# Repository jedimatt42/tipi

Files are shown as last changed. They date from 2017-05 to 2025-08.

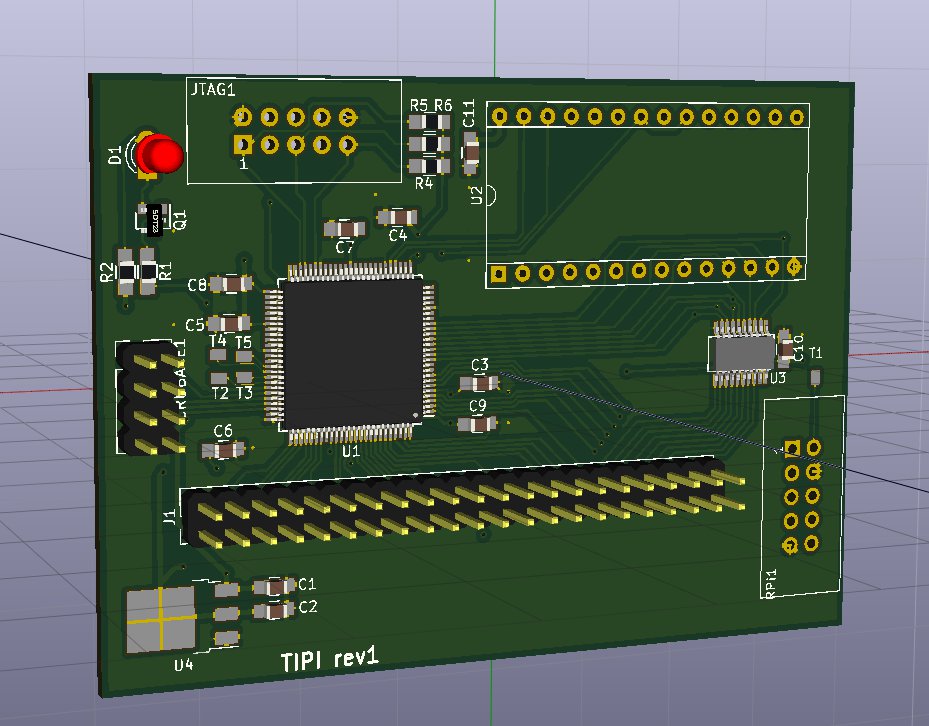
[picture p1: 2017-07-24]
hardware/tipi-sideport/kicad/pcboard.jpg

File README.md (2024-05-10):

# TIPI

(Pronounced tip-ee)

Turn a Raspberry PI and some glue hardware into a TI Disk Drive and Network interface. 

Keep it open for further device extension.

## Branching

(For end users starting from an SD card image, you are already on the correct branch)

- End users must be on one of the `_release` branches for physical TIPI
- `main` branch is full of stuff that doesn't work, won't upgrade correctly, and certainly won't downgrade
- `main` branch is expert mode only

Branches:

```
  main - current development for latest Raspberry PI OS
  bookworm_release - Current release branch based on Raspberry PI OS 12 - bookworm
  bullseye_release - (legacy) end of life, as new bookworm_release branch is available
  buster_dev - (legacy) for patching upstream of buster_release
  buster_release - (legacy) for Raspberry PI 2W - 4B+ or Qemu use.
```

## Documentation

Please refer to the [wiki](https://github.com/jedimatt42/tipi/wiki)

## License 

The hardware design files and TI-99 DSR ROM code are in the [hardware](hardware) folder and free for use under the [UNLICENSE.txt](hardware/UNLICENSE.txt) 

The remaining software contained in this repository are licensed under the terms of [GPLv3](https://www.gnu.org/licenses/quick-guide-gplv3.en.html)

These files are part of TIPI.

TIPI is free hardware design and software: you can redistribute it and/or modify it under the terms of the GNU General Public License as published by the Free Software Foundation, either version 3 of the License, or (at your option) any later version.

TIPI is distributed in the hope that it will be useful, but WITHOUT ANY WARRANTY; without even the implied warranty of MERCHANTABILITY or FITNESS FOR A PARTICULAR PURPOSE.  See the GNU General Public License for more details.

You should have received a copy of the GNU General Public License along with TIPI SD Card Image.  If not, see [GNU Licenses](http://www.gnu.org/licenses/).

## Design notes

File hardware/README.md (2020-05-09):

# Hardare design files for TIPI board and ROM driver software

This package below contains the hardware design files. These are un-encumbered open license files you can all do whatever you want with...

* tipi-peb - contains the PCB designs for the Periphal Expansion Box variant of the board. 
  * gerbers - artifacts for PCB fabrication
  * kicad - pcb schematic and layout design files for KiCad
  * ise - the verilog - Xilinx ISE 14.1 project files (use this with tipi-sideport design also)
* tipi-sideport - contains the PCB designs for the sideport board
  * gerbers - artifacts for PCB fabrication
  * kicad - pcb schematic and layout design files for KiCad
* tipi-speech - contains the PCB designs for the Speech Synthsizer Box variant of the TIPI board. 
  * gerbers - artifacts for PCB fabrication
  * kicad - pcb schematic and layout design files for KiCad
  * ise - the verilog - Xilinx ISE 14.1 project files (combined 32k and TIPI decoding)
* dsr - the ROM driver software for messaging to the PI and general DISK like behavior.

See [UNLICENSE.txt](UNLICENSE.txt)

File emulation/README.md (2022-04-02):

# TIPI support of popular emulators

TIPI is not an emulation of TI-99/4A hardware. It is a unique and independent implementation of storage, network, and other peripherals. Emulation in this context refers to TI-99/4A emulators that support TIPI features.

- js99er.net supports connecting to a running set of TIPI services either on a real Raspberry PI or through a QEMU based PI emulation running the real TIPI services.
- MAME v0.242 adds TIPI support: [Atariage MAME Release Thread](https://atariage.com/forums/topic/259551-new-mame-release/?do=findComment&comment=5032740)
- Classic99 implements some TIPI device and message level protocols directly. It is baked in. 

## Using QEMU

Run the emulation with the latest TIPI hardware sdimage.

1. Enable emulation mode, by running `/home/tipi/emulation/emu_config.sh` and responding to the prompts

2. Edit the `/etc/fstab` and delete the 3 TMPFS entries. The QEMU configuration does not have enough RAM for so much TMPFS usage.

3. Disable tipiwatchdog.service - it's not needed, and may crash since GPIO isn't actually available: `sudo systemctl disable tipiwatchdog.service`

4. exit the emulation clean: `sudo shutdown now`

### Options in the standard image that might need fixing

raspi-config should be run to change the locale, and 
keyboard defaults for the system

## Using a real PI

You can use a real PI, and the latest SD image. You will have to setup the networking following the Raspberry PI documentation: [headless network setup](https://www.raspberrypi.com/documentation/computers/configuration.html#setting-up-a-headless-raspberry-pi)

Be sure to touch the `ssh` file in the `boot` partition so sshd is enabled. Then you can get in and use raspi-config to setup locale, hostname, and other items.

Enable emulation mode, by running `/home/tipi/emulation/emu_config.sh` and responding to the prompts. On a real Raspberry PI, PDF conversion can be enabled, and you probably don't want tipi_disk mounted via NFS.

You should leave the tmpfs and other services as they are for a normal PI setup.

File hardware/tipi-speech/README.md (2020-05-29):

# Hardare design files for TIPI-32K board that fits in the Speech Synthesizer house and its unique CPLD code

This package below contains the hardware design files. These are un-encumbered open license files you can all do whatever you want with...

* kicad - contains the PCB designs for the sideport board
* gerbers - contains the PCB manufacturing files for this variant of the board. 
* ise - contains the Xilinx ISE 14.1 project CPLD design files and jedec output file this variant of the TIPI board. 

See [UNLICENSE.txt](UNLICENSE.txt)

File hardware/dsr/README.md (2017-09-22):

# DSR for TIPI

Right, now we have a very simple xdt99 based build system for creating a rom targetting >4000 that is comprised
of one or more .a99 source files. It produces tipi.bin, and the script bin2hex.py converts that to tipi.hex which
is a format that can be embedded/included in a verilog FPGA source file.

## Architecture

The code for the DSR is in two halves. TMS9900 assembly code (.a99 files) support the TI operating system by responding to
device PAB (Peripheral Access Block) requests. These are copied to the Raspberry PI through the hardware interface, and interpretted/handled by the python code. 

The Raspberry PI runs the 'TipiService.py' script as a systemd service. This script looks at the devicename, translates 
file names to matching local filesystem files, and supports OPEN, READ, CLOSE, and LOAD operations. SAVE, and WRITE are not implemented yet, as we work on stabilizing the hardware.

TipiPorts.py - low level interface to Raspberry PI GPIO pins.
TipiMessages.py - next level up, send or receive a bytearray
ti_files.py - utilities for validating the format of the hosted files, decoding the file meta-data, and extracting records
ti_names.py - translates TI names to host filesystem names. We ignore names in the TIFILES meta-data.
SpecialFiles.py - handles generation of psuedo files for read access like TIPI.CLOCK and TIPI.STATUS.
TipiService.py - the primary service script, that loops waiting for DSR requests. Opcode handling and Catalog handling is in here too.

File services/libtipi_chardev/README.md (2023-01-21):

# Native C to python interface for tipi via kernel module gpiod driver

Use /dev/tipi_control and /dev/tipi_data kernel module character devices to 
interact with TIPI adapter board for messaging.

Kernel module for your single board computer must already be installed.

# Building

```
virtualenv env
. env/bin/activate
pip install -r requirements.txt
python setup.py install
```

# Usage

TODO: Update with good info

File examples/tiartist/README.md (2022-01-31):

# TIPI TI Artist Plus Mouse Driver

This is a mouse driver to enable TIPI mouse with TI Artist Plus.

I don't know or expect it to be compatible with older versions of TI Artist.

## Finding TI Artist Plus

The version of TI Artist Plus I tested this with can be found here:

[whtech](http://ftp.whtech.com/graphics/Inscebot/)  in the disk image.

Extract as TIFILES into a folder on your TIPI named INSCEBOT.

Place the TIPIM file in the folder you extract the disk image into.
Copy aside EXTDSR to JOYST2 (it is different than existing JOYST)

Copy TIPIM to EXTDSR

Now Map DSK1 to the INSCEBOT folder. Plug a USB mouse into your
TIPI, and launch XB. 

## Usage

Left mouse button is fire-button. Rubber-banding is supported so for
tools except D-Draw, click and release, move to preview with rubber band, then click. For most cools, TI Artist warps you back to the
starting point on second click. 

Middle mouse button is space-menu. It activates on release of the button.

Right mouse button restricts movement to a single pixel, so in draw mode you'll never get gaps. But this is more of a throw-back UX compromise. You have to adjust how you move to get sweeping motions.

The speed will never be perfect, but it reminds me of back in the day. For best results use a low DPI mouse as you can find.

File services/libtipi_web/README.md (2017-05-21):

# Native C to python interface for tipi gpio

This library should encapsulate the GPIO routines required for interacting with the 
shift registers and data latches that are in the TIPI hardware, from the Raspberry PI
side of the interface. 

Using C instead of RPi.GPIO should be able to outpace the TI-99/4A, where the python
library is relatively slow. Benchmarks from 2015 showed RPi.GPIO operating at 70 Khz, 
where Native C operated at 22 Mhz. 

With the use of shift registers, we go from 8 IOs per byte to 28 IOs per byte. 
Consequently, the need for performance is real.

# Building

```
virtualenv env
. env/bin/activate
pip install -r requirements.txt
python setup.py install
```

# Usage

Example python usage of the library.

```
import tipiports

# initialize GPIO pins for TIPI
tipiports.initGpio()

# read control byte from TI
print tipiports.getTC()

# read data byte from TI
print tipiports.getTD()

# set data byte from RPi
tipiports.setRD()

# set control byte from RPi
tipiports.setRC()
```

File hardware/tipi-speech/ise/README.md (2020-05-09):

CPLD design files for VS-TIPI board 

This package below contains the CPLD design files. These are un-encumbered open license files you can all do whatever you want with...

           ise - the verilog - Xilinx ISE 14.1 project files (use this with VS-tipi design only)

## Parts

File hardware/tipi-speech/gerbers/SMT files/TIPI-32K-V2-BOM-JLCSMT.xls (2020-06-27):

Comment | Designator | Footprint | LCSC
10uf | C1 | 0805_C | C15850
22uf | C2 | 0805_C | C45783
0.1uf | C6,C10,C7,C8,C9,C5,C4,C3,C11,C12 | 0805_C | C49678
USB_B_Micro | J2 | AMPHENOL_10118194-0001LF | C132563
NPN_BCE | Q1 | SOT-23 | C31776
330R | R2 | 0805_R | C17630
1k | R3,R1 | 0805_R | C17513
10k | R5,R6,R4 | 0805_R | C17414
0R | R7 | 0805_R | C17477
XC95144XL-TQ100 | U1 | TQFP-100_14x14mm_Pitch0.5mm | C45126
74HCT245 | U3 | SSOP-20 | C5980
LM1117-3.3 | U4 | SOT-223 | C23984

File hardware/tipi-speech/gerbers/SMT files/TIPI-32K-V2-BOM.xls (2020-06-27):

TIPI-32K Rev 2 Bom | 2020-06-15
Comment | Designator | Footprint | LCSC | Qty | Cost | Ext. | Package | Description | Vendor | Primary Source | Alternate | LCSC
10uf | C1 | 0805_C | C15850 | 1 | $0.044 | $0.044 | SMT 0805_C | 10uf capacitor | JLCPCB or DigiKey | https://jlcpcb.com/parts/componentSearch?searchTxt=C15850 | https://www.digikey.com/product-detail/en/kemet/C0805C106K8PACTU/399-4925-1-ND/1090920 | C15850
22uf | C2 | 0805_C | C45783 | 1 | $0.158 | $0.158 | SMT 0805_C | 22uf capacitor | JLCPCB or DigiKey | https://jlcpcb.com/parts/componentSearch?searchTxt=C45783 | https://www.digikey.com/product-detail/en/samsung-electro-mechanics/CL21A226MOCLRNC/1276-6780-1-ND/5961639 | C45783
0.1uf | C5,C6,C8,C3,C4,C7,C9,C10,C11,C12 | 0805_C | C49678 | 10 | $0.012 | $0.123 | SMT 0805_C | 0.1uf capacitor | JLCPCB or DigiKey | https://jlcpcb.com/parts/componentSearch?searchTxt=C49678 | https://www.digikey.com/product-detail/en/avx-corporation/08055C104MAT2A/478-3351-1-ND/930143 | C49678
MMBT4401 | Q1 | SOT-23 | C31776 | 1 | $0.021 | $0.021 | SMT SOT-23 | MMBT4401LT1GOSCT-ND | JLCPCB or DigiKey | https://jlcpcb.com/parts/componentSearch?searchTxt=C31776 | https://www.digikey.com/product-detail/en/on-semiconductor/MMBT4401LT1G/MMBT4401LT1GOSCT-ND/1139819 | C31776
1k | R1,R3 | 0805_R | C17513 | 2 | $0.002 | $0.004 | SMT 0805_R | 1K resistor | JLCPCB or DigiKey | https://jlcpcb.com/parts/componentSearch?searchTxt=C17513 | https://www.digikey.com/product-detail/en/yageo/RC0805JR-071KL/311-1.0KARCT-ND/731165 | C17513
330 ohm | R2 | 0805_R | C17630 | 1 | $0.003 | $0.003 | SMT 0805_R | 330 Ohm resistor | JLCPCB or DigiKey | https://jlcpcb.com/parts/componentSearch?searchTxt=C17630 | https://www.digikey.com/product-detail/en/stackpole-electronics-inc/RMCF0805JT330R/RMCF0805JT330RCT-ND/1942547 | C17630
10k | R4,R5,R6 | 0805_R | C17414 | 3 | $0.009 | $0.027 | SMT 0805_R | 10K resistor | JLCPCB or DigiKey | https://jlcpcb.com/parts/componentSearch?searchTxt=C17414 | https://www.digikey.com/product-detail/en/yageo/RC0805JR-0710KL/311-10KARCT-ND/731188 | C17414
0 Ohm | R7 | 0805_R | C17477 | 1 | $0.009 | $0.009 | SMT 0805_R | 0 Ohm resistor | JLCPCB or DigiKey | https://jlcpcb.com/parts/componentSearch?searchTxt=C17477 | https://www.digikey.com/product-detail/en/yageo/RC0805JR-070RL/311-0-0ARCT-ND/731163 | C17477
XC95144XL | U1 | TQFP-100 | C45126 | 1 | $5.587 | $5.587 | SMT TQFP-100 14x14mm | XC95144XL-10TQG100C | JLCPCB or DigiKey | https://jlcpcb.com/parts/componentSearch?searchTxt=C45126 | https://www.digikey.com/product-detail/en/xilinx-inc/XC95144XL-10TQG100C/122-1372-ND/826975 | C45126
74HCT245 | U3 | TSSOP-20 | C5980 | 1 | $0.16 | $0.158 | SMT TSSOP-20 | 74HCT245PW | JLCPCB or DigiKey | https://jlcpcb.com/parts/componentSearch?searchTxt=C5980 | https://www.digikey.com/product-detail/en/nexperia-usa-inc/74HCT245PW,118/1727-6353-1-ND/2762864 | C5980
LM1117-3.3 | U4 | SOT-223 | C23984 | 1 | $0.480 | $0.480 | SMT SOT-223 | LM1117MPX-3.3/NOPB | JLCPCB or DigiKey | https://jlcpcb.com/parts/componentSearch?searchTxt=C23984 | https://www.digikey.com/product-detail/en/texas-instruments/LM1117MPX-3.3-NOPB/LM1117MPX-3.3-NOPBCT-ND/1010516 | C23984
 |  |  |  |  |  | $6.614 | SMT Parts Total (JLCPCB)
VS-Tipi.kicad_pcb | x-PCB |  |  | 1 | $0.830 | $0.830 | PCB 55 x 115 mm 2 layer | TIPI-32K-SS Raw PCB | JPLPCB or OshPark | https://jlcpcb.com//quote/gerberview/8dda1561-b2e0-43b6-8637-cdb665102ca1_1_0_1_0_0.html (https://jlcpcb.com/quote/gerberview/8dda1561-b2e0-43b6-8637-cdb665102ca1_1_0_1_0_0.html) |  | ;
 |  |  |  |  |  | $9.473 | SMT Populated CCA PCB Total |  | (Quoted at Qty 10 ~$10)
USB Micro socket | J2 | SMT USB Micro | C132563 | 1 | $0.290 | $0.290 | SMT USB Micro | Amphenol_10118194-0001LF‎ | DigiKey (jlcpcb won't smt) | https://www.digikey.com/product-detail/en/amphenol-icc-fci/10118194-0001LF/609-4618-1-ND/2785382 | https://lcsc.com/product-detail/USB-Connectors_Amphenol_10118194-0001LF_10118194-0001LF_C132563.html
LED_D3.0mm | D1 | Through Hole Hand Solder |  | 1 | $0.250 | $0.250 | LED 3.0mm | LED_ALT | DigiKey | https://www.digikey.com/product-detail/en/lite-on-inc/LTL-4221/160-1877-ND/3198524 | https://www.jameco.com/z/LHR2041-LED-Uni-Color-Red-660nm-2-Pin-T-1_206498.html
RPI_CONN_02X05 | RPi1 | Through Hole Hand Solder |  | 1 | $0.580 | $0.580 | Shrouded Headers 2x05 | CONN R/A 10POS | DigiKey | https://www.digikey.com/product-detail/en/cnc-tech/3020-10-0100-00/1175-1609-ND/3441723
CONN_02X04 | CRUBASE1 | Through Hole Hand Solder |  | 1 | $0.350 | $0.350 | Headers 2x04 | 02X04 header | DigiKey | https://www.digikey.com/product-detail/en/amphenol-fci/67996-408HLF/609-3391-ND/1487877
CONN_02X05 | JTAG1 | Through Hole Hand Solder |  | 1 | $0.280 | $0.280 | Headers 2x05 | 02X05 header | DigiKey | https://www.digikey.com/product-detail/en/amphenol-fci/67997-410HLF/609-3243-ND/1878475
CONN_01X02 | J3 | Through Hole Hand Solder |  | 1 | $0.280 | $0.280 | Headers 2x01 | 01X02 header | DigiKey | https://www.digikey.com/product-detail/en/amphenol-icc-fci/68000-102HLF/609-3500-ND/1493545
01x14 SIPsocket | U2a,U2b,U5a,U5b | Through Hole Hand Solder |  | 4 | $0.696 | $2.784 | Inline 14 pin sockets | 14 pin single row socket | DigiKey | https://www.digikey.com/product-detail/en/preci-dip/310-87-114-41-001101/1212-1101-ND/3757351 | https://www.jameco.com/webapp/wcs/stores/servlet/ProductDisplay?productId=175920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
AS6C62256-55PCN | U5 | Socketed Hand Inserted |  | 1 | $2.540 | $2.540 | DIP-28W | AS6C62256-55PCN | DigiKey | https://www.digikey.com/product-detail/en/alliance-memory-inc/AS6C62256-55PCN/1450-1033-ND/4234592 | https://www.jameco.com/z/CY62256L-70PC-Cypress-Semiconductor-SRAM-Chip-Asynchronous-Single-5-Volt-256k-Bit-32k-X-8-70ns-28-Pin-MDIP_391793.html
27C256 | U2 | Socketed Hand Inserted |  | 1 | $2.590 | $2.590 | DIP-28W | AM27C256 | eBay – hodge16 | https://www.ebay.com/itm/320526640071 | https://www.jameco.com/z/M27C256B-15F1-STMicroelectronics-IC-27C256B-15-EPROM-256K-Bit-150ns-UV-EPROM-and-OTP-EPROM_698111.html
TI-99_Sideport | J1 | Card Edge Hand Solder |  | 1 | $0.520 | $0.520 | 44 pin card edge connector | Card Edge Connector 44-pin | eBay – wonderco_buy | http://www.ebay.com/itm/5pc-Industrial-Card-Edge-Slot-Socket-Connector-22x2P-44P-2-54mm-0-1-3A-RoHS-/140888520037
 |  |  |  |  |  | $8.714 | DigiKey Parts Total
 |  |  |  |  |  | $9.894 | Hand-Placed Parts Total
 |  |  |  |  |  | $19.367 | Populated CCA Assembly BOM Cost
Pi Connector | Tall Board Connector for Pi ZeroW | Through Hole Hand Solder |  | 1 | $1.36 | $1.360 |  | ESW-105-23-T-D | DigiKey | https://www.digikey.com/product-detail/en/samtec-inc/ESW-105-23-T-D/SAM12534-ND/6692195 | https://www.digikey.com/product-detail/en/samtec-inc/ESW-105-12-G-D/SAM10467-ND/2651067
Raspberry Pi | Raspberry Pi ZeroW |  |  | 1 | $10.00 | $10.000 |  | DEV-14277 | Sparkfun/Adafruit/Canakit | https://www.sparkfun.com/products/14277 | https://www.canakit.com/raspberry-pi-zero-wireless.html
uSD card | 32GB micro SD card for Raspberry Pi |  |  | 1 | $5.64 | $5.640 |  | SDSDUNB-032G | Amazon | https://www.amazon.com/SanDisk-Ultra-UHS-I-Class-SDSDUNB-032G/dp/B07N16CDX3?rnid=2528832011
Housing | Speech Synthesizer Housing |  |  | 1 | $15.00 | $15.000 | (what I paid) | PHP1500 (used) | eBay | https://www.ebay.com/sch/i.html?_nkw=Ti%2099%204a%20Speech%20Synthesizer
 |  |  |  |  |  | $51.367 | Grand Total Bom Cost
 |  |  |  |  |  |  | * Does not include shipping

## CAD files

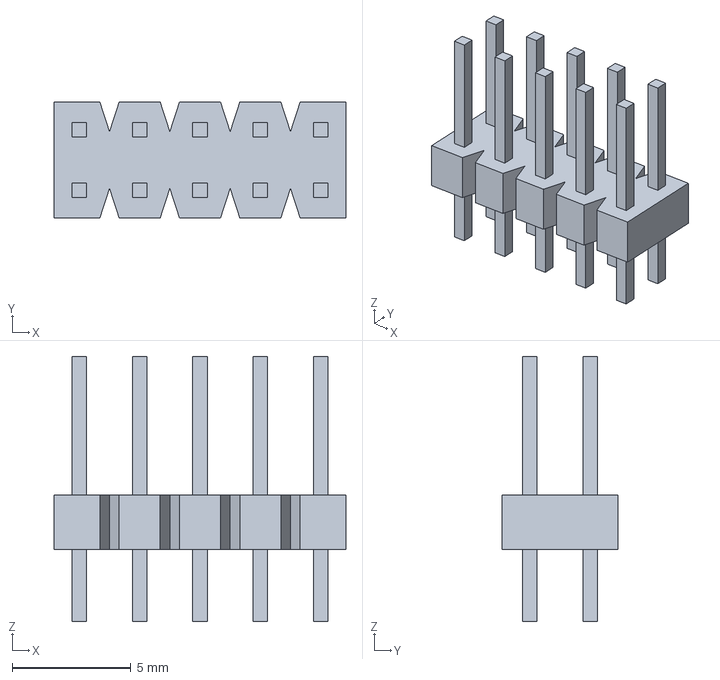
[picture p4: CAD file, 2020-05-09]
hardware/tipi-speech/kicad/3D/c-103186-5-g-3d.stp
12.3 x 4.88 x 11.2 mm

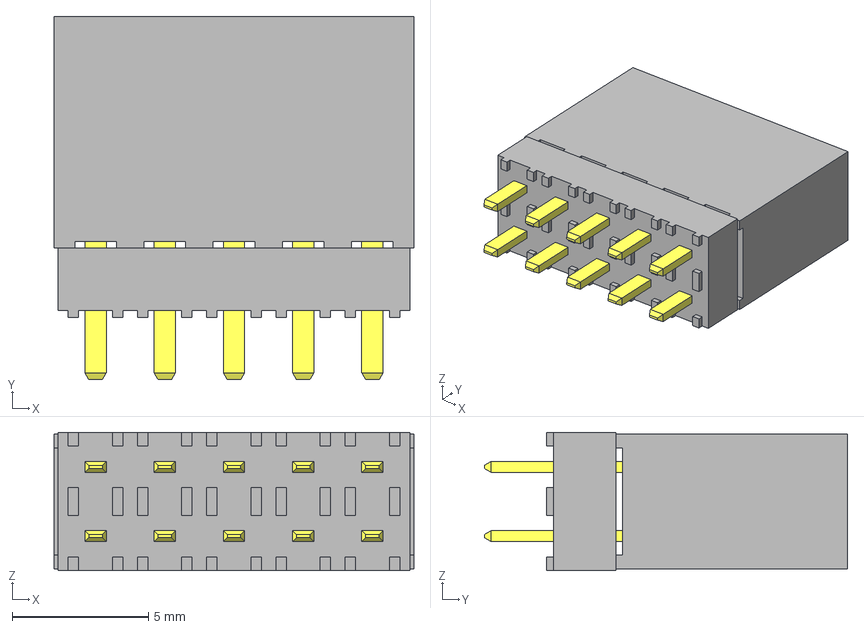
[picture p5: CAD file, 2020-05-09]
hardware/tipi-speech/kicad/3D/ESW-105-12-G-D.stp
13.2 x 13.3 x 5.08 mm
_ESW-105-12-G-D_socket
_ESW-105-12-G-D_pins
_ESW-105-12-G-D_bsocket

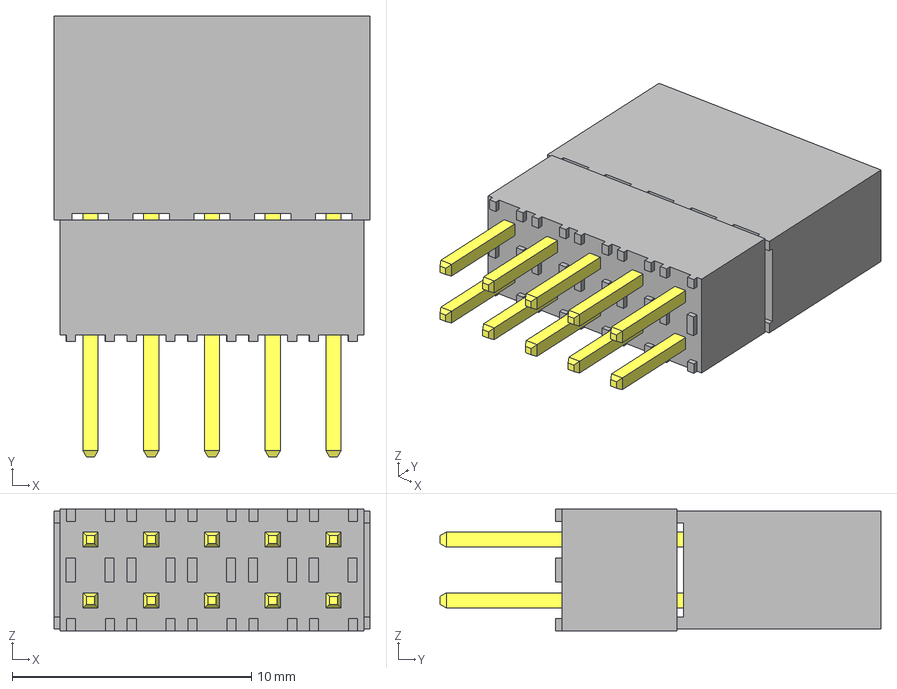
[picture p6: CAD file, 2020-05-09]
hardware/tipi-speech/kicad/3D/ESQ-105-23-G-D.stp
13.2 x 18.4 x 5.08 mm
_ESQ-105-23-G-D_socket
_ESQ-105-23-G-D_pins
_ESQ-105-23-G-D-LL_bpins

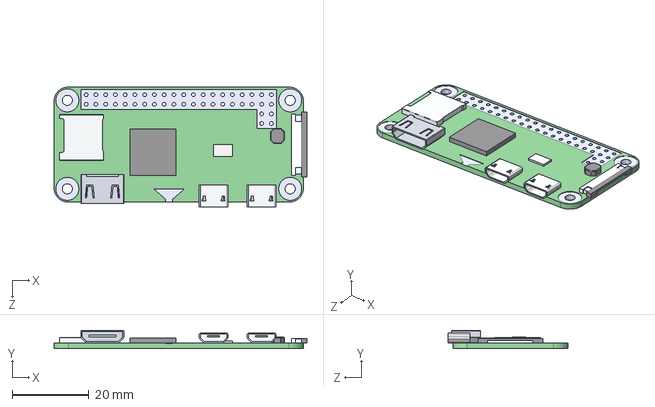
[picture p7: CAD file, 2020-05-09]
hardware/tipi-speech/kicad/3D/RaspberryPiZeroW.IGS
65.9 x 4.80 x 31.3 mm

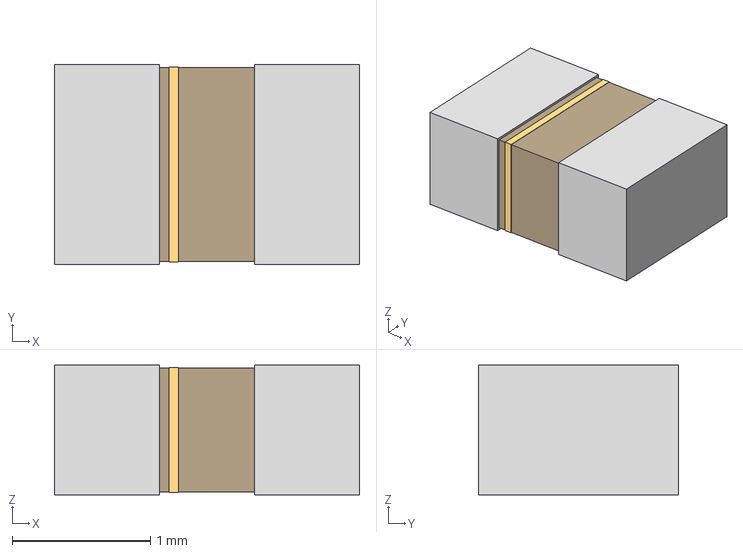
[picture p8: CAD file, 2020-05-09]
hardware/tipi-speech/kicad/3D/CAP_0805J_AVX.step
2.21 x 1.45 x 0.94 mm

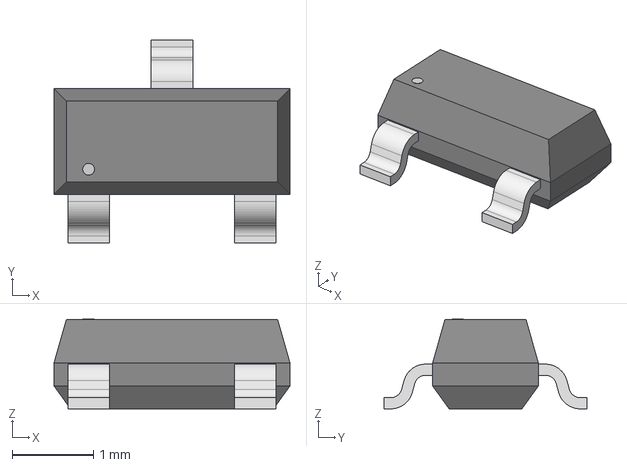
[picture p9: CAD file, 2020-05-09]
hardware/tipi-speech/kicad/3D/SOT-23_DIO-L.step
2.90 x 2.50 x 1.10 mm

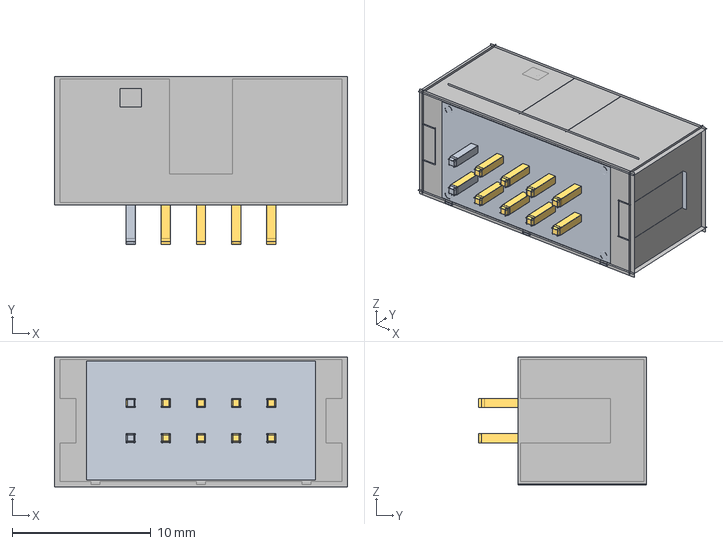
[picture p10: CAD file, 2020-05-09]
hardware/tipi-speech/kicad/3D/3020-10-0100-xx.igs
21.1 x 12.1 x 9.36 mm

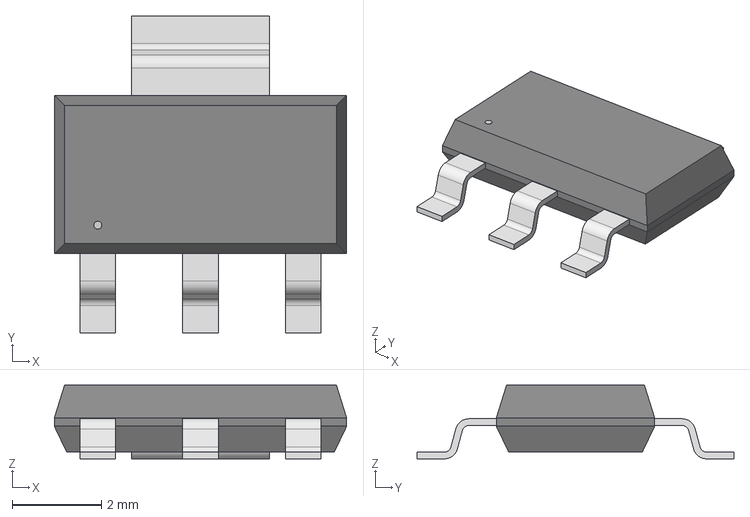
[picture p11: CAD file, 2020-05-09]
hardware/tipi-speech/kicad/3D/SOT-223_DIO.step
6.55 x 7.10 x 1.65 mm

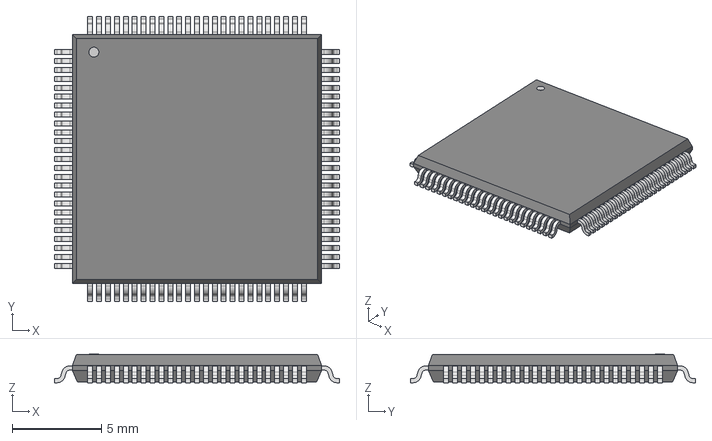
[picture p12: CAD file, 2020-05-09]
hardware/tipi-speech/kicad/3D/100-TQFP.step
16.0 x 16.0 x 1.60 mm

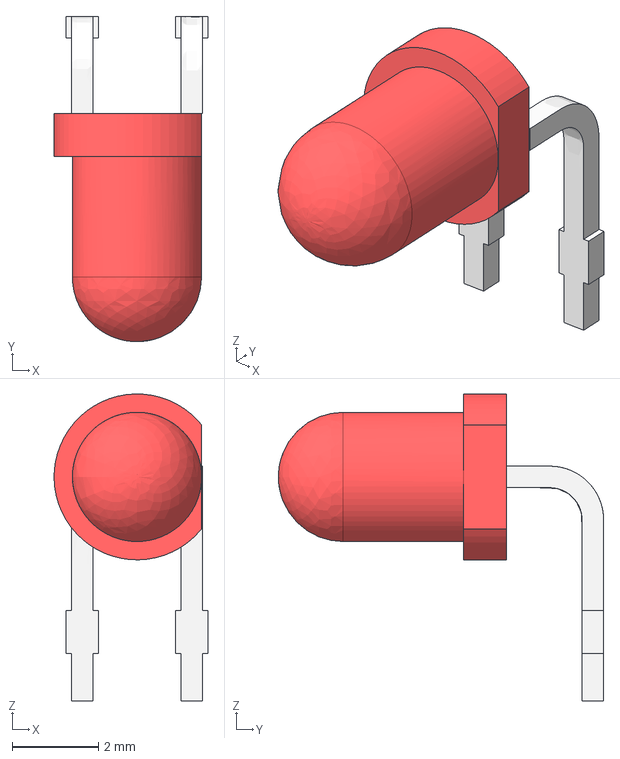
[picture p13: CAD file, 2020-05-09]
hardware/tipi-speech/kicad/3D/LED 3mm, Red, Thru-hole, Right Angle PCB 2.stp
3.57 x 7.55 x 7.12 mm

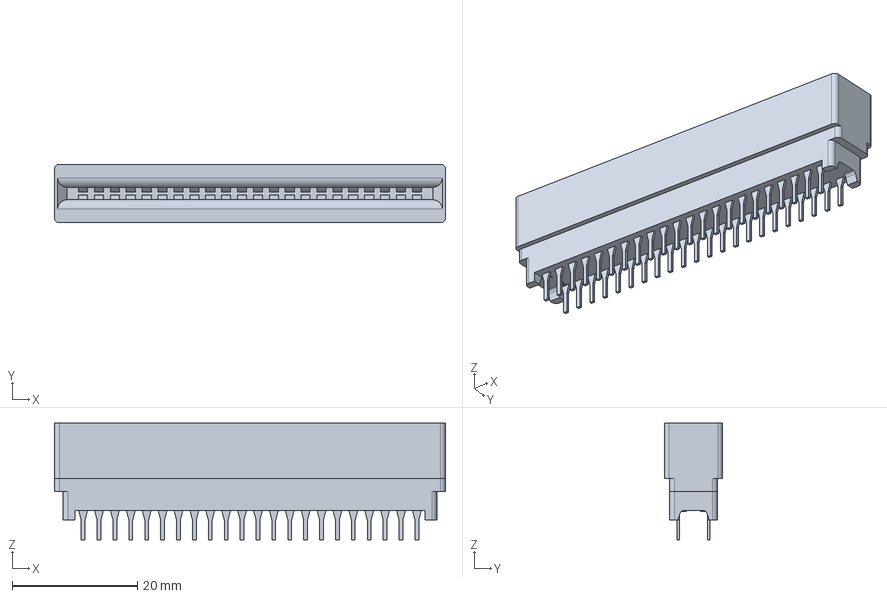
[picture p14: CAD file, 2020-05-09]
hardware/tipi-speech/kicad/3D/c-5530843-4-f-3d.stp
62.5 x 9.35 x 18.7 mm

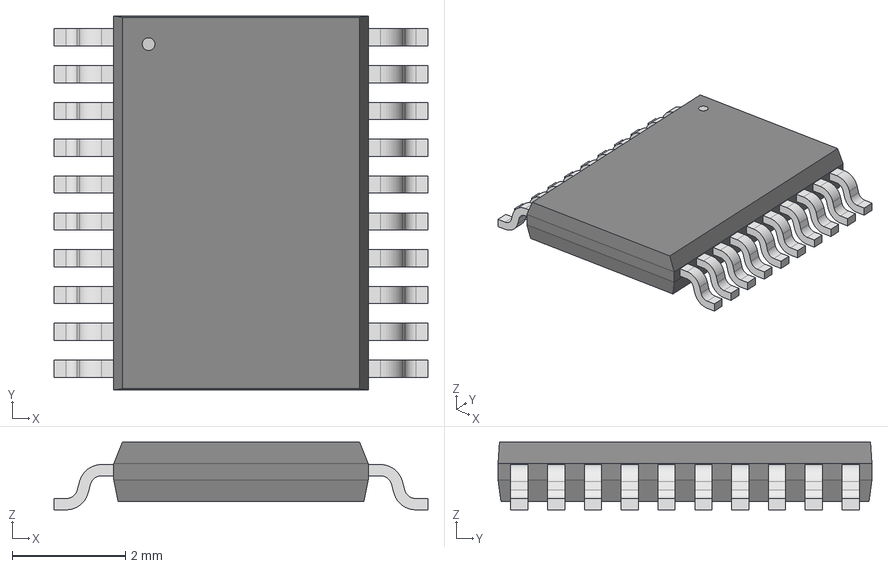
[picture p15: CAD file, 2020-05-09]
hardware/tipi-speech/kicad/3D/PW20.step
6.60 x 6.60 x 1.20 mm

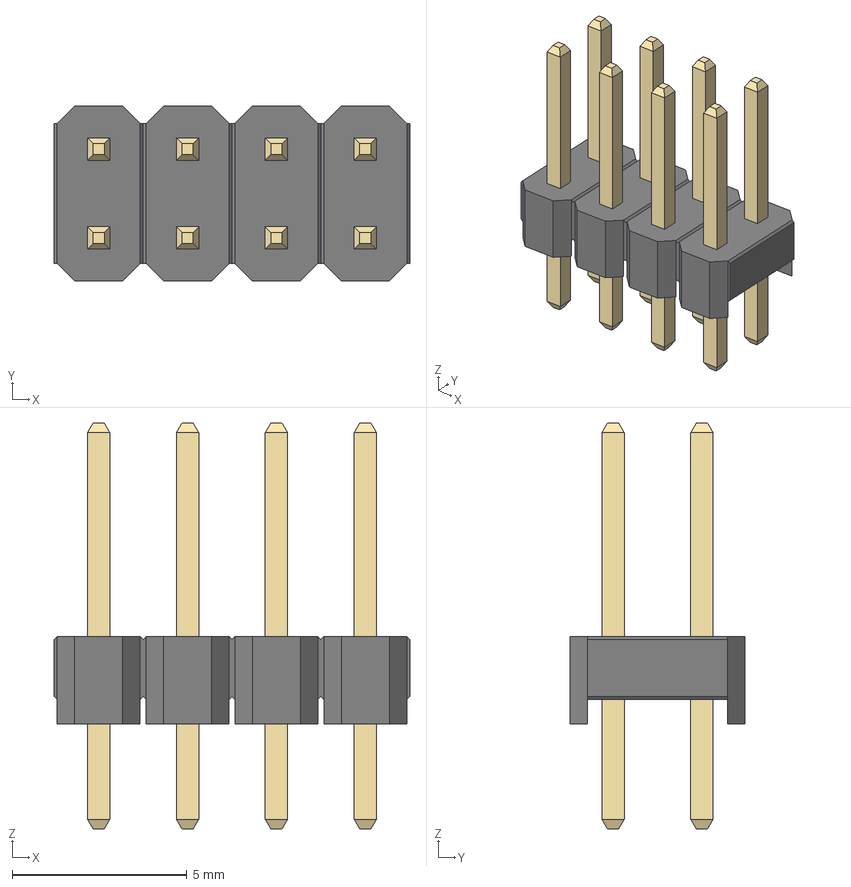
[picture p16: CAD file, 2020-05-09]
hardware/tipi-speech/kicad/3D/DS1021-2x4SF11.stp
10.2 x 5.00 x 11.6 mm

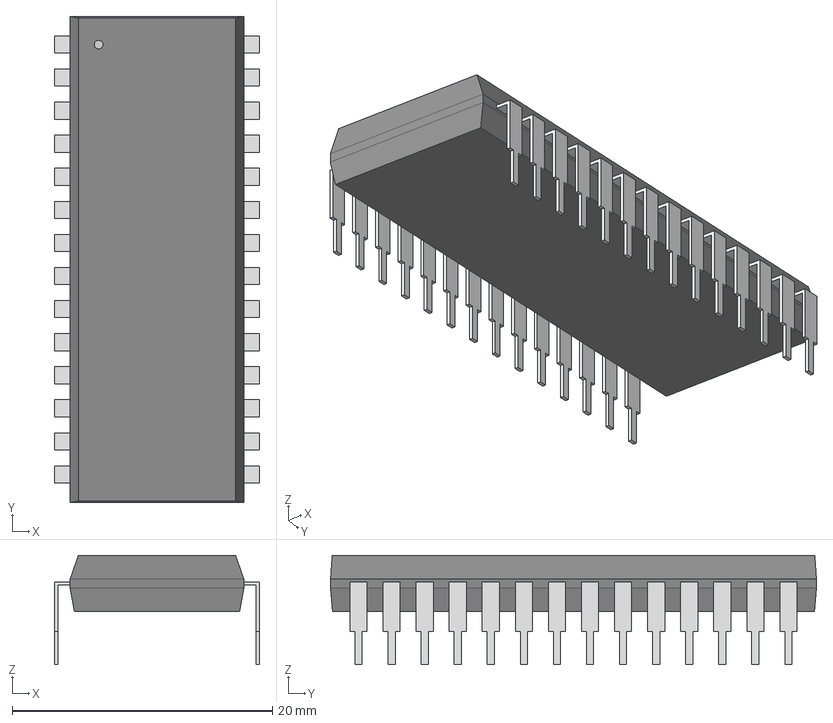
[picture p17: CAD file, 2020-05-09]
hardware/tipi-speech/kicad/3D/FDIP28WB.step
15.7 x 37.3 x 8.38 mm

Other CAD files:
hardware/tipi-speech/kicad/3D/10-Pin Shrouded Header (IDC) Straight.stp
hardware/tipi-speech/kicad/3D/DS1021-2x5SF11.stp
hardware/tipi-speech/kicad/3D/RC0805N.step
hardware/tipi-speech/kicad/3D/67996-408HLF_AMP.step
hardware/tipi-speech/kicad/3D/10118194c.stp
hardware/tipi-speech/kicad/3D/87215-5.step

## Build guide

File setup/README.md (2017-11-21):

# Services and setup

This folder contains the systemd service definitions and scripts around service
setup, and upgrade.

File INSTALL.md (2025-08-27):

# Setting up...

## If using the SD-Card image the steps in this document have already been performed.

SD Card image is available for download: 

[www.jedimatt42.com](https://www.jedimatt42.com/downloads.html)

Go to the [Wiki](https://github.com/jedimatt42/tipi/wiki) for end user installation.

# Only follow these instructions if you are setting up an SD Card from scratch.

Assumes base image is Raspbian Lite (bookworm)

## Pre-boot setup

Before booting the Raspbian SD image, create a createuser.txt, enable ssh, enable wifi by
following the instructions from [raspberrypi.com](https://raspberrypi.com/documentation/computers/configuration.html#setting-up-a-headless-raspberry-pi)
The user you create should be named: tipi
The tipi user password should be: tipi

Use raspi-config to install locales and set default, en_US_utf8.
Note: installing all locales takes forever, and slows future updates.
install en-US-UTF8, en-GB-UTF8, de-DE-UTF8, and en-CA-UTF8

Use raspi-config to disable i2c so that gpio-shutdown can be enabled.

Use raspi-config to enable ssh, and grow the root filesystem.
reboot.

## Replace log and tmp folders with tmpfs to prolong SD card life

Add the following to /etc/fstab:

```
tmpfs    /tmp    tmpfs    defaults,noatime,nosuid,size=100m    0 0
tmpfs    /var/log    tmpfs    defaults,noatime,nosuid,mode=0755,size=100m    0 0
```

Cleanup files under those subdirectories, and mount the tmpfs filesystems.

```
sudo rm -r /tmp/*
sudo rm -r /var/log/*
```

Reboot

```
sudo reboot now
```

## Install Software

Make sure git is installed (after setting up tmpfs folders, update will be required)

```
sudo apt update
sudo apt upgrade
sudo apt install git
```

## Install services

Setup the services, by becoming the 'tipi' user, cloning the git repository 
within the 'tipi' user home directory, and running the setup.sh script.

While executing the following, when prompted for a 'sudo' password, it 
is for the 'tipi' user.

Install the tipi kernel module

```
cd /home/tipi
git clone https://github.com/jedimatt42/tipi_kernel_module.git
cd tipi_kernel_module
sudo apt install raspberrypi-kernel-headers
./build.sh
sudo ./install.sh
sudo reboot now
```

NOTE: The ./install.sh step will fail to copy the overlay on a Le Potato
      Check the Le Potato section of the tipi_kernel_module/README.md 

Install the tipi services

```
cd /home/tipi
git clone https://github.com/jedimatt42/tipi.git tipi
cd /home/tipi/tipi
git checkout bookworm_release
git submodule update --init
./setup.sh
```

And run the post-upgrade to finish all the incremental configuration

```
cd setup
sudo ./post-upgrade.sh
```

NOTE: On Le Potato some parts of post-upgrade do not work. Completely...

## Other items to setup

* add tipi account to samba, and set password to 'tipi'

```
sudo smbpasswd -a tipi
```

* change the hostname (raspi-config)

Use raspi-config to set hostname to: `tipi`

## Test WIFI Connectivity

Make sure wifi was working before archiving the image. 

## Disable apache2.service

I don't know why this keeps coming back... but disable it as it fails to start and is 
not used.

```
sudo systemctl disable apache2.service
```

### Set the system to grow on boot

-- To be nice, set the image to resize on next boot 

edit the cmdline.txt in boot. Place the following at the end:
```
init=/usr/lib/raspi-config/init_resize.sh
```

Don't reboot, just shutdown.

### Capture SD Card Image

On a linux system dump the sdcard to an image. Then mount the image and clear unused blocks before zipping.

run dmesg to see what device sd card mounted as... presuming it was /dev/sdb:

```
sudo dd status=progress if=/dev/sdb of=sdimage.img bs=4M
sudo kpartx -a sdimage.img
```

You should be able to now mount the rootfs, or /dev/mapper/loop??p2.  On ubuntu like desktops the volume names will show up in the UI for removable media... 

Edit and Remove personal settings found in
- /home/tipi/tipi.config
- /etc/wpa_supplicant/wpa_supplicant.conf
- /home/tipi/.ssh/*

Then clear the space:

```
cd /media/`whoami`/rootfs
sudo dd status=progress if=/dev/zero of=zeroes bs=4M
sudo sync
sudo rm zeroes
cd
umount /media/`whoami`/rootfs
sudo kpartx -d sdimage.img
```

Now zip it up!

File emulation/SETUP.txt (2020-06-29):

== TIPI For Emulation

This bundle allows using js99er.net TI-99/4A emulation
with an emulated Raspberry PI running the TIPI 
peripheral services.

=== Setup

Download and install QEMU:

* https://www.qemu.org/download/#windows

1: Run nfs_tipi_disk.bat to start NFS server
2: Run tipi-qemu.bat to start TIPI emulation

=== NFS is optional

If you want your TIFILES to live in the tipi_disk folder on your
host operating system, run the nfs_tipi_disk.bat. This will start
WinNfsd.exe and export the .\tipi_disk folder as the nfs mount
localhost:/tipi_disk

When the emulation starts up, the default TIPI support programs
TELNET and TIPICFG will be installed into that folder.

If wish to leave the tipi_disk inside the sd_image, do nothing.
That is the default.. you can still use the web ui at localhost:9900 
to manage your TIFILES.

=== SSH

If you don't like the QEMU terminal, you can SSH in via localhost:9922
as the user 'tipi' password 'tipi'

That means you can also use scp and sftp clients to manage files.

=== Shutdown

use good linux shutdown practices:

command line: sudo shutdown now
TIPI web-ui: there is a shutdown item in the left most menu
4A/emulation: CALL TIPI from basic, 'h' to halt the PI

wait a bit... on the QEMU console you'll see an indication that
halt failed. ( that means it is done, but the hardware can't power off )
you can then just close the window.

=== The Bad News

PI.PIO has been reduced so it doesn't fail. It will produce .prn files in 
the PI emulations /tmp directory. However, the PDF conversion just crashes
out.. so this has been disabled. 

== Recognition

Big thanks to PeteE of Atariage for reducing the TIPI hardware to a
web-socket. 

Equally large thanks to Asmusr of Atariage for js99er and the integration work.

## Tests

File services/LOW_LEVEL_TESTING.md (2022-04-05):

# Low Level Testing

on the raspberry pi stop the tipi and tipiwatchdog services:

```
sudo systemctl stop tipi.service
sudo systemctl stop tipiwatchdog.service
```

go to the tipi services folder and enter into the virtual env:

```
cd ~/tipi/services
. ENV/bin/activate
```

Boot your 4A/Geneve and go to MiniMem and enter Easy Bug

Then on the PI start the diagnostic tool:

```
export TIPI_SIG_DELAY=100
python TipiDebug.py
```

It will print out that it is setting some addresses on the TI
to specific values.

It then loops every 5 seconds and prints the values of memory
addresses it can read from the TI.

Check those addresses in EasyBug. If your crubase is >1000:

At the '?' prompt enter the cru command: 'C1000' and press enter.
then enter '1', and '.', the transcript will look like:
(you might want C1100 or whatever crubase your TIPI is set to)

```
?C1000
 C1000  =00  -> 1
 C1001  =01  -> .
```

Now, investigate the values set by the PI test tool:
Enter "M5FF9" and press enter 4 times. Transcript:

```
?M5FF9
 M5FF9  = 5A  ->
 M5FFA  = 00  ->
 M5FFB  = A5  ->
 M5FFC  = 00  ->
```

The tool should be printing on the PI the output of the 
addresses 5FFD and 5FFF, so go down to 5FFD by pressing
enter again, and then set the value to '81', enter again
to skip to 5FFF, and set the value to 'FF'

Transcript in Easy bug will look like:

```
 M5FFD  =00  -> 81
 M5FFE  =00  ->
 M5FFF  =00  -> FF
 M6000  =AA  ->
```

On the PI you should see your 81 and FF values show up.

Likely output on the PI will look like (if it's working)

```
wrote M5FF9: 0x5A, M5FFB: 0xA5
read M5FFD: 0x00, M5FFF: 0x0
...
read M5FFD: 0x81, M5FFF: 0xff
...
```

This is as low as we can go without a signal analyzer.

If you get some muddled values back, you can try 
increasing the value of TIPI_SIG_DELAY and rerun
the script.

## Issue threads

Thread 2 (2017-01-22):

Revision 4 schematic A3 should always be 1.

jedimatt42, 2017-01-22:
The comparator is wired to A3-A6, but it should be A4-A7. And in cru selection, A3 must be HIGH.

jedimatt42, 2017-01-22:
fixed in master - #3

Closed 2017-01-22.

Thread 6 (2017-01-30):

Xc9500 schematic DSR rom addressing is backwards

jedimatt42, 2017-01-30:
The address line hook up to the rom is not right.

A0 on rom is LSb, should be ti A15. Banking lines should be rom A13 and A14

-M@

jedimatt42, 2017-02-05:
Fixed in master.

Closed 2017-02-05.

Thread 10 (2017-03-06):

Reset switch

jedimatt42, 2017-03-06:
There should be a soft reset for the TI related services on the RPi, controlled by one of the GPIO pins.

The 4A could also trigger this with a powerup routine so things are in known state with every reboot.

jedimatt42, 2017-04-22:
For development, I had the reset triggered on the TI RESET* signal, but it wasn't stable on my breadboard.

So I disconnected that, and used a physical button instead.
In the final design, a crubit should also drive this RPi signal so we can trigger the reset in the TI power up routine.

jedimatt42, 2017-05-16:
Done

Closed 2017-05-16.

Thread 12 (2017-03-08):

We can reduce the output pins to the RPI as by using a register select.

jedimatt42, 2017-03-08:
The RPi side doesn't need 16 GPIO pins dedicated to reading 2 8-bit registers. We can reduce the number of pins on the target CPLD and leave pins open on the RPi.

Use 1 register select pin, if HIGH, the TI Data register is selected, if LOW the TI Control register is selected. then 8 pins for the parallel output of the register.

That's a 7 pin reduction.

jedimatt42, 2017-04-22:
This worked like a champ!

Closed 2017-04-22.

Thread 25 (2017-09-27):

EMPTY DV80 file is not cataloged.

jedimatt42, 2017-09-27:
[EMPTY.zip](https://github.com/jedimatt42/tipi/files/1335814/EMPTY.zip)

The attached file contains a DV80 file with zero records... created by:
$ touch empty.txt
$ xdm99.py -T empty.txt -f "DIS/VAR80" -n EMPTY -o EMPTY

I can successfully load it into editor/assembler (Fred Kaal's EA5) but the CatalogFile is omitting it... I must have broken something.

jedimatt42, 2017-09-30:
Fixed... > 128 should have been >= 128... a header with no data is a valid TIFILES file

Closed 2017-09-30.

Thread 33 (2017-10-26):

tipi.service can't access some resources

ElectricLab, 2017-10-26:
The latest version of tipi.service has tipi.sh running as user: tipi. Is this correct? If so, did you chmod the following devices to be readable/writeable by the tipi user:
/dev/mem
/dev/gpiomem
Or maybe you addded 'tipi' to kmem and gpio groups?
The service won't start otherwise.

jedimatt42, 2017-10-26:
I added the tipi user to the gpio group as noted in https://github.com/jedimatt42/tipi/blob/master/dsr/python/README.md

the tipi user is only in the groups:
  tipi
  i2c
  input
  gpio

ElectricLab, 2017-10-26:
Ok - I guess I didn't read that README.md.
When I ran tipi.sh as the tipi user, I got:
/home/tipi/tipi/dsr/python/tipi.sh
wiringPiSetup: Unable to open /dev/mem or /dev/gpiomem: Permission denied.

The permissions on those devices are:
crw-r----- 1 root kmem 1, 1 Oct 25 22:09 /dev/mem
crw-rw---- 1 root gpio 243, 0 Oct 25 22:09 /dev/gpiomem

So it makes sense that adding tipi to gpio works, but not sure about /dev/mem.

jedimatt42, 2017-10-29:
you shouldn't need access to /dev/mem   because we are using /dev/gpiomem.  The error message is offering alternatives.

jedimatt42, 2017-11-18:
I take Pete's testing to show that this is all cleared up.

Closed 2017-11-18.

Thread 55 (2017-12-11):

WEB UI About box needs details

jedimatt42, 2017-12-11:
Should show Current and Latest version information from output of  /home/tipi/tipi/services/setup/upgrade.sh

Should show attribution:

Includes Ralph Benzinger's xdt99 suite  - https://github.com/endlos99/xdt99/blob/master/COPYING
Based on the Raspberry PI Raspbian Lite image - https://www.raspberrypi.org/downloads/raspbian/

jedimatt42, 2018-02-11:
fixed... shows current info and links to license on github which contains attribution details

Closed 2018-02-11.

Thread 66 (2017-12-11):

DSK?_DIR should represent the volume name somehow

jedimatt42, 2017-12-11:
DEADLINE loader expects and validates the volume name of the disk...

Suggestion is that the last part of the path name should be reported as the volume name when directories are mapped to DSK?_DIR entries.

arcadeshopper, 2017-12-11:
either that or set it in a file in the directory if that's easier.. like .VOLNAME or something

jedimatt42, 2017-12-25:
TIPI.anthing.more.whatever  volume name will be TIPI
DSK0.anything.more.whatever volume name will be TIPI
DSK1.anything... volume name will be basename of directory DSK1_DIR is mapped to:
So, if DSK1_DIR=GAMES.DEADLINE, then DSK1 volume name will be DEADLINE
In this case, DSK1.SAVES. volume name would still be DEADLINE. Meaning volume name will be tied to the drive mapping, not the directory you currently listing.

Closed 2017-12-25.

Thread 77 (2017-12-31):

Loading TIPI.TIPICFG hangs the TI for a few folks.

jedimatt42, 2017-12-31:
Greg said he wasn't patient enough...
Leonard said it hung, and then after a reboot of the 4a it was fine.

jedimatt42, 2018-04-01:
We have seen a hang as recent as Mar 29th 2018.

Hangs today seem to be due to noise on the lines connecting the PI to the TIPI board.  I don't have a good solution for this.

We have added a parity bit to the communication protocol that should retry if a single bit ( or odd number of bits ) error occurs.  This fixed all errors for me in my 'clean' environment.

Next, Greg still had lots of errors.. But eliminating / trading speech synthesizers, removed most.

Third, we lowered the transfer rate from 8k/sec to 6k/sec.  48000bps equivalent.  This has solved the issue in Greg's 'noisy' environment.

How 'clean' and how 'noisy' are not really known... It was not measured.   PI-Zero-W with a more direct link to the back of the TIPI board show results consistent with this theory, having a much shorter signal line, and being slower, we don't see noise related errors.

jedimatt42, 2018-05-29:
field testing hasn't shown any concern over this. And now we have a couple technical tuning options.

Closed 2018-05-29.

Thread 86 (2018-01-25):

when editing a text file on the ti, changes aren't written to the file completely

arcadeshopper, 2018-01-25:
using ea editor and preditor both i removed 50 lines from a text file and saved it only to find the lines still there on the file.. my specific line changes seemed to save at the top, but the erased lines did not

jedimatt42, 2018-01-26:
That's a cool bug! We could have gone years without noticing that.

arcadeshopper, 2018-01-26:
additional info, when editing a file with ea editor it seems to add a bunch of garbage to the eof as well I just "saved as" auto-bat2 with my shortened file, that worked fine.. then i edited it to switch the order of events and got this after saving:
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

jedimatt42, 2018-02-11:
fixed

arcadeshopper, 2018-02-12:
still getting the same garbage in the file as above

Closed 2018-02-11.

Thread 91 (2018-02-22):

in xb call load("DSK.THE_VALLEY.FILENAME") gives an error 00

arcadeshopper, 2018-02-22:
program is here: http://www.stuartconner.me.uk/ti/ti.htm#the_valley

works fine for old and run commands but not call load
¯\_(ツ)_/¯

jedimatt42, 2018-02-23:
call load works fine... but in this game, the file is a v9t9 file, and when extracted from disk image to host filesystem it is being named VALLEY(UPPERBAR)O. The software is trying to load VALLEY/O

Now, the host filesystem is where the name is... TIPI does not look in headers for names, so you don't have that confusion... once forget what you know about PC99 or V9T9.  If you rename a file that is the name it has.

The only exception to that is / and \  characters are allowed in TI names, but not allowed on the host filesystem... so to create a file on the host file system that can be found by TI looking for a /, use a '.'  (period)   so in this case, name the file VALLEY.O

I'll keep this open though, because... my goal is that when you upload a V9T9 file through the webui, it fixes this for you automatically.

---

I experience another problem running this game after it loads the assembly object file.  "STRING TRUNCATED IN 16030"  which is I think assembly code also embedded in the XB "RUN" program file.

jedimatt42, 2020-07-23:
When the disk extracts, it names the files correctly now.

jedimatt42, 2020-07-23:
The game actually works from TIPI, if the TIPI crubase is >1100 ( emulating floppy ) --- so the call files routine must be required.

Closed 2020-07-23.

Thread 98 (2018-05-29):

TELNET cursor in 64 column mode is broken.

jedimatt42, 2018-05-29:
Reading the character from the VDP isn't going to work in bitmap mode.

docbain, 2021-07-07:
I installed Raspberry Pi 4 to my TI using the PEB card set at CRU >1000. It connects to my network with IP address, however, when I attempt to CALL TIPI("TIPI.NET.TELNET"), my TI returns to the logo screen. What am I doing wrong. Also, there is a 10 pin connector on the card identical to the connector on the rear of the TIPI PEB card. Can this connector be used to connect the Raspberry PI, or just the rear connector? Thank you.

jedimatt42, 2021-07-07:
> I installed Raspberry Pi 4 to my TI using the PEB card set at CRU >1000. It connects to my network with IP address, however, when I attempt to CALL TIPI("TIPI.NET.TELNET"), my TI returns to the logo screen. What am I doing wrong. Also, there is a 10 pin connector on the card identical to the connector on the rear of the TIPI PEB card. Can this connector be used to connect the Raspberry PI, or just the rear connector? Thank you.

1st: this has nothing to do with the issue of the telnet cursor...
2nd: this isn't a support channel... you go over here: https://atariage.com/forums/topic/277635-tipi-usage-and-support/  I receive 0% from sales of TIPI -
3rd: The 2 ports you speak of are far from identical. one is labelled RPI1 and the other is labelled JTAG1   -- this question was recently answered over here: https://atariage.com/forums/topic/277635-tipi-usage-and-support/

Your initial question of what's wrong will take some back and forth. So you can read some troubleshooting tips on the TIPI wiki

https://github.com/jedimatt42/tipi/wiki

and if that doesn't give you the answers you need, go to https://atariage.com/forums/topic/277635-tipi-usage-and-support/ and your vendor or the community may help you diagnose the problem.

possible causes of that crash back to title screen could be:

* faulty memory expansion.
* missing TIPI.NET.TELNEU, as an EA5 program, it is split into 8k chunks, failure to find the second chunk in CALL TIPI, crashes to title screen.
* possibly bad cabling between TIPI and PI. Although this usually causes a hang or wild crash/lockup.

jedimatt42, 2021-07-07:
I have no intention of fixing the 64 column text mode cursor... so I'm closing this issue.

Closed 2021-07-07.

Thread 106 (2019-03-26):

TIPI doesn't work on Geneve 9640

jedimatt42, 2019-03-26:
It works on my own GENMOD Geneve, but doesn't work on stock Geneve.

- [x] Diagnose how broken with Greg
- [x] Get test Geneve setup
- [x] Build a test cartridge image
- [x] Try CPLD changes:
  - [x] WE* enables LED (passes if tested correctly)
  - [x] ~~No WE* signal on TIPI board? How does ANYTHING else work?~~
  - [x] MEMEN* enables LED
  - [x] WE* AND MEMEN* enabled LED
  - [x] ... AND LATCH_ADDR enables LED
  - [x] Try 0x5FFE instead of 0x5FFF for latch data
- [ ] ~~learn how to use a logic analyzer~~
- [x] take a lucky guess
- [ ] ~~map out the timing diagrams for read and write in DSR space~~
- [x] did I learn anything?
- [x] fix and publish, or give up, announce that I will not continue to pursue compatibility.

Closed 2019-03-30.

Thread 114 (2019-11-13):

error 07 when requesting https: site in xb

arcadeshopper, 2019-11-13:
2019-11-12 16:24:35,420 Pab         : INFO     opcode: Open, fileType: Sequential, mode: Input, dataType: Display, recordType: Variable, recordLength: 128, recordNumber: 0
2019-11-12 16:24:35,421 CurlFile    : INFO     open devname - PI.https://tgftp.nws.noaa.gov/data/observations/metar/decoded/KPDX.TXT
2019-11-12 16:24:35,422 CurlFile    : INFO     url: https://tgftp.nws.noaa.gov/data/observations/metar/decoded/KPDX.TXT
2019-11-12 16:24:35,423 CurlFile    : INFO     cmd: wget -O /tmp/CF https://tgftp.nws.noaa.gov/data/observations/metar/decoded/KPDX.TXT
2019-11-12 16:24:35,946 ti_files.NativeFile: ERROR    not a valid NativeFile /tmp/CF
Traceback (most recent call last):
  File "/home/tipi/tipi/services/ti_files/NativeFile.py", line 32, in load
    raise Exception("Incompatible recordlength")
Exception: Incompatible recordlength
2019-11-12 16:24:35,947 CurlFile    : ERROR    failed
Traceback (most recent call last):
  File "/home/tipi/tipi/services/CurlFile.py", line 60, in open
    file = self.fetch(url, pab)
  File "/home/tipi/tipi/services/CurlFile.py", line 174, in fetch
    return NativeFile.load(tmpname, pab, url)
  File "/home/tipi/tipi/services/ti_files/NativeFile.py", line 32, in load
    raise Exception("Incompatible recordlength")
Exception: Incompatible recordlength

xbcode opens file as input, variable 254 also tried 128

jedimatt42, 2020-07-23:
10 OPEN #1:"PI.HTTPS://tgftp.nws.noaa.gov/data/observations/metar/decoded/KPDX.TXT",INPUT, VARIABLE 254
20 INPUT #1:A$
30 PRINT A$
40 GOTO 20

The above works...

also no record length works, giving 80... and tested 10, which just cuts lines short per a separate issue that is filed...

Closed 2020-07-23.

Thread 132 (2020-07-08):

PI Zero W seems to be incompatible intermittently

jedimatt42, 2020-07-08:
Lots of people reporting a CRUBASE 2000 error.. which just means the PI.STATUS didn't load...

Seems to be - unknown
(best guess right now is load or power on the PI)

jedimatt42, 2020-07-14:
Fixed by Peter timing change in resetprotocol

Closed 2020-07-14.

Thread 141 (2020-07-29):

TIPICFG long URI1 values cause lockup

jedimatt42, 2020-07-29:
If the URI1 entry has a certain size, it seems the display string routine in the TIPI configuration program locks the system.

In my case following was set:

URI1=https://github.com/kl9900/TMS9900Family/blob/master/Consoles/TI-99/99-8/Rom/TXT

Doing a CALL TIPI from basic does show the config program for about 2 seconds and then the screen goes blank and no response, so I presume the display string routine is having an issue. To resolve the issue I ssh'ed into the tipi and just edited tipi.config there, removing the long URI1 and then it worked again.

jedimatt42, 2021-01-01:
Reported again.

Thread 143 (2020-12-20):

status on PI.STATUS file

jedimatt42, 2020-12-20:
status opcode support is spotty on PI. device pseudo files.

2020-12-19 13:37:13,546 TipiService : ERROR    Unhandled exception in main
Traceback (most recent call last):
  File "./TipiService.py", line 79, in <module>
    if specialFiles.handle(pab, filename):
  File "/home/tipi/tipi/services/SpecialFiles.py", line 50, in handle
    handler.handle(pab, devname)
  File "/home/tipi/tipi/services/StatusFile.py", line 34, in handle
    self.status(pab, devname)
  File "/home/tipi/tipi/services/StatusFile.py", line 79, in status
    if readRec >= self.tipiStatus.len():
AttributeError: 'list' object has no attribute 'len'

jedimatt42, 2020-12-27:
this turned out to be a bug caused by my python2 code getting missed in python3 conversion.

Closed 2020-12-27.

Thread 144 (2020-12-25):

Weird safepoint BackoffException appears to not be handled correctly...

jedimatt42, 2020-12-25:
https://atariage.com/forums/topic/265136-tipi-ti-994a-to-raspberry-pi-interface-development/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

It seems like this happened in the middle of a request, which shouldn't be possible. But there is still some weirdness around this. See the Atariage post for stack trace and scenario. (Except after TIPI reset the service it stopped happening)

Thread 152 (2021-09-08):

socket error

arcadeshopper, 2021-09-08:
while on my afterhours bbs i got disconnected and this is in the log

2021-09-07 21:50:31,216 TipiService : ERROR    Unhandled exception in main
Traceback (most recent call last):
  File "./TipiService.py", line 65, in <module>
    if levelTwo.handle(msg):
  File "/home/tipi/tipi/services/LevelTwo.py", line 37, in handle
    handler = self.handlers.get(msg[0], self.defaultHandler)
IndexError: bytearray index out of range
2021-09-07 21:50:31,653 TipiService : INFO     physical mode enabled
2021-09-07 21:50:31,654 TipiService : INFO     TIPI Ready

jedimatt42, 2021-09-09:
That looks like a random transmission error or programmer error on the client side.  The client is requesting a LVL2 disk io routine that is unsupported by the TIPI.

This could only happen if a client is bi-passing the DSR and messaging to the TIPI LVL2 disk directly. Since no one but myself is knowledgeable enough to do that, it is most likely that the cable between the TIPI board and the Raspberry PI caused a glitch.

Closed 2021-09-09.

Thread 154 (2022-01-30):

lvl2 direct input access on open file that hasn't been closed yet..

jedimatt42, 2022-01-30:
MDOS diskAssembler has order of operations issues.

jedimatt42, 2022-01-30:
It is possible that this just needs eager writing for the use case... create the file on open, and update it on any write.

Closed 2022-07-24.

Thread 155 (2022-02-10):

problems with communication to js99er when using physical PI

jedimatt42, 2022-02-10:
the websock code seems to get a failure, and then bail out mid message... arcadeshopper and I have seen this on a PI Zero 2W.

jedimatt42, 2022-03-19:
currently reporting that this is reliable for ethernet connection after some improvement from PeteE.

Closed 2022-03-19.

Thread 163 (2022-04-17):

emu_config.sh - Missing.

reed-rosa, 2022-04-17:
On:
https://github.com/jedimatt42/tipi/wiki/emulation-installation

It mentions if running with a real PI and and emulator you should:
"Enable emulation mode, by running /home/tipi/tipi/emulation/emu_config.sh and responding to the prompts. On a real Raspberry PI, PDF conversion can be enabled, and you probably don't want tipi_disk mounted via NFS. "

I don't have an emu_config.sh.
I have:
root@tipi:/home/tipi/tipi/emulation# ls -al
total 4044
drwxr-xr-x  2 tipi tipi    4096 Dec 27  2020 .
drwxr-xr-x 11 tipi tipi    4096 Nov 21 14:21 ..
-rw-r--r--  1 tipi tipi     144 Dec 27  2020 .gitattributes
-rwxr-xr-x  1 tipi tipi     783 Dec 27  2020 LICENSE.txt
-rw-r--r--  1 tipi tipi     533 Dec 27  2020 README.md
-rwxr-xr-x  1 tipi tipi    1832 Dec 27  2020 SETUP.txt
-rwxr-xr-x  1 tipi tipi  274944 Dec 27  2020 WinNFSd.exe
-rwxr-xr-x  1 tipi tipi 3814920 Dec 27  2020 kernel-qemu-4.19.50-buster
-rwxr-xr-x  1 tipi tipi      56 Dec 27  2020 nfs_tipi_disk.bat
-rwxr-xr-x  1 tipi tipi     352 Dec 27  2020 tipi-qemu.bat
-rwxr-xr-x  1 tipi tipi    8573 Dec 27  2020 versatile-pb-buster.dtb
root@tipi:/home/tipi/tipi/emulation#

jedimatt42, 2022-04-17:
This is my mistake, the docs are ahead of the download-able image.

They line up if you are on a real raspberry PI that is up to date via TIPICFG, but not from a starting with emulation / QEMU approach. I am working on revamping all that.

I need to produce a new SD card image for you all to start from.

jedimatt42, 2022-04-17:
the image included with the latest tipi-emulation___.zip has the file in question, and is pre-configured with emulation mode, no nfs, no pdf.

Closed 2022-04-17.

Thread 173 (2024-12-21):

opening a non-existent file for reading doesn't return an open failure

mcvde, 2024-12-21:
C libti99 dsrlink returns 0 (success) when opening a non-existent file for reading  files.

This has occurred with
DSR_READ, DSR_TYPE_DISPLAY | DSR_TYPE_VARIABLE | DSR_TYPE_SEQUENTIAL | DSR_TYPE_INPUT,
DSR_WRITE, DSR_TYPE_INTERNAL | DSR_TYPE_FIXED | DSR_TYPE_RELATIVE | DSR_TYPE_UPDATE, and
DSR_READ, DSR_TYPE_INTERNAL | DSR_TYPE_FIXED | DSR_TYPE_RELATIVE | DSR_TYPE_INPUT.

looking at BasicFile.py, I don't see any test for file open failure.

The failure occurs on a side car mounted tipi on a real console. The same code works correctly in a non-tipi configured name instance.

mcvde, 2024-12-21:
Sorry the file I was reviewing is NativeFile.py rather than BasicFile.py.

jedimatt42, 2024-12-22:
This is tricky. DSRLNK can accept a return of 0 from the DSR to mean not handled, and most DSRLNKs will move on and try the next card that can handle the device name, or then fail if no card chooses to handle the request. I'll have to peek at the current libti99 DSRLNK. It may be time to rewrite the 'not handled' code to depend solely on drive mapping state instead file found state.

mcvde, 2024-12-22:
I’d forgotten about the unhandled DSR also returning zero. I currently have code in my fopen that confirms the DSR exists, having cached the list as part of the runtime init, before calling the dsrlink() method with DSR_OPEN.

i recall borrowing your code from force command to read the DSRs.

The current dsrlink() will return non-zero for a missing file if the DSR is handled.

jedimatt42, 2024-12-29:
Reviewing the code, I have a couple loopholes where if the file isn't there and it is a read-only operation, it'll pass back to the DSRLNK... I'm working on tightening that up, so it'll return an error to DSRLNK if the drive was mapped ( should have been handled ) It looks like this impacts OPEN and LOAD.

And I'm adding an option for re-enabling my old behavior. The use case for the old behavior is to allow someone to have DSK1. mapped to a directory that contains the CHARA1 file ( for instance ) and then on their real floppy have the TI-Writer disk or EA disk in, and consequently the CHARA1 from the mapped TIPI drive will load instead of the one in the floppy drive. This allows overriding the file ( in this case the 40 column font ) - I only know of one person who liked that feature, and they don't do anything productive with their 4a anyway - I believe this was behavior borrowed from the Myarc HFDC harddrive controller.

mcvde, 2024-12-30:
That sounds like a great solution. I look forward to it.

jedimatt42, 2025-01-05:
This update released as v4.4 is the fix: https://github.com/jedimatt42/tipi/commit/6723cc4ad690ab07a1ca8dbdb4490df8a3dcf45a

mcvde, 2025-04-05:
It's taken me three months to get to checking out the fix, between side projects and getting DSR ROM updates. The SW load I started with was 4.4 but it didn't seem to fix this, odd. But the TIPI configuration screen popped up with an available update to 4.6 and I let it load it. After that non-existent files reported appropriately.

The reason this was a big deal to me was that many commands in my OS are typed at the command line. Any misspellings of either the command or file arguments meant a system crash. Very happy to have this fix. Thank you!

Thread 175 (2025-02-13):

cant upload backup

arcadeshopper, 2025-02-13:
OSError
OSError: [Errno 28] No space left on device

Traceback (most recent call last)
File "/home/tipi/tipi/htdocs/ENV/lib/python3.11/site-packages/flask/app.py", line 1498, in __call__
return self.wsgi_app(environ, start_response)
       ^^^^^^^^^^^^^^^^^^^^^^^^^^^^^^^^^^^^^^
File "/home/tipi/tipi/htdocs/ENV/lib/python3.11/site-packages/flask_socketio/__init__.py", line 43, in __call__
return super(_SocketIOMiddleware, self).__call__(environ,
       ^^^^^^^^^^^^^^^^^^^^^^^^^^^^^^^^^^^^^^^^^^^^^^^^^^^^^^^^^
File "/home/tipi/tipi/htdocs/ENV/lib/python3.11/site-packages/engineio/middleware.py", line 74, in __call__
return self.wsgi_app(environ, start_response)
       ^^^^^^^^^^^^^^^^^^^^^^^^^^^^^^^^^^^^^^
File "/home/tipi/tipi/htdocs/ENV/lib/python3.11/site-packages/flask/app.py", line 1476, in wsgi_app
response = self.handle_exception(e)
           ^^^^^^^^^^^^^^^^^^^^^^^^
File "/home/tipi/tipi/htdocs/ENV/lib/python3.11/site-packages/flask/app.py", line 1473, in wsgi_app
response = self.full_dispatch_request()
           ^^^^^^^^^^^^^^^^^^^^^^^^^^^^
File "/home/tipi/tipi/htdocs/ENV/lib/python3.11/site-packages/flask/app.py", line 882, in full_dispatch_request
rv = self.handle_user_exception(e)
     ^^^^^^^^^^^^^^^^^^^^^^^^^^^^^
File "/home/tipi/tipi/htdocs/ENV/lib/python3.11/site-packages/flask/app.py", line 880, in full_dispatch_request
rv = self.dispatch_request()
     ^^^^^^^^^^^^^^^^^^^^^^^
File "/home/tipi/tipi/htdocs/ENV/lib/python3.11/site-packages/flask/app.py", line 865, in dispatch_request
return self.ensure_sync(self.view_functions[rule.endpoint])(**view_args)  # type: ignore[no-any-return]
       ^^^^^^^^^^^^^^^^^^^^^^^^^^^^^^^^^^^^^^^^^^^^^^^^^^^^^^^^^^^^^^^^^
File "/home/tipi/tipi/htdocs/./route.py", line 447, in backupul
tipi_backup.upload(request.files.getlist("upload_file"))
                   ^^^^^^^^^^^^^
File "/home/tipi/tipi/htdocs/ENV/lib/python3.11/site-packages/werkzeug/utils.py", line 107, in __get__
value = self.fget(obj)  # type: ignore
        ^^^^^^^^^^^^^^
File "/home/tipi/tipi/htdocs/ENV/lib/python3.11/site-packages/werkzeug/wrappers/request.py", line 494, in files
self._load_form_data()
^^^^^^^^^^^^^^^^^^^^^^
File "/home/tipi/tipi/htdocs/ENV/lib/python3.11/site-packages/flask/wrappers.py", line 115, in _load_form_data
super()._load_form_data()
^^^^^^^^^^^^^^^^^^^^^^^^^
File "/home/tipi/tipi/htdocs/ENV/lib/python3.11/site-packages/werkzeug/wrappers/request.py", line 268, in _load_form_data
data = parser.parse(

File "/home/tipi/tipi/htdocs/ENV/lib/python3.11/site-packages/werkzeug/formparser.py", line 242, in parse
return parse_func(stream, mimetype, content_length, options)
       ^^^^^^^^^^^^^^^^^^^^^^^^^^^^^^^^^^^^^^^^^^^^^^^^^^^^^
File "/home/tipi/tipi/htdocs/ENV/lib/python3.11/site-packages/werkzeug/formparser.py", line 267, in _parse_multipart
form, files = parser.parse(stream, boundary, content_length)
              ^^^^^^^^^^^^^^^^^^^^^^^^^^^^^^^^^^^^^^^^^^^^^^
File "/home/tipi/tipi/htdocs/ENV/lib/python3.11/site-packages/werkzeug/formparser.py", line 384, in parse
_write(event.data)
^^^^^^^^^^^^^^^^^^
File "/usr/lib/python3.11/tempfile.py", line 966, in write
self._check(file)
^^^^^^^^^^^^^^^^^
File "/usr/lib/python3.11/tempfile.py", line 834, in _check
self.rollover()
^^^^^^^^^^^^^^^
File "/usr/lib/python3.11/tempfile.py", line 846, in rollover
newfile.write(file.getvalue())
^^^^^^^^^^^^^^^^^^^^^^^^^^^^^^
OSError: [Errno 28] No space left on device
The debugger caught an exception in your WSGI application. You can now look at the traceback which led to the error.
To switch between the interactive traceback and the plaintext one, you can click on the "Traceback" headline. From the text traceback you can also create a paste of it.

tipi@tipipeb:~ $ df -h
Filesystem      Size  Used Avail Use% Mounted on
udev            318M     0  318M   0% /dev
tmpfs            91M  4.4M   87M   5% /run
/dev/mmcblk0p2   29G  2.9G   25G  11% /
tmpfs           454M     0  454M   0% /dev/shm
tmpfs           5.0M   12K  5.0M   1% /run/lock
tmpfs           100M  100M     0 100% /tmp
tmpfs           100M  160K  100M   1% /var/log
/dev/mmcblk0p1  510M   64M  447M  13% /boot/firmware
tmpfs            91M     0   91M   0% /run/user/1000

arcadeshopper, 2025-02-13:
i am able to restore files via samba..but ..

jedimatt42, 2025-02-15:
the backup archive needs to end up in the /home/tipi folder on the PI, and then it should be selectable for restore. SFTP or SCP it there.

Looks like the web framework is uploading to the /tmp folder on it's way to the real location, which is out of space.

jedimatt42, 2025-02-15:
fixed by https://github.com/jedimatt42/tipi/commit/f47f9e00da1110ed34ebf7a71a62c06ac7eda038

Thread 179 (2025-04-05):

Print emulation doesn't close the print session if computer is reset before a proper file close

arcadeshopper, 2025-04-05:

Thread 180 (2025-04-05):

printer emulation crashes if more than 32 pages of printout

arcadeshopper, 2025-04-05:

arcadeshopper, 2025-04-05:
TIPIPEB
PI3B+
TIPI sw ver 4.6

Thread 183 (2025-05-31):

Opening an existing INT/FIX file with specified record length different from the file succeeds

mcvde, 2025-05-31:
TIPI is returning an open success when the open specifies one record length (non-zero) and the file has a different record length.

The case that occurred was trying to list directory contents (rec Len 146) on a file that was INT/FIX 255.

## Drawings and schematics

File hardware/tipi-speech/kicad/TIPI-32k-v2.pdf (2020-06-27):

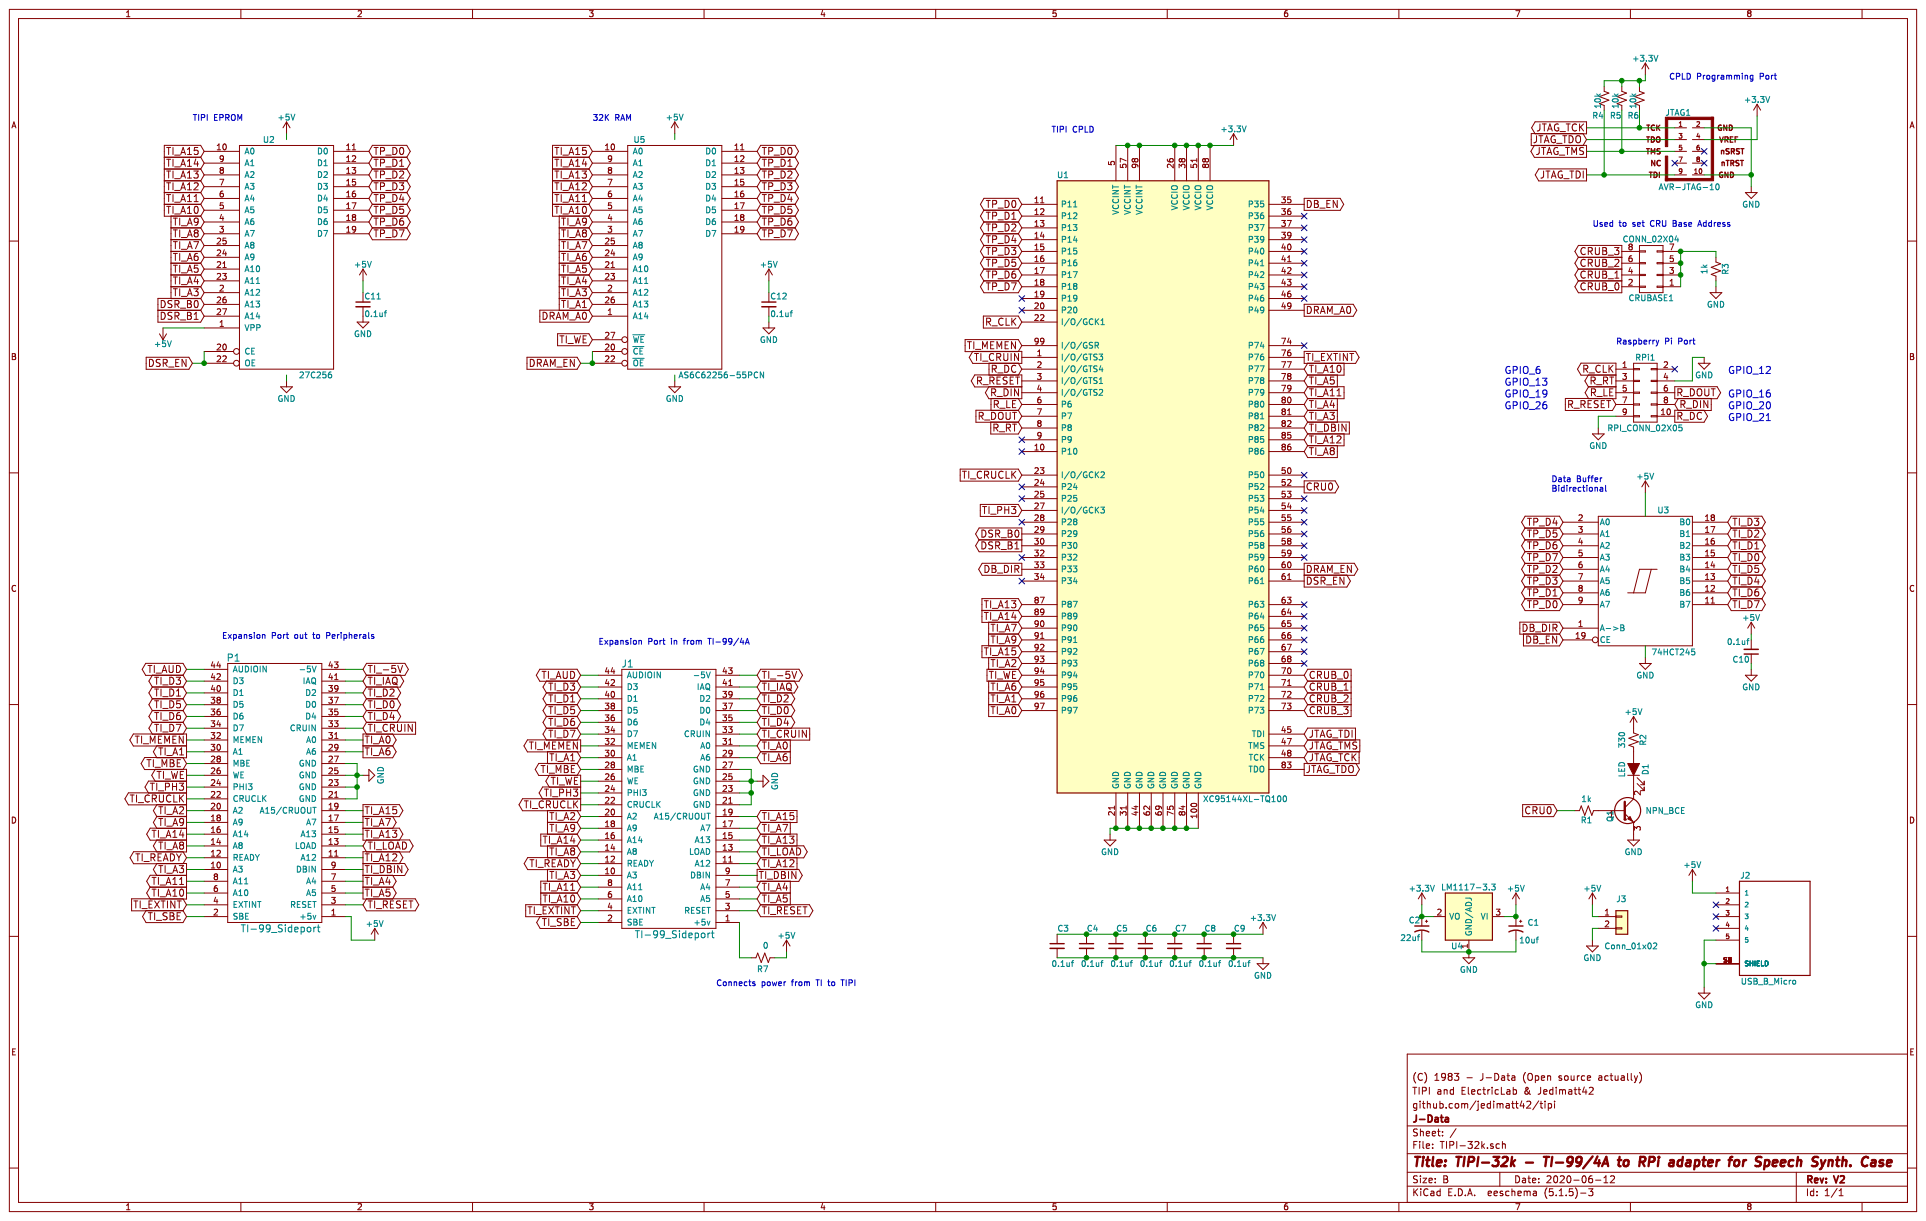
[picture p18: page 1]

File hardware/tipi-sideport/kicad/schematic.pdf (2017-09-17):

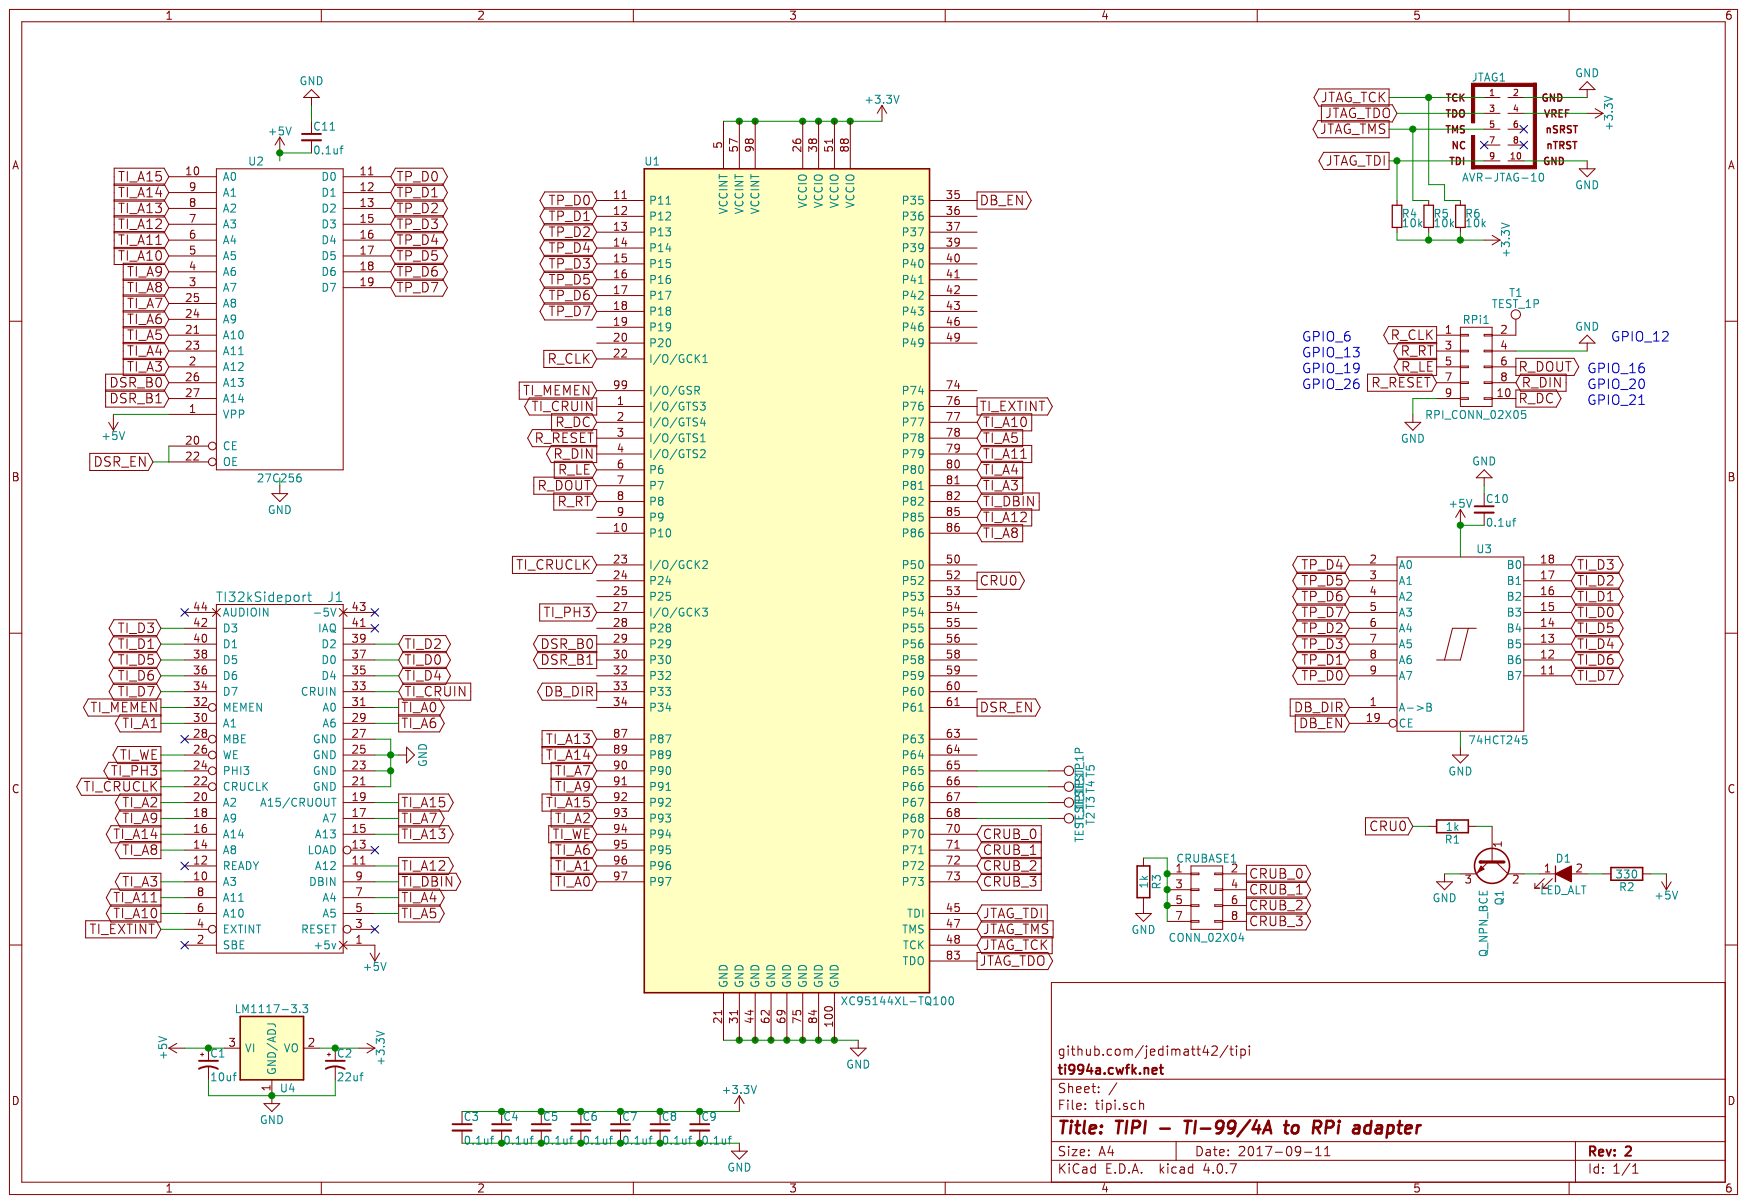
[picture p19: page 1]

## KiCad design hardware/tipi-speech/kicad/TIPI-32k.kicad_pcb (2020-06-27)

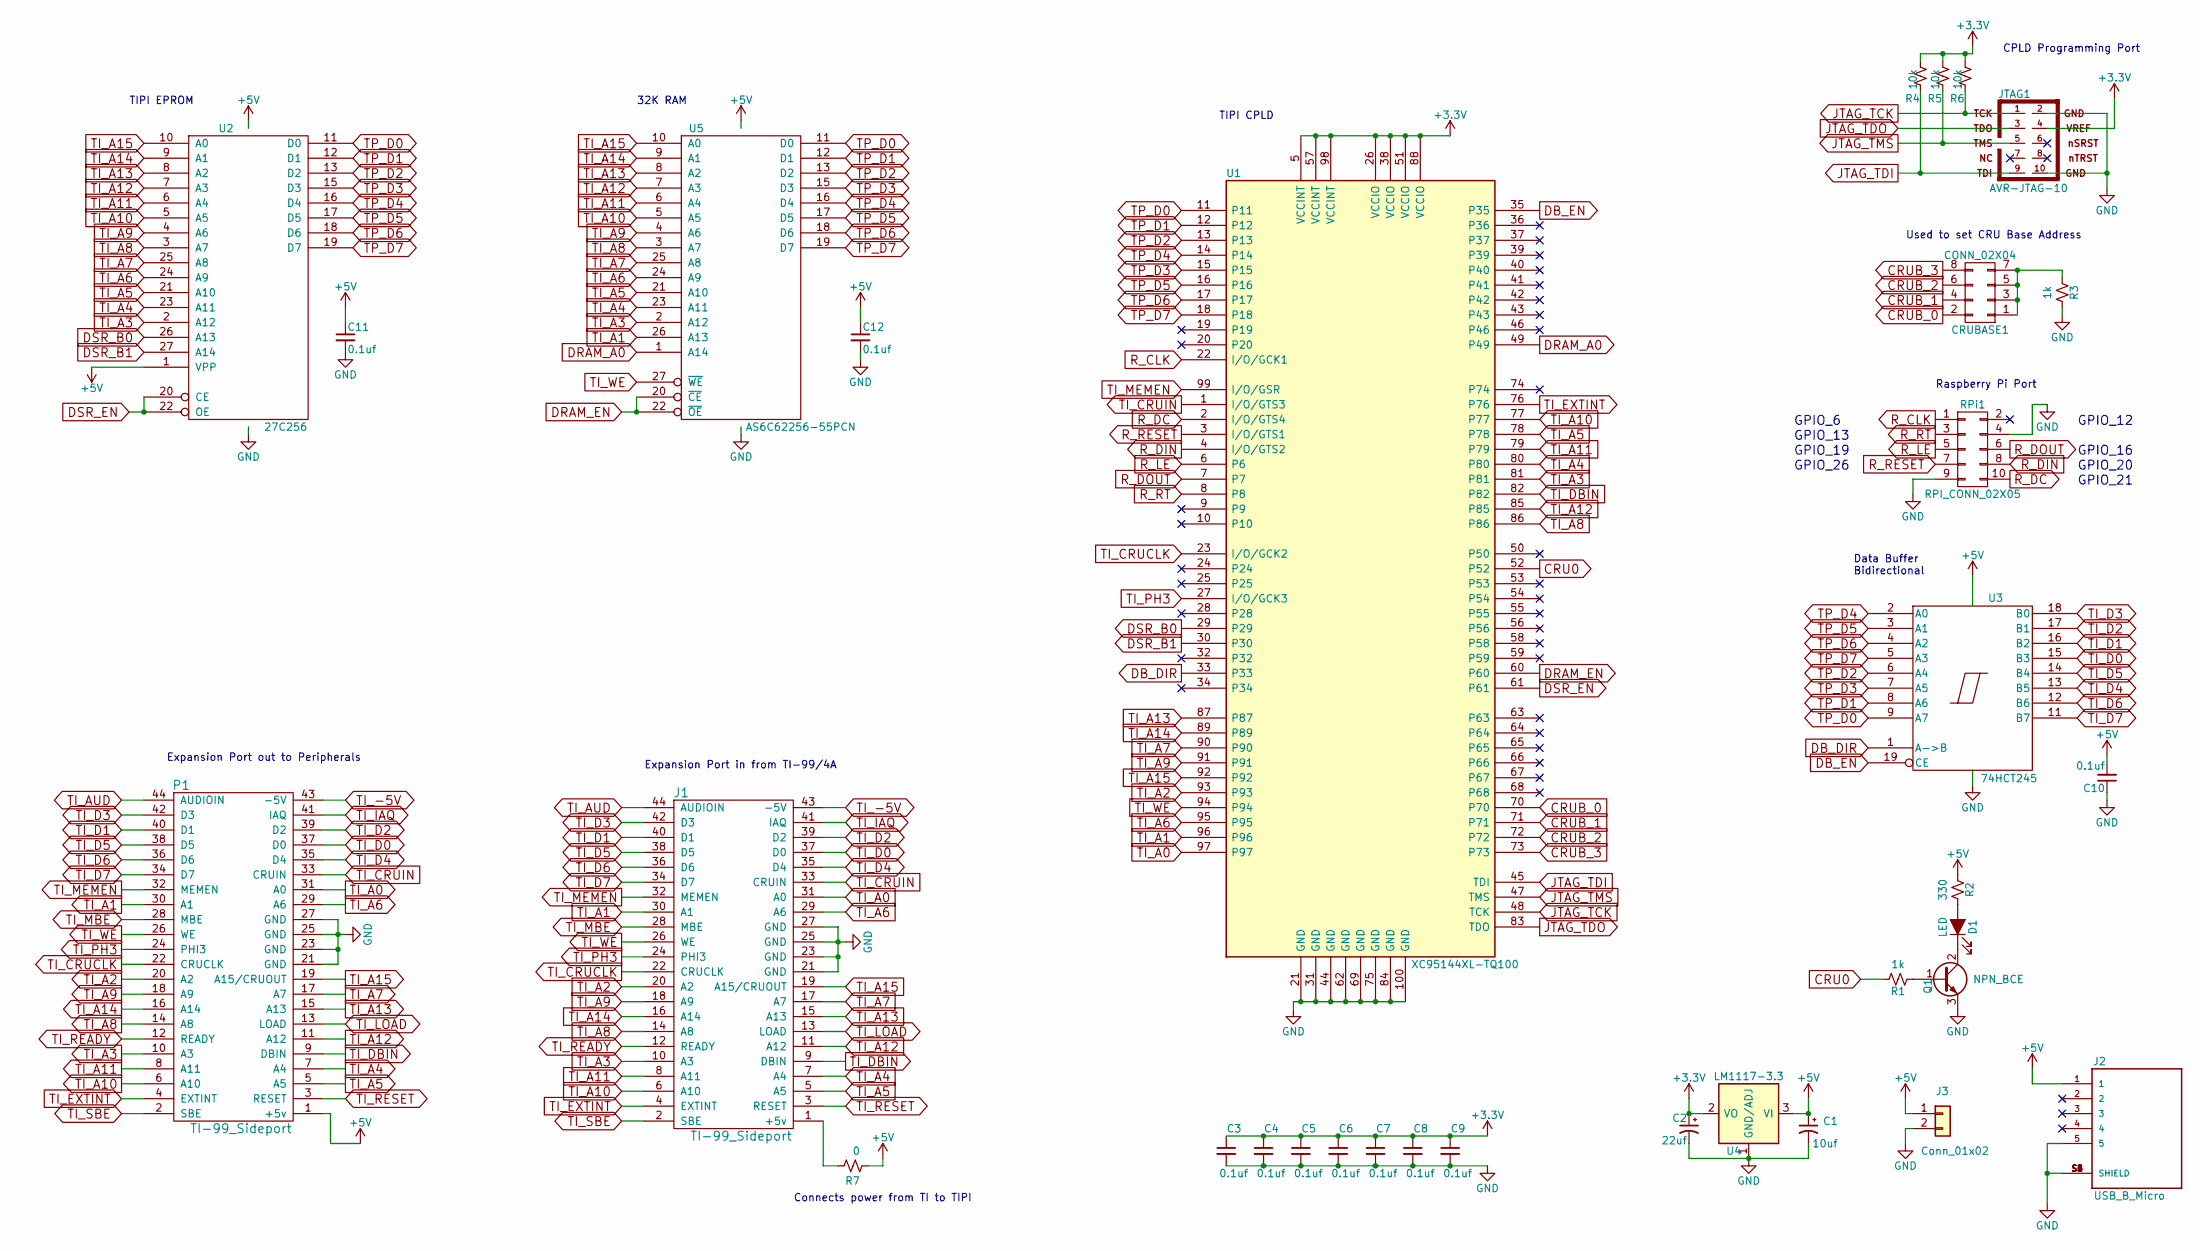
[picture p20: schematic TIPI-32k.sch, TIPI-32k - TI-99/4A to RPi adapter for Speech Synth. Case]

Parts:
C1: 10uf; C_0805_HandSoldering; LCSC C15850
C2: 22uf; C_0805_HandSoldering; LCSC C45783
C3, C6, C12: 0.1uf; C_0805_HandSoldering; LCSC C49678
C4, C5, C7, C8, C9, C10, C11: 0.1uf; C_0805_HandSoldering
CRUBASE1: CONN_02X04; Pin_Header_Straight_2x04_Pitch2.54mm
D1: LED; LED_D3.0mm
J1: TI-99_Sideport; ti99-exp-edge
J2: USB_B_Micro; AMPHENOL_10118194-0001LF; LCSC C132563
J3: Conn_01x02; PinHeader_1x02_P2.54mm_Horizontal
JTAG1: AVR-JTAG-10; IDC_Header_Straight_10pins
P1: TI-99_Sideport; ti99-exp-edge
Q1: NPN_BCE; SOT-23; LCSC C31776
R1, R3: 1k; R_0805_HandSoldering; LCSC C17513
R2: 330; R_0805_HandSoldering; LCSC C17630
R4, R5: 10k; R_0805_HandSoldering; LCSC C17414
R6: 10k; R_0805_HandSoldering
R7: 0; C_0805_HandSoldering
RPi1: RPI_CONN_02X05; IDC_Header_Straight_10pins
U1: XC95144XL-TQ100; TQFP-100_14x14mm_Pitch0.5mm; LCSC C45126
U2: 27C256; DIP-28_W15.24mm_Socket
U3: 74HCT245; SSOP-20; LCSC C5980
U4: LM1117-3.3; SOT-223; LCSC C23984
U5: AS6C62256-55PCN; DIP-28_W15.24mm_Socket

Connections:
+3V3: C2.1, C3.1, C4.1, C5.1, C6.1, C7.1, C8.1, C9.1, JTAG1.4, R4.2, R5.2, R6.2, U1.5 (VCCINT), U1.26 (VCCIO), U1.38 (VCCIO), U1.51 (VCCIO), U1.57 (VCCINT), U1.88 (VCCIO), U1.98 (VCCINT), U4.2 (VO), U4.4 (VO)
+5V: C1.1, C10.2, C11.1, C12.1, J2.1, J3.1, P1.1 (+5v), R2.1, R7.2, U2.1 (VPP), U2.28 (VCC), U3.20 (VCC), U4.3 (VI), U5.28 (VCC)
CRU0: R1.2, U1.52
CRUB_0: CRUBASE1.2, U1.70
CRUB_1: CRUBASE1.4, U1.71
CRUB_2: CRUBASE1.6, U1.72
CRUB_3: CRUBASE1.8, U1.73
DB_DIR: U1.33, U3.1 (A->B)
DB_EN: U1.35, U3.19 (CE)
DRAM_A0: U1.49, U5.1 (A14)
DRAM_EN: U1.60, U5.20 (~CE), U5.22 (~OE)
DSR_B0: U1.29, U2.26 (A13)
DSR_B1: U1.30, U2.27 (A14)
DSR_EN: U1.61, U2.20 (CE), U2.22 (OE)
GND: C1.2, C2.2, C3.2, C4.2, C5.2, C6.2, C7.2, C8.2, C9.2, C10.1, C11.2, C12.2, J1.21 (GND), J1.23 (GND), J1.25 (GND), J1.27 (GND), J2.5, J2.S1 (SHIELD), J2.S2 (SHIELD), J2.S3 (SHIELD), J2.S4 (SHIELD), J2.S5 (SHIELD), J2.S6 (SHIELD), J3.2, JTAG1.2, JTAG1.10, P1.21 (GND), P1.23 (GND), P1.25 (GND), P1.27 (GND), Q1.3 (E), R3.2, RPi1.4, RPi1.9, U1.21 (GND), U1.31 (GND), U1.44 (GND), U1.62 (GND), U1.69 (GND), U1.75 (GND), U1.84 (GND), U1.100 (GND), U2.14 (GND), U3.10 (GND), U4.1 (GND/ADJ), U5.14 (GND)
JTAG_TCK: JTAG1.1, R6.1, U1.48 (TCK)
JTAG_TDI: JTAG1.9, R4.1, U1.45 (TDI)
JTAG_TDO: JTAG1.3, U1.83 (TDO)
JTAG_TMS: JTAG1.5, R5.1, U1.47 (TMS)
unnamed: CRUBASE1.1, CRUBASE1.3, CRUBASE1.5, CRUBASE1.7, R3.1
unnamed: D1.1 (K), Q1.2 (C)
unnamed: D1.2 (A), R2.2
unnamed: J1.1 (+5v), R7.1
unnamed: Q1.1 (B), R1.1
R_CLK: RPi1.1, U1.22 (I/O/GCK1)
R_DC: RPi1.10, U1.2 (I/O/GTS4)
R_DIN: RPi1.8, U1.4 (I/O/GTS2)
R_DOUT: RPi1.6, U1.7
R_LE: RPi1.5, U1.6
R_RESET: RPi1.7, U1.3 (I/O/GTS1)
R_RT: RPi1.3, U1.8
TI_-5V: J1.43 (-5V), P1.43 (-5V)
TI_A0: J1.31 (A0), P1.31 (A0), U1.97
TI_A1: J1.30 (A1), P1.30 (A1), U1.96, U5.26 (A13)
TI_A2: J1.20 (A2), P1.20 (A2), U1.93
TI_A3: J1.10 (A3), P1.10 (A3), U1.81, U2.2 (A12), U5.2 (A12)
TI_A4: J1.7 (A4), P1.7 (A4), U1.80, U2.23 (A11), U5.23 (A11)
TI_A5: J1.5 (A5), P1.5 (A5), U1.78, U2.21 (A10), U5.21 (A10)
TI_A6: J1.29 (A6), P1.29 (A6), U1.95, U2.24 (A9), U5.24 (A9)
TI_A7: J1.17 (A7), P1.17 (A7), U1.90, U2.25 (A8), U5.25 (A8)
TI_A8: J1.14 (A8), P1.14 (A8), U1.86, U2.3 (A7), U5.3 (A7)
TI_A9: J1.18 (A9), P1.18 (A9), U1.91, U2.4 (A6), U5.4 (A6)
TI_A10: J1.6 (A10), P1.6 (A10), U1.77, U2.5 (A5), U5.5 (A5)
TI_A11: J1.8 (A11), P1.8 (A11), U1.79, U2.6 (A4), U5.6 (A4)
TI_A12: J1.11 (A12), P1.11 (A12), U1.85, U2.7 (A3), U5.7 (A3)
TI_A13: J1.15 (A13), P1.15 (A13), U1.87, U2.8 (A2), U5.8 (A2)
TI_A14: J1.16 (A14), P1.16 (A14), U1.89, U2.9 (A1), U5.9 (A1)
TI_A15: J1.19 (A15/CRUOUT), P1.19 (A15/CRUOUT), U1.92, U2.10 (A0), U5.10 (A0)
TI_AUD: J1.44 (AUDIOIN), P1.44 (AUDIOIN)
TI_CRUCLK: J1.22 (CRUCLK), P1.22 (CRUCLK), U1.23 (I/O/GCK2)
TI_CRUIN: J1.33 (CRUIN), P1.33 (CRUIN), U1.1 (I/O/GTS3)
TI_D0: J1.37 (D0), P1.37 (D0), U3.15 (B3)
TI_D1: J1.40 (D1), P1.40 (D1), U3.16 (B2)
TI_D2: J1.39 (D2), P1.39 (D2), U3.17 (B1)
TI_D3: J1.42 (D3), P1.42 (D3), U3.18 (B0)
TI_D4: J1.35 (D4), P1.35 (D4), U3.13 (B5)
TI_D5: J1.38 (D5), P1.38 (D5), U3.14 (B4)
TI_D6: J1.36 (D6), P1.36 (D6), U3.12 (B6)
TI_D7: J1.34 (D7), P1.34 (D7), U3.11 (B7)
TI_DBIN: J1.9 (DBIN), P1.9 (DBIN), U1.82
TI_EXTINT: J1.4 (EXTINT), P1.4 (EXTINT), U1.76
TI_IAQ: J1.41 (IAQ), P1.41 (IAQ)
TI_LOAD: J1.13 (LOAD), P1.13 (LOAD)
TI_MBE: J1.28 (MBE), P1.28 (MBE)
TI_MEMEN: J1.32 (MEMEN), P1.32 (MEMEN), U1.99 (I/O/GSR)
TI_PH3: J1.24 (PHI3), P1.24 (PHI3), U1.27 (I/O/GCK3)
TI_READY: J1.12 (READY), P1.12 (READY)
TI_RESET: J1.3 (RESET), P1.3 (RESET)
TI_SBE: J1.2 (SBE), P1.2 (SBE)
TI_WE: J1.26 (WE), P1.26 (WE), U1.94, U5.27 (~WE)
TP_D0: U1.11, U2.11 (D0), U3.9 (A7), U5.11 (D0)
TP_D1: U1.12, U2.12 (D1), U3.8 (A6), U5.12 (D1)
TP_D2: U1.13, U2.13 (D2), U3.6 (A4), U5.13 (D2)
TP_D3: U1.15, U2.15 (D3), U3.7 (A5), U5.15 (D3)
TP_D4: U1.14, U2.16 (D4), U3.2 (A0), U5.16 (D4)
TP_D5: U1.16, U2.17 (D5), U3.3 (A1), U5.17 (D5)
TP_D6: U1.17, U2.18 (D6), U3.4 (A2), U5.18 (D6)
TP_D7: U1.18, U2.19 (D7), U3.5 (A3), U5.19 (D7)

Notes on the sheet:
GPIO_21
GPIO_20
GPIO_16
GPIO_12
GPIO_6
GPIO_13
GPIO_19
GPIO_26
Expansion Port in from TI-99/4A
Expansion Port out to Peripherals
Connects power from TI to TIPI
TIPI EPROM
32K RAM
TIPI CPLD
CPLD Programming Port
Used to set CRU Base Address
Raspberry Pi Port
Data Buffer Bidirectional

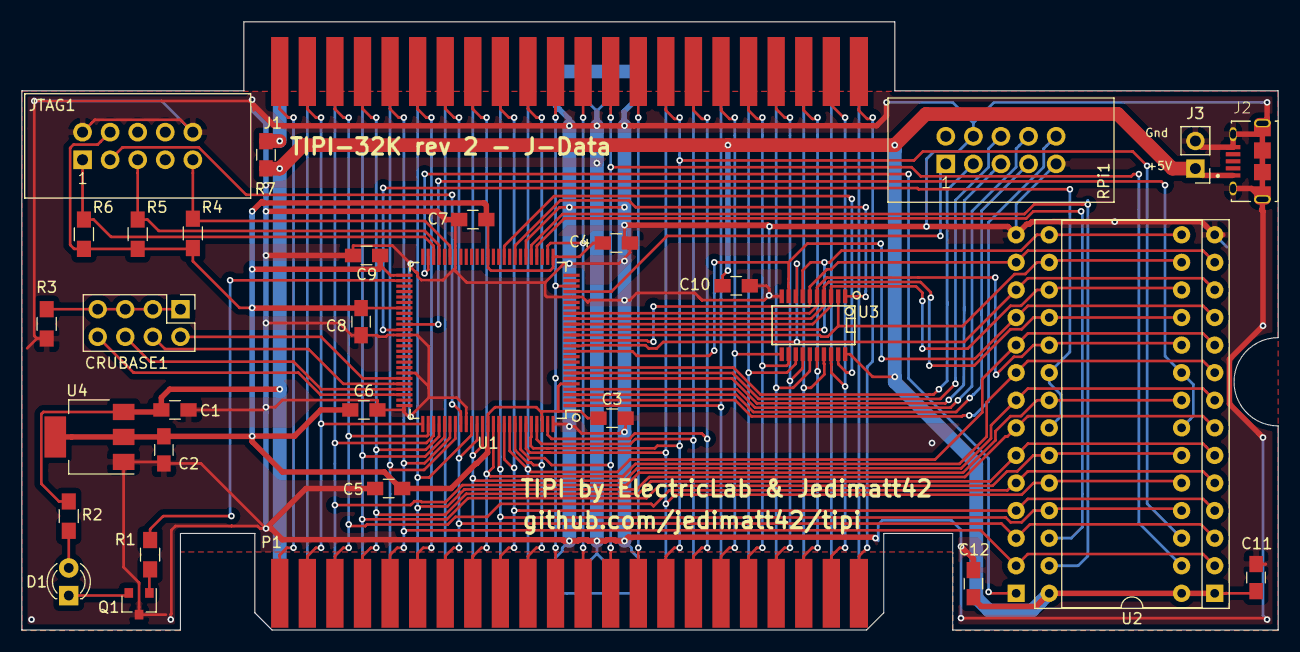
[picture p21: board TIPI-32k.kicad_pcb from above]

Board: 2 copper layers, 115.7 x 56.0 mm, 33 parts (1 on the bottom side), 78 nets.

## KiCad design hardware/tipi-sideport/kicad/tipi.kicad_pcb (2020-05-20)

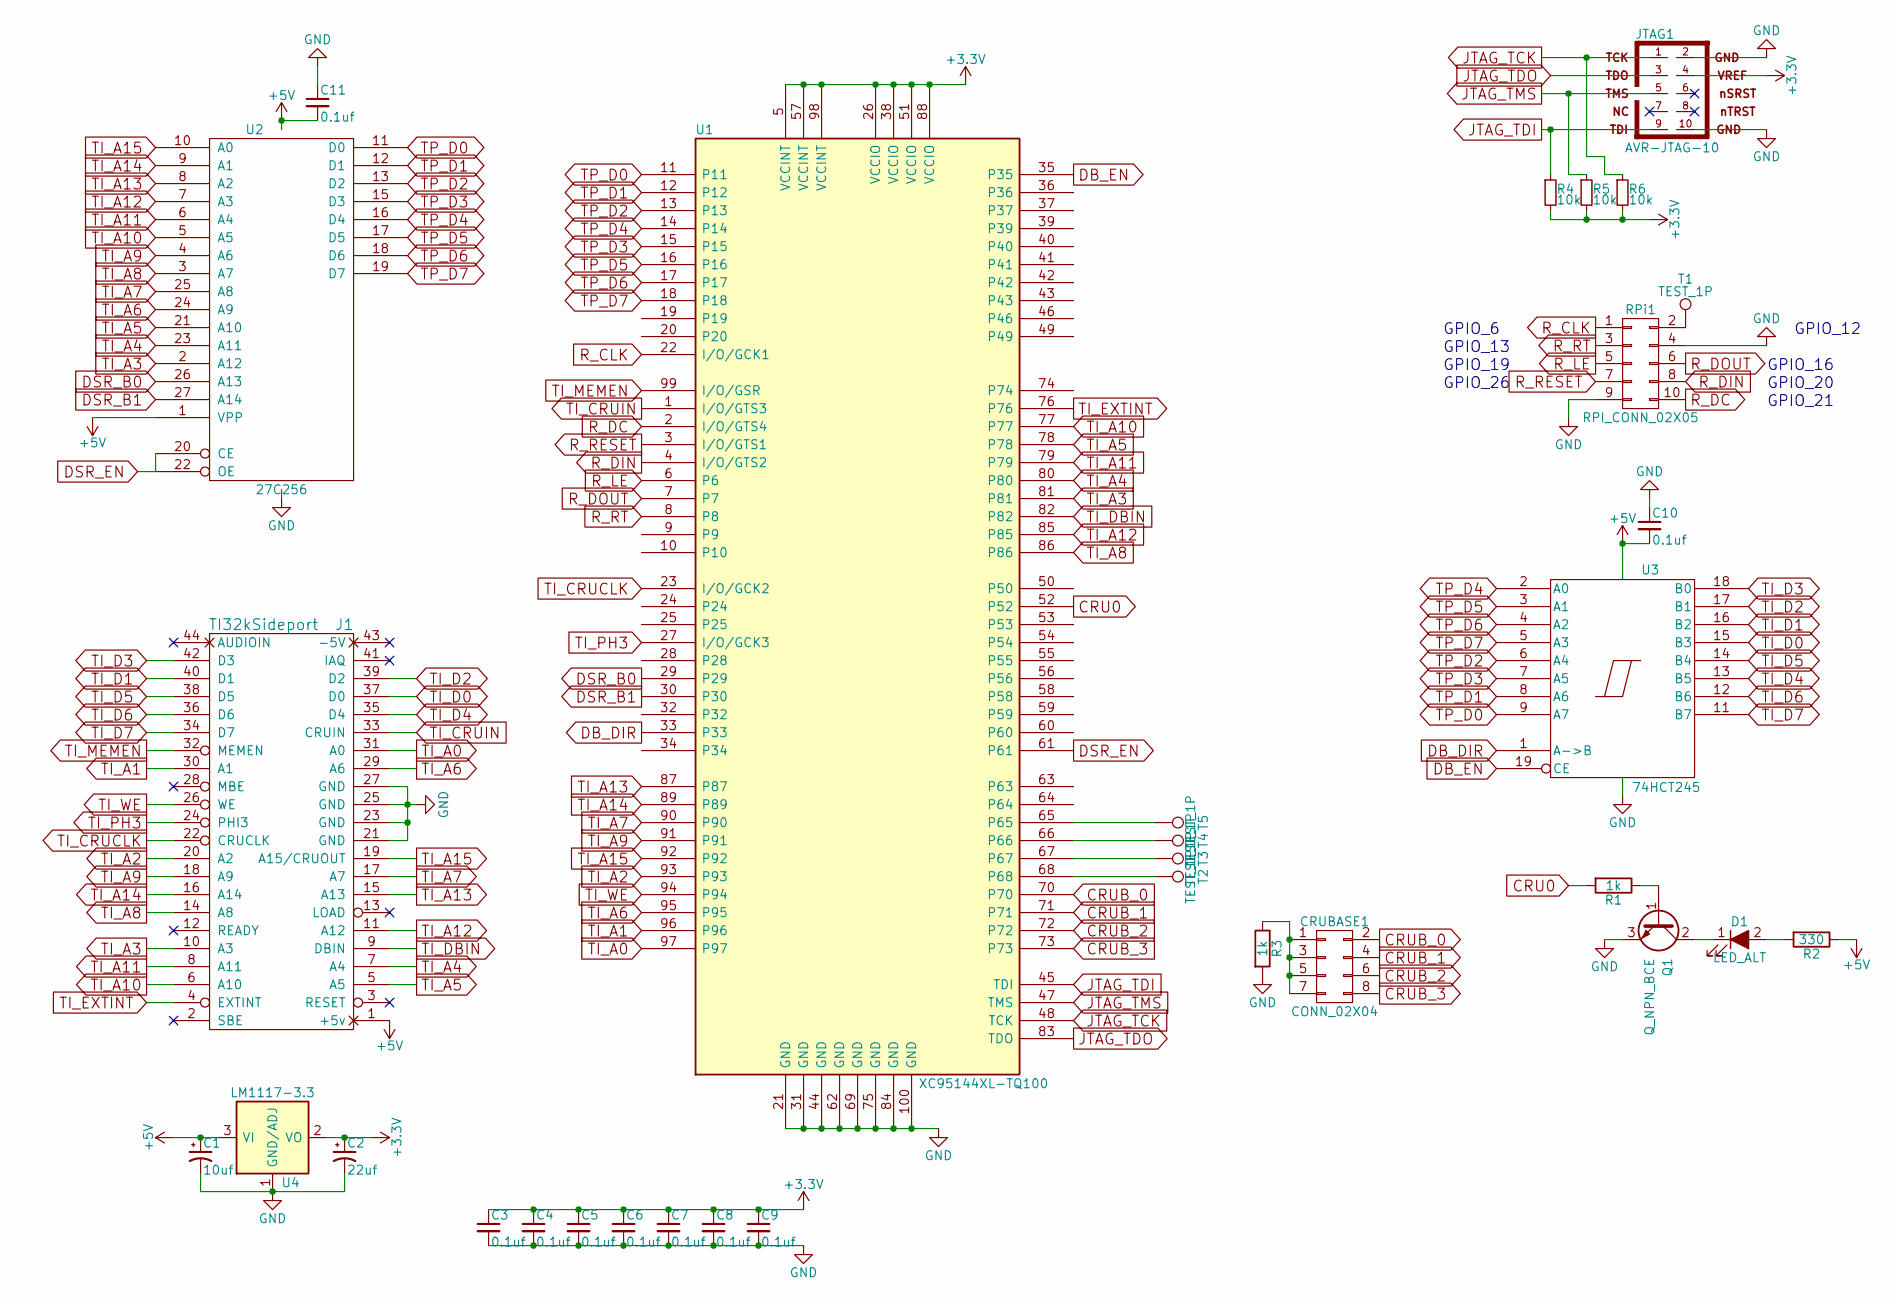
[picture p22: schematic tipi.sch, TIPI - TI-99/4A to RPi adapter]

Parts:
C1: 10uf; C_0805_HandSoldering
C2: 22uf; C_0805_HandSoldering
C3, C4, C5, C6, C7, C8, C9, C10, C11: 0.1uf; C_0805_HandSoldering
CRUBASE1: CONN_02X04; Pin_Header_Straight_2x04_Pitch2.54mm
D1: LED_ALT; LED_D3.0mm
J1: TI32kSideport; Pin_Header_Straight_2x22_Pitch2.54mm
JTAG1: AVR-JTAG-10; IDC_Header_Straight_10pins
Q1: Q_NPN_BCE; SOT-23
R1, R3: 1k; R_0805_HandSoldering
R2: 330; R_0805_HandSoldering
R4, R5, R6: 10k; R_0805_HandSoldering
RPi1: RPI_CONN_02X05; IDC_Header_Straight_10pins
T1, T2, T3, T4, T5: TEST_1P; SolderWirePad_single_0-8mmDrill
U1: XC95144XL-TQ100; TQFP-100_14x14mm_Pitch0.5mm
U2: 27C256; DIP-28_W15.24mm_Socket
U3: 74HCT245; SSOP-20
U4: LM1117-3.3; SOT-223

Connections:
+3V3: C2.1, C3.1, C4.1, C5.1, C6.1, C7.1, C8.1, C9.1, JTAG1.4, R4.2, R5.2, R6.2, U1.5 (VCCINT), U1.26 (VCCIO), U1.38 (VCCIO), U1.51 (VCCIO), U1.57 (VCCINT), U1.88 (VCCIO), U1.98 (VCCINT), U4.2 (VO), U4.4 (VO)
+5V: C1.1, C10.2, C11.2, J1.1 (+5v), R2.1, U2.1 (VPP), U2.28 (VCC), U3.20 (VCC), U4.3 (VI)
CRU0: R1.2, U1.52
CRUB_0: CRUBASE1.2, U1.70
CRUB_1: CRUBASE1.4, U1.71
CRUB_2: CRUBASE1.6, U1.72
CRUB_3: CRUBASE1.8, U1.73
DB_DIR: U1.33, U3.1 (A->B)
DB_EN: U1.35, U3.19 (CE)
DSR_B0: U1.29, U2.26 (A13)
DSR_B1: U1.30, U2.27 (A14)
DSR_EN: U1.61, U2.20 (CE), U2.22 (OE)
GND: C1.2, C2.2, C3.2, C4.2, C5.2, C6.2, C7.2, C8.2, C9.2, C10.1, C11.1, J1.21 (GND), J1.23 (GND), J1.25 (GND), J1.27 (GND), JTAG1.2, JTAG1.10, Q1.3 (E), R3.2, RPi1.4, RPi1.9, U1.21 (GND), U1.31 (GND), U1.44 (GND), U1.62 (GND), U1.69 (GND), U1.75 (GND), U1.84 (GND), U1.100 (GND), U2.14 (GND), U3.10 (GND), U4.1 (GND/ADJ)
JTAG_TCK: JTAG1.1, R6.1, U1.48 (TCK)
JTAG_TDI: JTAG1.9, R4.1, U1.45 (TDI)
JTAG_TDO: JTAG1.3, U1.83 (TDO)
JTAG_TMS: JTAG1.5, R5.1, U1.47 (TMS)
unnamed: CRUBASE1.1, CRUBASE1.3, CRUBASE1.5, CRUBASE1.7, R3.1
unnamed: D1.1 (K), Q1.2 (C)
unnamed: D1.2 (A), R2.2
unnamed: Q1.1 (B), R1.1
unnamed: RPi1.2, T1.1
unnamed: T2.1, U1.68
unnamed: T3.1, U1.67
unnamed: T4.1, U1.66
unnamed: T5.1, U1.65
R_CLK: RPi1.1, U1.22 (I/O/GCK1)
R_DC: RPi1.10, U1.2 (I/O/GTS4)
R_DIN: RPi1.8, U1.4 (I/O/GTS2)
R_DOUT: RPi1.6, U1.7
R_LE: RPi1.5, U1.6
R_RESET: RPi1.7, U1.3 (I/O/GTS1)
R_RT: RPi1.3, U1.8
TI_A0: J1.31 (A0), U1.97
TI_A1: J1.30 (A1), U1.96
TI_A2: J1.20 (A2), U1.93
TI_A3: J1.10 (A3), U1.81, U2.2 (A12)
TI_A4: J1.7 (A4), U1.80, U2.23 (A11)
TI_A5: J1.5 (A5), U1.78, U2.21 (A10)
TI_A6: J1.29 (A6), U1.95, U2.24 (A9)
TI_A7: J1.17 (A7), U1.90, U2.25 (A8)
TI_A8: J1.14 (A8), U1.86, U2.3 (A7)
TI_A9: J1.18 (A9), U1.91, U2.4 (A6)
TI_A10: J1.6 (A10), U1.77, U2.5 (A5)
TI_A11: J1.8 (A11), U1.79, U2.6 (A4)
TI_A12: J1.11 (A12), U1.85, U2.7 (A3)
TI_A13: J1.15 (A13), U1.87, U2.8 (A2)
TI_A14: J1.16 (A14), U1.89, U2.9 (A1)
TI_A15: J1.19 (A15/CRUOUT), U1.92, U2.10 (A0)
TI_CRUCLK: J1.22 (CRUCLK), U1.23 (I/O/GCK2)
TI_CRUIN: J1.33 (CRUIN), U1.1 (I/O/GTS3)
TI_D0: J1.37 (D0), U3.15 (B3)
TI_D1: J1.40 (D1), U3.16 (B2)
TI_D2: J1.39 (D2), U3.17 (B1)
TI_D3: J1.42 (D3), U3.18 (B0)
TI_D4: J1.35 (D4), U3.13 (B5)
TI_D5: J1.38 (D5), U3.14 (B4)
TI_D6: J1.36 (D6), U3.12 (B6)
TI_D7: J1.34 (D7), U3.11 (B7)
TI_DBIN: J1.9 (DBIN), U1.82
TI_EXTINT: J1.4 (EXTINT), U1.76
TI_MEMEN: J1.32 (MEMEN), U1.99 (I/O/GSR)
TI_PH3: J1.24 (PHI3), U1.27 (I/O/GCK3)
TI_WE: J1.26 (WE), U1.94
TP_D0: U1.11, U2.11 (D0), U3.9 (A7)
TP_D1: U1.12, U2.12 (D1), U3.8 (A6)
TP_D2: U1.13, U2.13 (D2), U3.6 (A4)
TP_D3: U1.15, U2.15 (D3), U3.7 (A5)
TP_D4: U1.14, U2.16 (D4), U3.2 (A0)
TP_D5: U1.16, U2.17 (D5), U3.3 (A1)
TP_D6: U1.17, U2.18 (D6), U3.4 (A2)
TP_D7: U1.18, U2.19 (D7), U3.5 (A3)

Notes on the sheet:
GPIO_26
GPIO_19
GPIO_13
GPIO_6
GPIO_12
GPIO_16
GPIO_20
GPIO_21

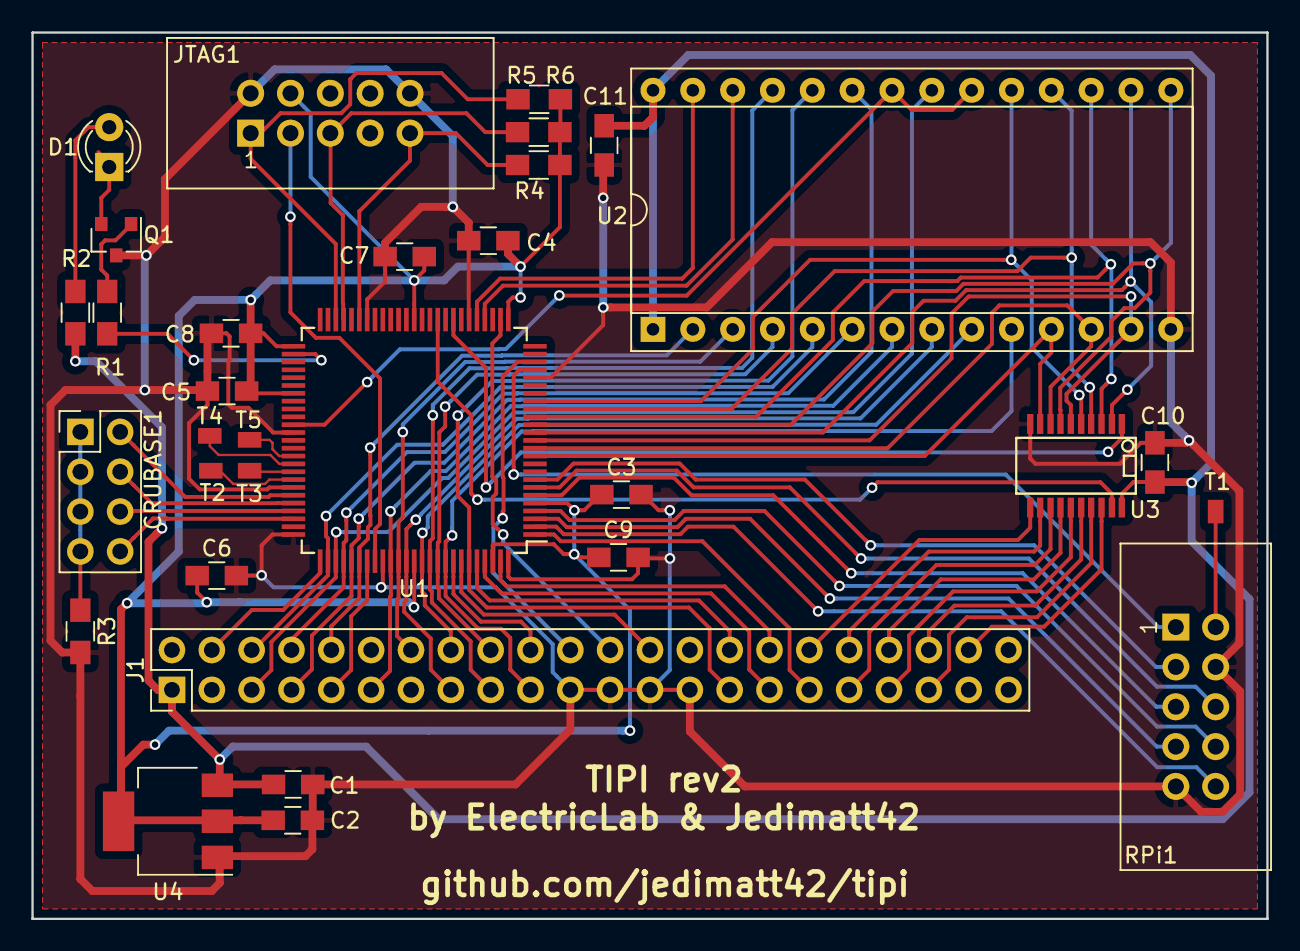
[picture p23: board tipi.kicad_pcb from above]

Board: 2 copper layers, 78.7 x 56.5 mm, 32 parts (0 on the bottom side), 72 nets.

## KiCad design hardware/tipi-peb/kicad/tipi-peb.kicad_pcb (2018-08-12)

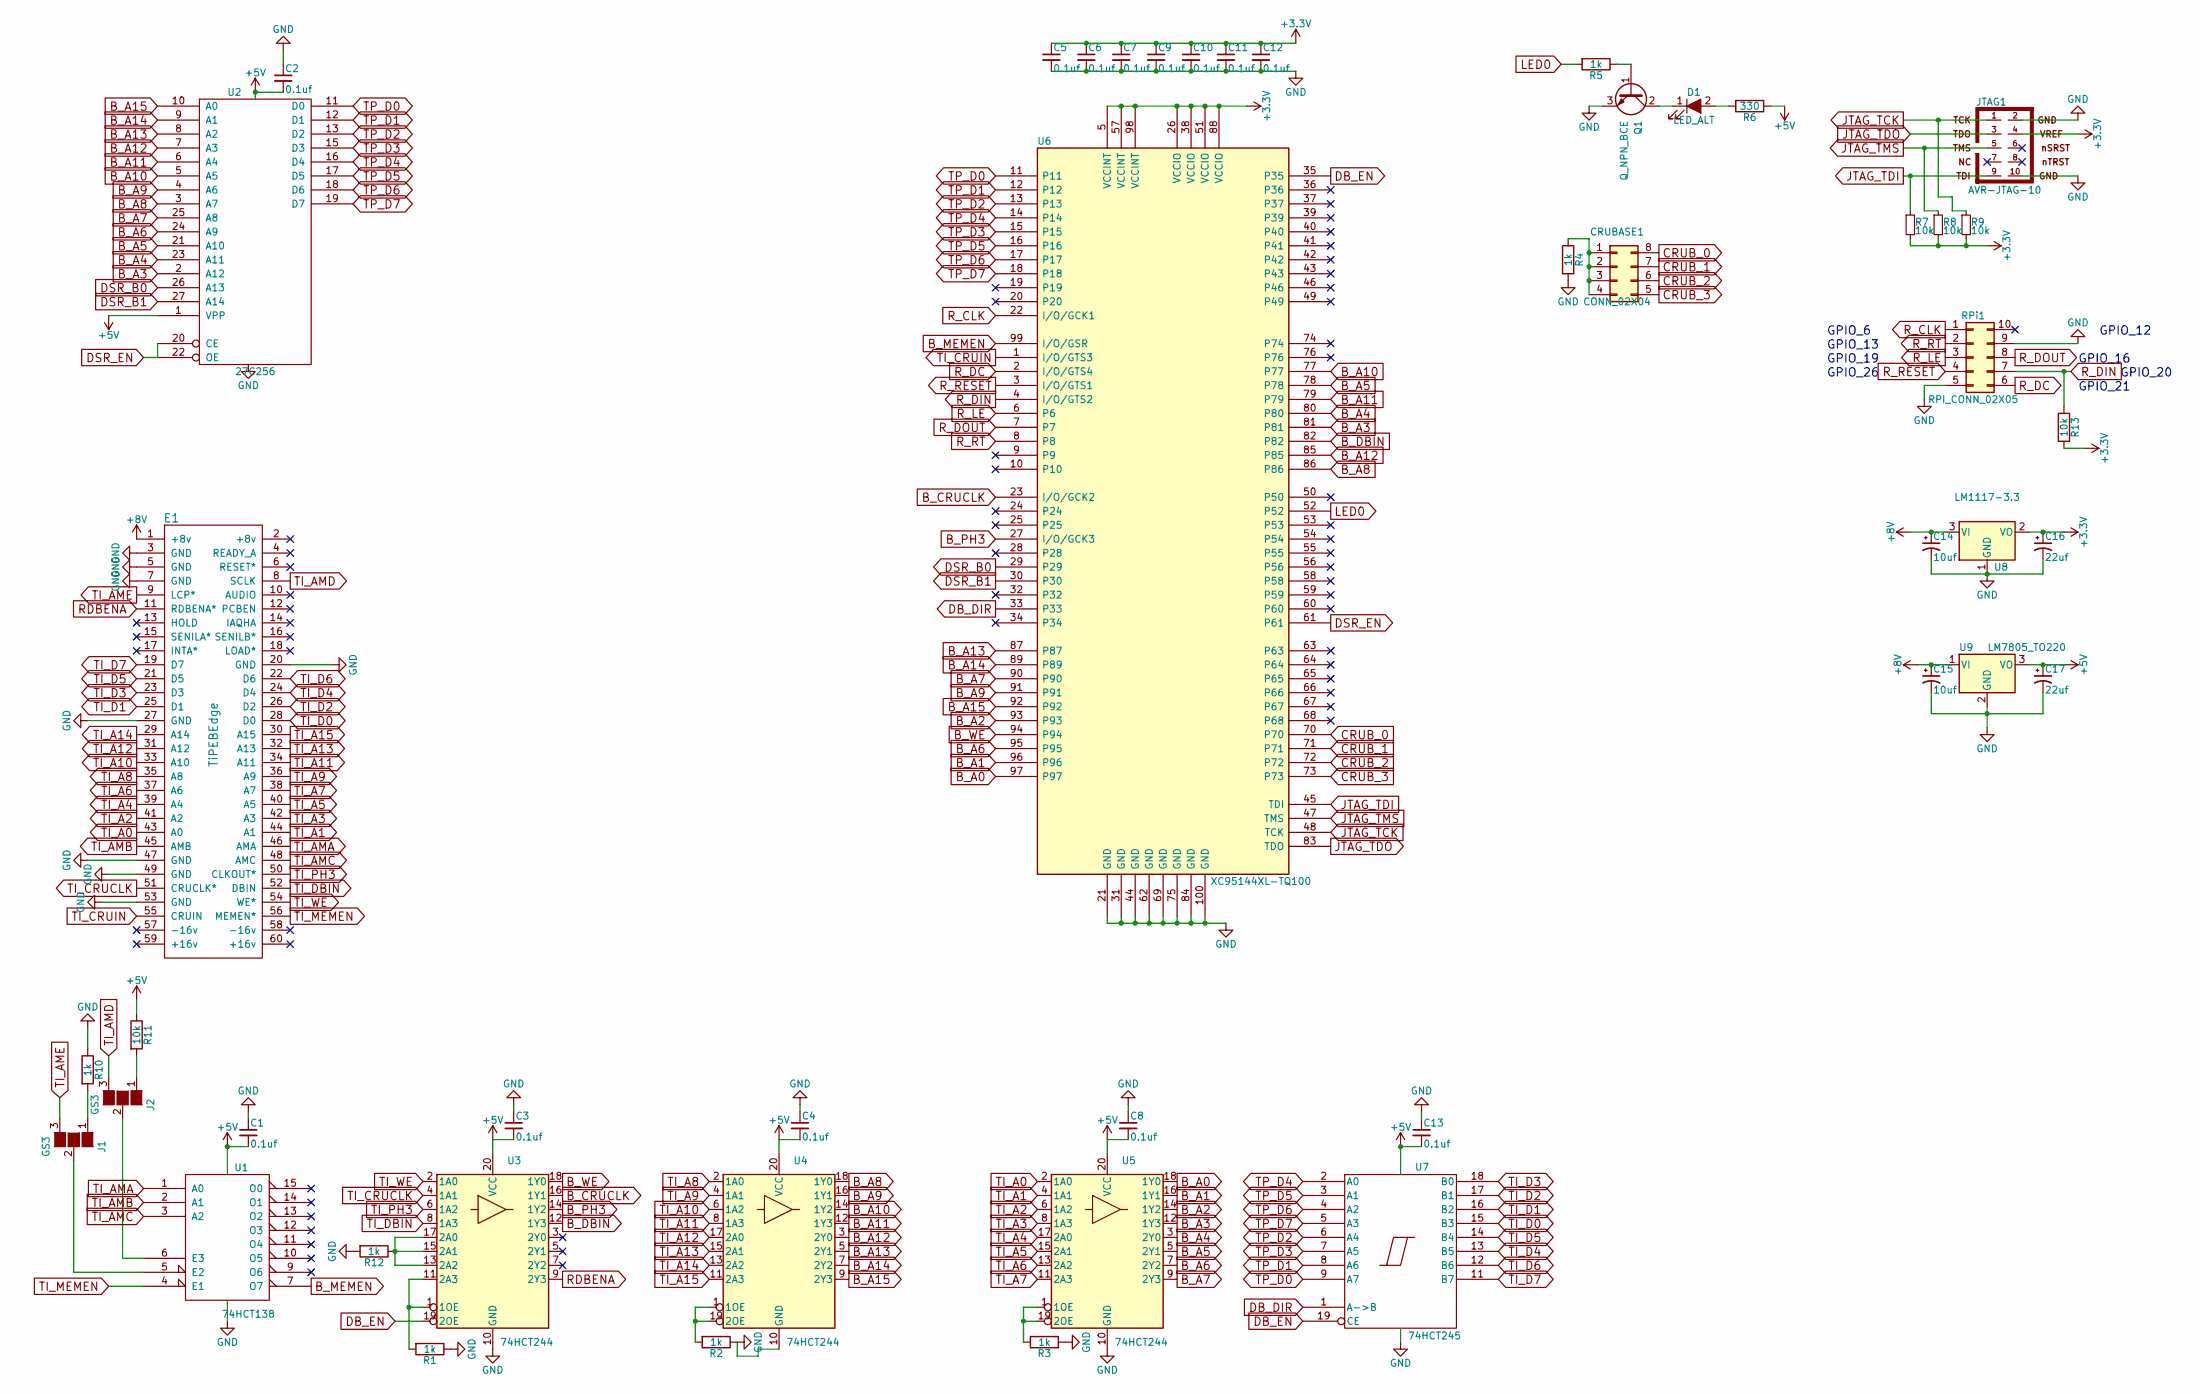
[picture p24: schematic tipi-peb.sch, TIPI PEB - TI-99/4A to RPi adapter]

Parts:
C1, C2, C3, C4, C5, C6, C7, C8, C9, C10, C11, C12, C13: 0.1uf; C_0805_HandSoldering
C14, C15: 10uf; C_0805_HandSoldering
C16, C17: 22uf; C_0805_HandSoldering
CRUBASE1: CONN_02X04; Pin_Header_Straight_2x04_Pitch2.54mm
D1: LED_ALT; LED_D3.0mm
E1: TiPEBEdge; ti99-peb-edge
J1, J2: GS3
JTAG1: AVR-JTAG-10; Pin_Header_Straight_2x05_Pitch2.54mm
Q1: Q_NPN_BCE; SOT-23
R1, R2, R3, R4, R5, R10, R12: 1k; R_0805_HandSoldering
R6: 330; R_0805_HandSoldering
R7, R8, R9, R11, R13: 10k; R_0805_HandSoldering
RPi1: RPI_CONN_02X05; Pin_Header_Straight_2x05_Pitch2.54mm
U1: 74HCT138; TSSOP-16_4.4x5mm_Pitch0.65mm
U2: 27C256; DIP-28_W15.24mm_Socket
U3, U4, U5: 74HCT244; TSSOP-20_4.4x6.5mm_Pitch0.65mm
U6: XC95144XL-TQ100; TQFP-100_14x14mm_Pitch0.5mm
U7: 74HCT245; TSSOP-20_4.4x6.5mm_Pitch0.65mm
U8: LM1117-3.3; SOT-223-3_TabPin2
U9: LM7805_TO220; SOT-223-3_TabPin2

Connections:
+3V3: C5.1, C6.1, C7.1, C9.1, C10.1, C11.1, C12.1, C16.1, JTAG1.4, R7.2, R8.2, R9.2, R13.2, U6.5 (VCCINT), U6.26 (VCCIO), U6.38 (VCCIO), U6.51 (VCCIO), U6.57 (VCCINT), U6.88 (VCCIO), U6.98 (VCCINT), U8.2 (VO)
+5V: C1.2, C2.2, C3.2, C4.2, C8.2, C13.2, C17.1, R6.1, R11.1, U1.16 (VCC), U2.1 (VPP), U2.28 (VCC), U3.20 (VCC), U4.20 (VCC), U5.20 (VCC), U7.20 (VCC), U9.3 (VO)
+8V: C14.1, C15.1, E1.1 (+8v), U8.3 (VI), U9.1 (VI)
B_A0: U5.18 (1Y0), U6.97
B_A1: U5.16 (1Y1), U6.96
B_A2: U5.14 (1Y2), U6.93
B_A3: U2.2 (A12), U5.12 (1Y3), U6.81
B_A4: U2.23 (A11), U5.3 (2Y0), U6.80
B_A5: U2.21 (A10), U5.5 (2Y1), U6.78
B_A6: U2.24 (A9), U5.7 (2Y2), U6.95
B_A7: U2.25 (A8), U5.9 (2Y3), U6.90
B_A8: U2.3 (A7), U4.18 (1Y0), U6.86
B_A9: U2.4 (A6), U4.16 (1Y1), U6.91
B_A10: U2.5 (A5), U4.14 (1Y2), U6.77
B_A11: U2.6 (A4), U4.12 (1Y3), U6.79
B_A12: U2.7 (A3), U4.3 (2Y0), U6.85
B_A13: U2.8 (A2), U4.5 (2Y1), U6.87
B_A14: U2.9 (A1), U4.7 (2Y2), U6.89
B_A15: U2.10 (A0), U4.9 (2Y3), U6.92
B_CRUCLK: U3.16 (1Y1), U6.23 (I/O/GCK2)
B_DBIN: U3.12 (1Y3), U6.82
B_MEMEN: U1.7 (O7), U6.99 (I/O/GSR)
B_PH3: U3.14 (1Y2), U6.27 (I/O/GCK3)
B_WE: U3.18 (1Y0), U6.94
CRUB_0: CRUBASE1.8, U6.70
CRUB_1: CRUBASE1.7, U6.71
CRUB_2: CRUBASE1.6, U6.72
CRUB_3: CRUBASE1.5, U6.73
DB_DIR: U6.33, U7.1 (A->B)
DB_EN: U3.19 (2OE), U6.35, U7.19 (CE)
DSR_B0: U2.26 (A13), U6.29
DSR_B1: U2.27 (A14), U6.30
DSR_EN: U2.20 (CE), U2.22 (OE), U6.61
GND: C1.1, C2.1, C3.1, C4.1, C5.2, C6.2, C7.2, C8.1, C9.2, C10.2, C11.2, C12.2, C13.1, C14.2, C15.2, C16.2, C17.2, E1.3 (GND), E1.5 (GND), E1.7 (GND), E1.20 (GND), E1.27 (GND), E1.47 (GND), E1.49 (GND), E1.53 (GND), JTAG1.2, JTAG1.10, Q1.3 (E), R1.1, R2.1, R3.1, R4.2, R10.1, R12.2, RPi1.5, RPi1.9, U1.8 (GND), U2.14 (GND), U3.10 (GND), U4.10 (GND), U5.10 (GND), U6.21 (GND), U6.31 (GND), U6.44 (GND), U6.62 (GND), U6.69 (GND), U6.75 (GND), U6.84 (GND), U6.100 (GND), U7.10 (GND), U8.1 (GND), U9.2 (GND)
JTAG_TCK: JTAG1.1, R9.1, U6.48 (TCK)
JTAG_TDI: JTAG1.9, R7.1, U6.45 (TDI)
JTAG_TDO: JTAG1.3, U6.83 (TDO)
JTAG_TMS: JTAG1.5, R8.1, U6.47 (TMS)
LED0: R5.2, U6.52
unnamed: CRUBASE1.1, CRUBASE1.2, CRUBASE1.3, CRUBASE1.4, R4.1
unnamed: D1.1 (K), Q1.2 (C)
unnamed: D1.2 (A), R6.2
unnamed: J1.1 (G1), R10.2
unnamed: J1.2 (G2), U1.5 (E2)
unnamed: J2.1 (G1), R11.2
unnamed: J2.2 (G2), U1.6 (E3)
unnamed: Q1.1 (B), R5.1
unnamed: R1.2, U3.1 (1OE), U3.11 (2A3)
unnamed: R2.2, U4.1 (1OE), U4.19 (2OE)
unnamed: R3.2, U5.1 (1OE), U5.19 (2OE)
unnamed: R12.1, U3.13 (2A2), U3.15 (2A1), U3.17 (2A0)
RDBENA: E1.11 (RDBENA*), U3.9 (2Y3)
R_CLK: RPi1.1, U6.22 (I/O/GCK1)
R_DC: RPi1.6, U6.2 (I/O/GTS4)
R_DIN: R13.1, RPi1.7, U6.4 (I/O/GTS2)
R_DOUT: RPi1.8, U6.7
R_LE: RPi1.3, U6.6
R_RESET: RPi1.4, U6.3 (I/O/GTS1)
R_RT: RPi1.2, U6.8
TI_A0: E1.43 (A0), U5.2 (1A0)
TI_A1: E1.44 (A1), U5.4 (1A1)
TI_A2: E1.41 (A2), U5.6 (1A2)
TI_A3: E1.42 (A3), U5.8 (1A3)
TI_A4: E1.39 (A4), U5.17 (2A0)
TI_A5: E1.40 (A5), U5.15 (2A1)
TI_A6: E1.37 (A6), U5.13 (2A2)
TI_A7: E1.38 (A7), U5.11 (2A3)
TI_A8: E1.35 (A8), U4.2 (1A0)
TI_A9: E1.36 (A9), U4.4 (1A1)
TI_A10: E1.33 (A10), U4.6 (1A2)
TI_A11: E1.34 (A11), U4.8 (1A3)
TI_A12: E1.31 (A12), U4.17 (2A0)
TI_A13: E1.32 (A13), U4.15 (2A1)
TI_A14: E1.29 (A14), U4.13 (2A2)
TI_A15: E1.30 (A15), U4.11 (2A3)
TI_AMA: E1.46 (AMA), U1.1 (A0)
TI_AMB: E1.45 (AMB), U1.2 (A1)
TI_AMC: E1.48 (AMC), U1.3 (A2)
TI_AMD: E1.8 (SCLK), J2.3 (G3)
TI_AME: E1.9 (LCP*), J1.3 (G3)
TI_CRUCLK: E1.51 (CRUCLK*), U3.4 (1A1)
TI_CRUIN: E1.55 (CRUIN), U6.1 (I/O/GTS3)
TI_D0: E1.28 (D0), U7.15 (B3)
TI_D1: E1.25 (D1), U7.16 (B2)
TI_D2: E1.26 (D2), U7.17 (B1)
TI_D3: E1.23 (D3), U7.18 (B0)
TI_D4: E1.24 (D4), U7.13 (B5)
TI_D5: E1.21 (D5), U7.14 (B4)
TI_D6: E1.22 (D6), U7.12 (B6)
TI_D7: E1.19 (D7), U7.11 (B7)
TI_DBIN: E1.52 (DBIN), U3.8 (1A3)
TI_MEMEN: E1.56 (MEMEN*), U1.4 (E1)
TI_PH3: E1.50 (CLKOUT*), U3.6 (1A2)
TI_WE: E1.54 (WE*), U3.2 (1A0)
TP_D0: U2.11 (D0), U6.11, U7.9 (A7)
TP_D1: U2.12 (D1), U6.12, U7.8 (A6)
TP_D2: U2.13 (D2), U6.13, U7.6 (A4)
TP_D3: U2.15 (D3), U6.15, U7.7 (A5)
TP_D4: U2.16 (D4), U6.14, U7.2 (A0)
TP_D5: U2.17 (D5), U6.16, U7.3 (A1)
TP_D6: U2.18 (D6), U6.17, U7.4 (A2)
TP_D7: U2.19 (D7), U6.18, U7.5 (A3)

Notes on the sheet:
GPIO_26
GPIO_19
GPIO_13
GPIO_6
GPIO_12
GPIO_16
GPIO_20
GPIO_21

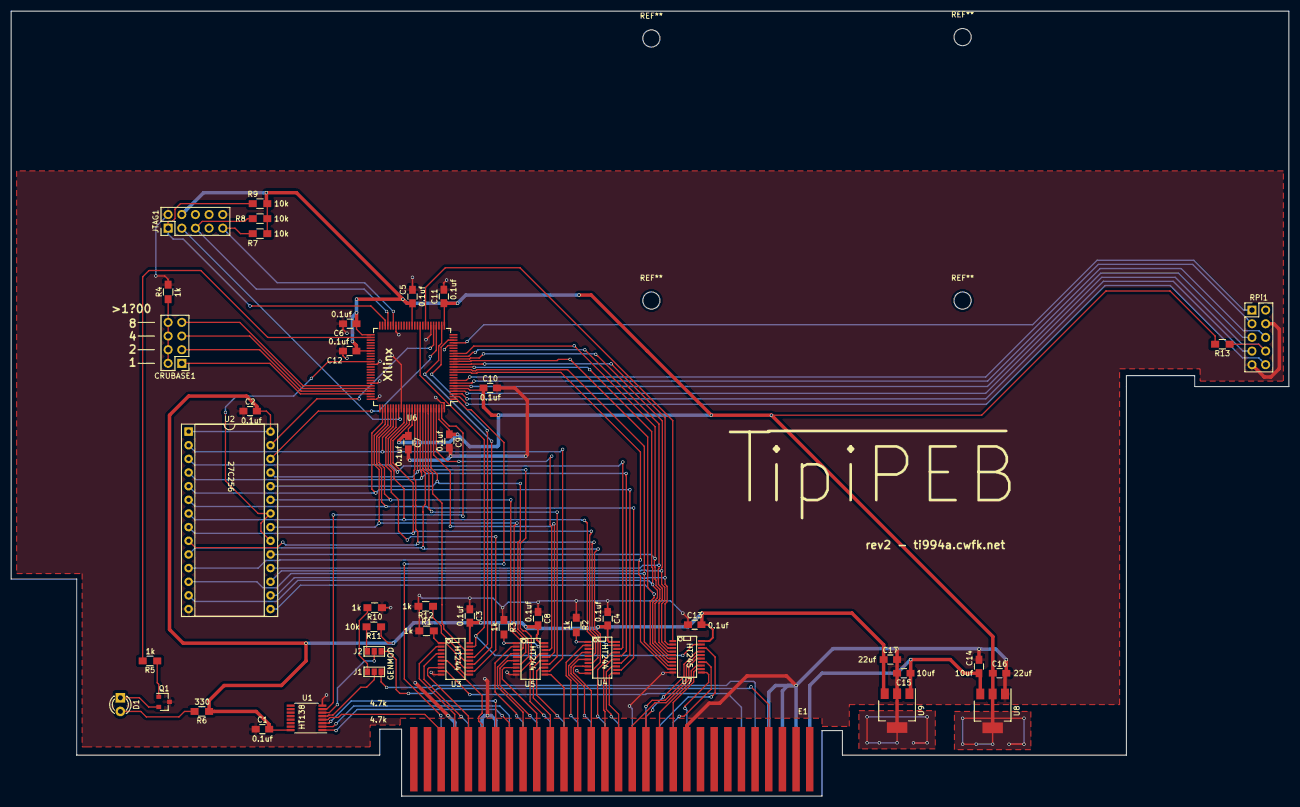
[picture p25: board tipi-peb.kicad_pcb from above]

Board: 2 copper layers, 237.7 x 146.1 mm, 47 parts (0 on the bottom side), 102 nets.

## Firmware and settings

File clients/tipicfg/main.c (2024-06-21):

#include <files.h>

#include <string.h>
#include <system.h>
#include <conio.h>

#define VPAB 0x3000
#define FBUF 0x3200

#define GPLWS ((unsigned int*)0x83E0)
#define DSRTS ((unsigned char*)0x401A)

#define TIPICFG_VER "14"
#define PI_CONFIG "PI.CONFIG"
#define PI_STATUS "PI.STATUS"
#define PI_UPGRADE "PI.UPGRADE"
#define PI_SHUTDOWN "PI.SHUTDOWN"
#define PI_REBOOT "PI.REBOOT"

#define FCTN_U ((char)95)

void waitjiffies(int jiffies);

unsigned char dsr_openDV(struct PAB* pab, char* fname, int vdpbuffer, unsigned char flags);
unsigned char dsr_close(struct PAB* pab);
unsigned char dsr_read(struct PAB* pab, int recordNumber);
unsigned char dsr_write(struct PAB* pab, unsigned char* record);

int strcmp(const char* a, const char* b);
int indexof(const char* str, char c);

void reload();

void processStatusLine(char* cbuf);
void loadPiStatus();
void showStatusValues();

void processConfigLine(char* cbuf);
void loadPiConfig();
void showConfigValues();

void savePiConfig();

void upgrade();
void shutdown();
void reboot();
void toggleAutomap();
void spinnerMessage(int seconds, const char* msg);
void spinnerPoll(const char* msg);
void statusMessage(const char* msg);
void getTIPIPcbDetails();
void getstr(int x, int y, char *var);
void getstr_w_spaces(int x, int y, char* var);

const char spinner[4] = { '-', 92, '|', '/' };

char ipaddress[79]; // generically k=v values from files would be at most 78 characters.
char version[79];
char latest[79];
int crubase;

char cs1_file[79];
char dsk1_dir[79];
char dsk2_dir[79];
char dsk3_dir[79];
char dsk4_dir[79];
char dsk5_dir[79];
char dsk6_dir[79];
char dsk7_dir[79];
char dsk8_dir[79];
char dsk9_dir[79];
char wifi_ssid[79];
char wifi_psk[79];
char uri1[79];
char uri2[79];
char uri3[79];
char automap[79];

int wifi_dirty;
int disks_dirty;
int has_upgrade;

int page;

#define PAGE_DRIVES 0
#define PAGE_WIFI 1
#define PAGE_URIS 2
#define PAGE_END 2

#define CRU_ENABLE(c) __asm__("mov %0,r12\n\tsbo 0" : : "r"(c) : "r12")

#define CRU_DISABLE(c) __asm__("mov %0,r12\n\tsbz 0" : : "r"(c) : "r12")

inline void enableTipi() {
  CRU_ENABLE(crubase);
}

inline void disableTipi() {
  CRU_DISABLE(crubase);
}

unsigned char getRC() {
  enableTipi();
  waitjiffies(8);
  unsigned char rc = *((volatile unsigned char*)0x5FF9);
  disableTipi();
  return rc;
}

void waitjiffies(int jiffies) {
  for(int i=0; i < jiffies; i++) {
    VDP_WAIT_VBLANK_CRU;
  }
}

void showCrubase(int crubase) {
  gotoxy(0,1);
  cprintf("CRUBASE: %x", crubase);
}

void showValue(int x, int y, const char* val) {
  gotoxy(x,y);
  cclear(40 - x);
  gotoxy(x,y);
  cputs(val);
}

void showQMenu() {
  gotoxy(0,22);
  cputs("CFG: Q)uit, ");
  cputs("R)eload");
  if (disks_dirty || wifi_dirty) {
    gotoxy(19,22);
    cputs(", W)rite");
  } else {
    cclearxy(19,22,8);
  }
  gotoxy(0,23);
  cputs(" PI: H)alt, ");
  cputs("re(B)oot");
}

void printDsrTimestamp() {
  gotoxy(11,2);
  if (crubase != 0) {
    // enable the ROM
    __asm__("mov %0,r12\n\tsbo 0" : : "r"(crubase) : "r12");
    // copy from the ROM to screen
    if (*(DSRTS) == '2') { // good for almost 100 years
      cputs(DSRTS);
    }
    // disable the ROM
    __asm__("mov %0,r12\n\tsbz 0" : : "r"(crubase) : "r12");
  }
}

void initGlobals() {
  strcpy(ipaddress,"");
  strcpy(version,"");
  strcpy(cs1_file,"");
  strcpy(dsk1_dir,"");
  strcpy(dsk2_dir,"");
  strcpy(dsk3_dir,"");
  strcpy(dsk4_dir,"");
  strcpy(dsk5_dir,"");
  strcpy(dsk6_dir,"");
  strcpy(dsk7_dir,"");
  strcpy(dsk8_dir,"");
  strcpy(dsk9_dir,"");
  strcpy(wifi_ssid,"");
  strcpy(wifi_psk,"");
  strcpy(uri1,"");
  strcpy(uri2,"");
  strcpy(uri3,"");
  strcpy(automap,"");
  crubase = 0;

  page = 0;
  wifi_dirty = 0;
  disks_dirty = 0;
  has_upgrade = 0;
}

void setupScreen() {
  set_text();
  charset();
  bgcolor(COLOR_CYAN);
  textcolor(COLOR_BLACK);
}

void layoutScreen() {
  clrscr();
  gotoxy(0,0);
  cputs("TIPICFG v");
  cputs(TIPICFG_VER);
  showCrubase(crubase);
  gotoxy(0,2);
  cputs("DSR Build: ");
  printDsrTimestamp();

  gotoxy(13,0);
  cputs("PI-Version: ");
  gotoxy(21,1);
  cputs("IP: ");
  gotoxy(0,3);
  chline(40);
  gotoxy(0,5);
  chline(40);

  if (page == PAGE_DRIVES) {
    // Cassette and DSK mapping items
    gotoxy(0,6);
    cputs("Drive Mappings");
    gotoxy(24,6);
    cputs("A) AUTO=");
    gotoxy(2,7);
    cputs("C) CS1 =");
    gotoxy(2,8);
    cputs("1) DSK1=");
    gotoxy(2,9);
    cputs("2) DSK2=");
    gotoxy(2,10);
    cputs("3) DSK3=");
    gotoxy(2,11);
    cputs("4) DSK4=");
    gotoxy(2,12);
    cputs("5) DSK5=");
    gotoxy(2,13);
    cputs("6) DSK6=");
    gotoxy(2,14);
    cputs("7) DSK7=");
    gotoxy(2,15);
    cputs("8) DSK8=");
    gotoxy(2,16);
    cputs("9) DSK9=");
    // next label
    gotoxy(9,18);
    cputs("WiFi config");
  } else if (page == PAGE_URIS) {
    // Long URL mapping prefix items
    gotoxy(0,6);
    cputs("URI Prefix Mappings");
    gotoxy(2,7);
    cputs("J) URI1=");
    gotoxy(2,9);
    cputs("K) URI2=");
    gotoxy(2,11);
    cputs("L) URI3=");
    // next label
    gotoxy(9,18);
    cputs("DSK and CS1 mapping");
  } else if (page == PAGE_WIFI) {
    // Wifi configuration items
    gotoxy(0,6);
    cputs("WiFi Settings");
    gotoxy(2,7);
    cputs("S) SSID=");
    gotoxy(2,8);
    cputs("P)  PSK=");
    // next label
    gotoxy(9,18);
    cputs("URI mapping");
  }

  // Next page prompt
  gotoxy(2,18);
  cputs("SPACE)");

  // Transient status line
  gotoxy(0,19);
  chline(40);

  // Action menu for Quit, Halt, Write, etc
  gotoxy(0,21);
  chline(40);
  showQMenu();
}

int main()
{
  initGlobals();
  setupScreen();

  layoutScreen();

  reload();

  unsigned char key = 0;
  do {
    gotoxy(23,35);

    while(!kbhit()) {}

    key = cgetc();

    if (page == PAGE_DRIVES) {
      // drive mappings
      switch(key) {
        case 'A':
        case 'a':
          disks_dirty = 1;
          toggleAutomap();
          showValue(32,6,automap);
          break;
        case 'C':
        case 'c':
          disks_dirty = 1;
          getstr(10,7,cs1_file);
          showValue(10,7,cs1_file);
          break;
        case '1':
          disks_dirty = 1;
          getstr(10,8,dsk1_dir);
          showValue(10,8,dsk1_dir);
          break;
        case '2':
          disks_dirty = 1;
          getstr(10,9,dsk2_dir);
          showValue(10,9,dsk2_dir);
          break;
        case '3':
          disks_dirty = 1;
          getstr(10,10,dsk3_dir);
          showValue(10,10,dsk3_dir);
          break;
        case '4':
          disks_dirty = 1;
          getstr(10,11,dsk4_dir);
          showValue(10,11,dsk4_dir);
          break;
        case '5':
          disks_dirty = 1;
          getstr(10,12,dsk5_dir);
          showValue(10,12,dsk5_dir);
          break;
        case '6':
          disks_dirty = 1;
          getstr(10,13,dsk6_dir);
          showValue(10,13,dsk6_dir);
          break;
        case '7':
          disks_dirty = 1;
          getstr(10,14,dsk7_dir);
          showValue(10,14,dsk7_dir);
          break;
        case '8':
          disks_dirty = 1;
          getstr(10,15,dsk8_dir);
          showValue(10,15,dsk8_dir);
          break;
        case '9':
          disks_dirty = 1;
          getstr(10,16,dsk9_dir);
          showValue(10,16,dsk9_dir);
          break;
      }
    } else if (page == PAGE_URIS) {
      // uri mappings
      switch(key) {
        case 'J':
        case 'j':
          disks_dirty = 1;
          getstr(10,7,uri1);
          showValue(10,7,uri1);
          break;
        case 'K':
        case 'k':
          disks_dirty = 1;
          getstr(10,9,uri2);
          showValue(10,9,uri2);
          break;
        case 'L':
        case 'l':
          disks_dirty = 1;
          getstr(10,11,uri3);
          showValue(10,11,uri3);
          break;
      }
    } else if (page == PAGE_WIFI) {
      // wifi settings
      switch(key) {
        case 'S':
        case 's':
          wifi_dirty = 1;
          getstr_w_spaces(10,7,wifi_ssid);
          showValue(10,7,wifi_ssid);
          break;
        case 'P':
        case 'p':
          wifi_dirty = 1;
          getstr_w_spaces(10,8,wifi_psk);
          showValue(10,8,"************");
          break;
      }
    }

    // available on all screens
    switch(key) {
      case 'R':
      case 'r':
        reload();
        break;
      case 'W':
      case 'w':
        savePiConfig();
        disks_dirty = 0;
        wifi_dirty = 0;
        reload();
        break;
      case 'U':
      case 'u':
        if (has_upgrade == 1) {
          upgrade();
        }
        break;
      case FCTN_U:
        upgrade();
        break;
      case 'H':
      case 'h':
        shutdown();
        break;
      case 'B':
      case 'b':
        reboot();
        break;
      case ' ':
        page = page + 1;
        if (page > PAGE_END) { page = 0; }
        layoutScreen();
        showConfigValues();
        showStatusValues();
        break;
    }

    showQMenu();

    VDP_INT_POLL;

  } while(key != 'Q' && key != 'q');

  gotoxy(0,4);
  cputs("quiting...");
  __asm__("clr r0\n\tblwp *r0");
  return 0;
}

void tipi_lib_init()
{
  crubase = 0x1000;
  while (crubase < 0x2000)
  {
    enableTipi();
    unsigned int *dsrrom = (unsigned int *)0x4000;
    dsrrom += 4; // 4 words, not bytes

    if (*dsrrom != 0)
    {
      dsrrom = ((unsigned int *)*dsrrom) + 2;
      unsigned char *dsrname = (unsigned char *)dsrrom;
      // TIPI will always have device TIPI first in dsrlnk list.
      if (dsrname[0] == 4 && dsrname[1] == 'T' && dsrname[2] == 'I' && dsrname[3] == 'P' && dsrname[4] == 'I')
      {
        disableTipi();
        return;
      }
    }
    disableTipi();
    crubase += 0x0100;
  }
  crubase = 0x0000;
}

void getTIPIPcbDetails() {
  tipi_lib_init();
  if (crubase) {
    showCrubase(crubase);
    printDsrTimestamp();
  }
}

int upgradeAvailable(char* latest, char* current) {
  int lmajor = atoi(latest);
  while (latest[0] != '.') {
    latest++;
  }
  int lminor = atoi(latest+1);
  int cmajor = atoi(current);
  while (current[0] != '.') {
    current++;
  }
  int cminor = atoi(current+1);
  if (lmajor > cmajor) {
    return 1;
  }
  if (lmajor == cmajor && lminor > cminor) {
    return 1;
  }
  return 0;
}

void showStatusValues() {
  showValue(25, 0, version);
  showValue(25, 1, ipaddress);
  if (upgradeAvailable(latest, version)) {
    gotoxy(0, 4);
    cputs("U) upgrade to ");
    cputs(latest);
    has_upgrade = 1;
  } else {
    cclearxy(0,4,40);
    has_upgrade = 0;
  }
}

void loadPiStatus() {
  struct PAB pab;

  unsigned char ferr = dsr_openDV(&pab, PI_STATUS, FBUF, DSR_TYPE_INPUT);
  if (ferr) {
    cprintf(" ERROR: %x", ferr);
    return;
  }

  int recNo = 0;
  ferr = DSR_ERR_NONE;
  while(ferr == DSR_ERR_NONE) {
    unsigned char cbuf[81];
    ferr = dsr_read(&pab, 0);
    gotoxy(0,22);
    if (ferr == DSR_ERR_NONE) {
      // Now FBUF has the data...
      vdpmemread(FBUF, cbuf, pab.CharCount);
      cbuf[pab.CharCount] = 0;
      processStatusLine(cbuf);
    }
  }
  ferr = dsr_close(&pab);

  showStatusValues();

  if (ferr) {
    cprintf("Close ERROR: %x", ferr);
    halt();
  }
}

void processStatusLine(char* cbuf) {
  int i = indexof(cbuf, '=');
  if (i == -1) {
    return;
  }
  cbuf[i] = 0;
  char* val = cbuf + i + 1;
  if (0 == strcmp(cbuf, "VERSION")) {
    strcpy(version, val);
  } else if (0 == strcmp(cbuf, "IP_WLAN0")) {
    strcpy(ipaddress, val);
  } else if (0 == strcmp(cbuf, "IP_ETH0")) {
    strcpy(ipaddress, val);
  } else if (0 == strcmp(cbuf, "LATEST")) {
    strcpy(latest, val);
  }
}

void showConfigValues() {
  if (page == PAGE_DRIVES) {
    showValue(32,6, automap);
    showValue(10, 7, cs1_file);
    showValue(10, 8, dsk1_dir);
    showValue(10, 9, dsk2_dir);
    showValue(10, 10, dsk3_dir);
    showValue(10, 11, dsk4_dir);
    showValue(10, 12, dsk5_dir);
    showValue(10, 13, dsk6_dir);
    showValue(10, 14, dsk7_dir);
    showValue(10, 15, dsk8_dir);
    showValue(10, 16, dsk9_dir);
  } else if (page == PAGE_URIS) {
    showValue(10, 7, uri1);
    showValue(10, 9, uri2);
    showValue(10, 11, uri3);
  } else if (page == PAGE_WIFI) {
    showValue(10, 7, wifi_ssid);
    showValue(10, 8, "************");
  }
}

void loadPiConfig() {
  struct PAB pab;

  unsigned char ferr = dsr_openDV(&pab, PI_CONFIG, FBUF, DSR_TYPE_INPUT);
  if (ferr) {
    cprintf(" ERROR: %x", ferr);
    return;
  }

  int recNo = 0;
  ferr = DSR_ERR_NONE;
  while(ferr == DSR_ERR_NONE) {
    unsigned char cbuf[81];
    ferr = dsr_read(&pab, 0);
    gotoxy(0,22);
    if (ferr == DSR_ERR_NONE) {
      // Now FBUF has the data...
      vdpmemread(FBUF, cbuf, pab.CharCount);
      cbuf[pab.CharCount] = 0;
      processConfigLine(cbuf);
    }
  }

  showConfigValues();

  ferr = dsr_close(&pab);
  if (ferr) {
    cprintf("Close ERROR: %x", ferr);
    halt();
  }
  gotoxy(0,4);
  cclear(40);
}

void reload() {
  disks_dirty = 0;
  wifi_dirty = 0;
  getTIPIPcbDetails();
  loadPiConfig();
  loadPiStatus();
}

void processConfigLine(char* cbuf) {
  int i = indexof(cbuf, '=');
  if (i == -1) {
    return;
  }
  cbuf[i] = 0;
  char* val = cbuf + i + 1;
  if (0 == strcmp(cbuf, "DSK1_DIR")) {
    strcpy(dsk1_dir, val);
  } else if (0 == strcmp(cbuf, "DSK2_DIR")) {
    strcpy(dsk2_dir, val);
  } else if (0 == strcmp(cbuf, "DSK3_DIR")) {
    strcpy(dsk3_dir, val);
  } else if (0 == strcmp(cbuf, "DSK4_DIR")) {
    strcpy(dsk4_dir, val);
  } else if (0 == strcmp(cbuf, "DSK5_DIR")) {
    strcpy(dsk5_dir, val);
  } else if (0 == strcmp(cbuf, "DSK6_DIR")) {
    strcpy(dsk6_dir, val);
  } else if (0 == strcmp(cbuf, "DSK7_DIR")) {
    strcpy(dsk7_dir, val);
  } else if (0 == strcmp(cbuf, "DSK8_DIR")) {
    strcpy(dsk8_dir, val);
  } else if (0 == strcmp(cbuf, "DSK9_DIR")) {
    strcpy(dsk9_dir, val);
  } else if (0 == strcmp(cbuf, "CS1_FILE")) {
    strcpy(cs1_file, val);
  } else if (0 == strcmp(cbuf, "URI1")) {
    strcpy(uri1, val);
  } else if (0 == strcmp(cbuf, "URI2")) {
    strcpy(uri2, val);
  } else if (0 == strcmp(cbuf, "URI3")) {
    strcpy(uri3, val);
  } else if (0 == strcmp(cbuf, "WIFI_SSID")) {
    strcpy(wifi_ssid, val);
  } else if (0 == strcmp(cbuf, "WIFI_PSK")) {
    strcpy(wifi_psk, val);
  } else if (0 == strcmp(cbuf, "AUTO")) {
    strcpy(automap, val);
  }
}

void getstr_term(int x, int y, char* var, char term);

void getstr(int x, int y, char* var) {
  getstr_term(x, y, var, 32);
}

void getstr_w_spaces(int x, int y, char* var) {
  getstr_term(x, y, var, 0);
}

void getstr_term(int x, int y, char* var, char term) {
  // need to add maxlen... so we know how big var is.
  gotoxy(x,y);
  cclear(40-x);
  gotoxy(x,y);
  cputs(var);

  unsigned char key = 0;
  int idx = strlen(var);
  while(key != 13) {
    // should set cursor to current char
    conio_cursorChar = var[idx];
    if (conio_cursorChar == 32 || conio_cursorChar == 0) {
      conio_cursorChar = 30;
    }
    gotoxy(x+idx,y);
    key = cgetc();
    int delidx = 0;
    switch(key) {
      case 3: // F1 - delete
        delidx = idx;
        while(var[delidx] != 0) {
          var[delidx] = var[delidx+1];
          delidx++;
        }
        delidx = strlen(var);
        var[delidx] = 0;
        gotoxy(x,y);
        cputs(var);
        cputs(" ");
        break;
      case 7: // F3 - erase line
        idx = 0;
        var[idx] = 0;
        delidx = idx + 1;
        while(var[delidx] != 0) {
          var[delidx] = 0;
          delidx++;
        }
        gotoxy(x+idx,y);
        cclear(40-(x+idx));
        break;
      case 8: // left arrow
        if (idx > 0) {
          gotoxy(x+idx,y);
          cputc(var[idx]);
          idx--;
          gotoxy(x+idx,y);
        }
        break;
      case 9: // right arrow
        if (var[idx] != 0) {
          cputc(var[idx]);
          idx++;
        }
        break;
      case 13: // return
        break;
      default: // alpha numeric
        if (key >= 32 && key <= 122) {
          var[idx++] = key;
          cputc(key);
        }
    }
  }
  if (term != 0) {
    int i=0;
    while(var[i] != term) {
      i++;
    }
    var[i] = 0;
  }
}

void writeConfigItem(struct PAB* pab, const char* key, const char* value) {
  unsigned char line[81];
  int lenkey = strlen(key);
  strcpy(line, key);
  strcpy(line+lenkey, "=");
  strcpy(line+lenkey+1, value);
  unsigned char ferr = dsr_write(pab, line);
  if (ferr) {
    cprintf(" ERROR: %x", ferr);
    halt();
  }
}

void savePiConfig() {
  if (disks_dirty == 0 && wifi_dirty == 0) {
    gotoxy(0,4);
    cputs("No changes");
    return;
  }

  struct PAB pab;

  gotoxy(0,4);
  cputs("Saving PI.CONFIG");

  unsigned char ferr = dsr_openDV(&pab, PI_CONFIG, FBUF, DSR_TYPE_APPEND);
  if (ferr) {
    cprintf(" ERROR: %x", ferr);
    halt();
  }

  unsigned char line[81];

  if (disks_dirty) {
    writeConfigItem(&pab, "CS1_FILE", cs1_file);
    writeConfigItem(&pab, "DSK1_DIR", dsk1_dir);
    writeConfigItem(&pab, "DSK2_DIR", dsk2_dir);
    writeConfigItem(&pab, "DSK3_DIR", dsk3_dir);
    writeConfigItem(&pab, "DSK4_DIR", dsk4_dir);
    writeConfigItem(&pab, "DSK5_DIR", dsk5_dir);
    writeConfigItem(&pab, "DSK6_DIR", dsk6_dir);
    writeConfigItem(&pab, "DSK7_DIR", dsk7_dir);
    writeConfigItem(&pab, "DSK8_DIR", dsk8_dir);
    writeConfigItem(&pab, "DSK9_DIR", dsk9_dir);
    writeConfigItem(&pab, "URI1", uri1);
    writeConfigItem(&pab, "URI2", uri2);
    writeConfigItem(&pab, "URI3", uri3);
    writeConfigItem(&pab, "AUTO", automap);
  }

  if (wifi_dirty) {
    writeConfigItem(&pab, "WIFI_SSID", wifi_ssid);
    writeConfigItem(&pab, "WIFI_PSK", wifi_psk);
  }

  ferr = dsr_close(&pab);
  if (ferr) {
    cprintf("Close ERROR: %x", ferr);
    halt();
  }
  gotoxy(0,4);
  cclear(40);
}

void upgrade() {
  struct PAB pab;

  unsigned char ferr = dsr_openDV(&pab, PI_UPGRADE, FBUF, DSR_TYPE_INPUT);
  if (ferr) {
    cprintf(" ERROR: %x", ferr);
    return;
  }

  ferr = dsr_close(&pab);
  if (ferr) {
    cprintf("Close ERROR: %x", ferr);
    halt();
  }

  spinnerMessage(10, "Starting upgrade...");
  spinnerPoll("upgrade running...");
  reload();
  statusMessage("Upgrade complete!");
}

void shutdown() {
  struct PAB pab;

  unsigned char ferr = dsr_openDV(&pab, PI_SHUTDOWN, FBUF, DSR_TYPE_INPUT);
  if (ferr) {
    cprintf(" ERROR: %x", ferr);
    return;
  }

  ferr = dsr_close(&pab);
  if (ferr) {
    cprintf("Close ERROR: %x", ferr);
    halt();
  }

  spinnerMessage(60, "Halting PI...");
  statusMessage("It should be safe to poweroff PI");
}

void reboot() {
  struct PAB pab;

  unsigned char ferr = dsr_openDV(&pab, PI_REBOOT, FBUF, DSR_TYPE_INPUT);
  if (ferr) {
    cprintf(" ERROR: %x", ferr);
    return;
  }

  ferr = dsr_close(&pab);
  if (ferr) {
    cprintf("Close ERROR: %x", ferr);
    halt();
  }
  spinnerMessage(10, "Rebooting PI");
  spinnerPoll("waiting for reboot");
  reload();
  statusMessage("PI reboot complete");
}

void statusMessage(const char* msg) {
  gotoxy(0,4);
  cclear(40);
  gotoxy(0,4);
  cputs(msg);
}

void spinnerMessage(int seconds, const char* msg) {
  gotoxy(0,4);
  cclear(40);
  gotoxy(2,4);
  cputs(msg);
  for (int i=0; i<(seconds * 4); i++) {
     waitjiffies(15);
     int c = i % 4;
     gotoxy(0,4);
     cputc(spinner[c]);
     VDP_INT_POLL;
  }
  gotoxy(0,4);
  cclear(40);
}

void spinnerPoll(const char* msg) {
  gotoxy(0,4);
  cclear(40);
  gotoxy(2,4);
  cputs(msg);
  unsigned char pi_rc = 0xff;
  int i=0;
  while(pi_rc != 0x00) {
    waitjiffies(7);
    int c = i % 4;
    gotoxy(0,4);
    cputc(spinner[c]);
    VDP_INT_POLL;
    // read pi_rc value
    pi_rc = getRC(); // this waits 1/8 second so led flashes.
    i = i + 1;
  }
  gotoxy(0,4);
  cclear(40);
}

//---- the following are meant to be easy, not fast ----

void initPab(struct PAB* pab) {
  pab->OpCode = DSR_OPEN;
  pab->Status = DSR_TYPE_DISPLAY | DSR_TYPE_VARIABLE | DSR_TYPE_SEQUENTIAL | DSR_TYPE_INPUT;
  pab->RecordLength = 80;
  pab->RecordNumber = 0;
  pab->ScreenOffset = 0;
  pab->NameLength = 0;
  pab->CharCount = 0;
}

// Configures a PAB for filename and DV80, and opens the file
unsigned char dsr_openDV(struct PAB* pab, char* fname, int vdpbuffer, unsigned char flags) {
  initPab(pab);
  pab->OpCode = DSR_OPEN;
  pab->Status = DSR_TYPE_DISPLAY | DSR_TYPE_VARIABLE | DSR_TYPE_SEQUENTIAL | flags;
  pab->RecordLength = 80;
  pab->pName = fname;
  pab->VDPBuffer = vdpbuffer;

  return dsrlnk(pab, VPAB);
}

unsigned char dsr_close(struct PAB* pab) {
  pab->OpCode = DSR_CLOSE;

  return dsrlnk(pab, VPAB);
}

// the data read is in FBUF, the length read in pab->CharCount
// typically passing 0 in for record number will let the controller
// auto-increment it.
unsigned char dsr_read(struct PAB* pab, int recordNumber) {
  pab->OpCode = DSR_READ;
  pab->RecordNumber = recordNumber;
  pab->CharCount = 0;

  unsigned char result = dsrlnk(pab, VPAB);
  vdpmemread(VPAB + 5, (&pab->CharCount), 1);
  return result;
}

unsigned char dsr_write(struct PAB* pab, unsigned char* record) {
  pab->OpCode = DSR_WRITE;
  int len = strlen(record);
  vdpmemcpy(pab->VDPBuffer, record, len);
  pab->CharCount = len;

  return dsrlnk(pab, VPAB);
}

// weird string state toggle
void toggleAutomap() {
  if (0 == strcmp(automap, "on")) {
    strcpy(automap, "off");
  } else {
    strcpy(automap, "on");
  }
}

// utilities

int strcmp(const char* a, const char* b) {
  int i=0;
  do {
    if (a[i] == '\0') {
      return a[i] - b[i];
    }
    i++;
  } while(a[i] == b[i]);
  return a[i] - b[i];
}

int indexof(const char* str, char c) {
  int i=0;
  while(str[i] != 0) {
    if (str[i] == c) {
      return i;
    }
    i++;
  }
  return -1;
}

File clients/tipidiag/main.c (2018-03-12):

#include <string.h>
#include <system.h>
#include <conio.h>

int crubase;

#define DSRTS ((unsigned char*)0x401A)

// should act like memory
#define TDOUT ((volatile unsigned char*)0x5FFF)
#define TCOUT ((volatile unsigned char*)0x5FFD)
// don't know how to self test these yet...
#define RDIN  ((volatile unsigned char*)0x5FFB)
#define RCIN  ((volatile unsigned char*)0x5FF9)

void enableTipi() {
  __asm__("mov %0,r12\n\tsbo 0" : : "r"(crubase) : "r12");
}

void disableTipi() {
  __asm__("mov %0,r12\n\tsbz 0" : : "r"(crubase) : "r12");
}

void discoverCrubase() {
  crubase = 0x1000;
  while(crubase < 0x2000) {
    enableTipi();
    int* cursor = (int*)0x4000;
    if (0xAA01 == *cursor) {
      cursor = (int*)0x4008; // standard location for dsr link list in rom header.
      if (0x0000 != *cursor) {
	cursor = (int*)*cursor; // now 1st entry in dsr list.
	cursor += 2; // points to first dsr name length
	unsigned char* bytes = (unsigned char*)cursor;
	if (bytes[0] == 4 && 
            bytes[1] == 'T' &&
	    bytes[2] == 'I' &&
	    bytes[3] == 'P' &&
	    bytes[4] == 'I') {
	  disableTipi();
	  return;
	}
      }
    }
    disableTipi();
    crubase += 0x0100;
  }
  crubase = 0x0000;
}

void printDsrTimestamp() {
  if (crubase != 0) {
    enableTipi();
    // copy from the ROM to screen
    if (*(DSRTS) == '2') { // good for almost 100 years
      cputs(DSRTS);
    }
    disableTipi();
  }
}

void testROM() {
  printDsrTimestamp();
  cputs("\n");
}

void testOutputRegisters() {
  int tderrors = 0;
  cputs("\nTesting TDOUT...\n");
  enableTipi();
  for(int i = 0; i<=255; i++) {
    *TDOUT = i;
    unsigned char x = *TDOUT;
    if (x != i) {
      cputs("TDOUT error for value: ");
      cputs(uint2str(i));
      cputs(", found: ");
      cputs(uint2str(x));
      cputs("\n");
      tderrors++;
    }
  }
  disableTipi();

  int tcerrors = 0;
  cputs("\nTesting TCOUT...\n");
  enableTipi();
  for(int i = 0; i<=255; i++) {
    *TCOUT = i;
    unsigned char x = *TCOUT;
    if (x != i) {
      cputs("TCOUT error for value: ");
      cputs(uint2str(i));
      cputs(", found: ");
      cputs(uint2str(x));
      cputs("\n");
      tcerrors++;
    }
  }
  disableTipi();

  if (tderrors > 0) {
    cputs("\nErrors retaining value in TDOUT register\n");
  }
  if (tcerrors > 0) {
    cputs("\nErrors retaining value in TCOUT register\n");
  }
}

void testInputRegisters() {
}

void setupScreen() {
  set_text();
  charset();
  bgcolor(COLOR_CYAN);
  textcolor(COLOR_BLACK);
}

unsigned char pressAnyKey() {
  while( 1 ) {
    if (kbhit()) {
      unsigned char k = cgetc();
      return k;
    }
  }
}

void main()
{
  setupScreen();

  clrscr();
  gotoxy(0,23);
  cputs("TIPI Diagnostics\n\n");
  discoverCrubase();
  cputs("CRU base: ");
  cputs(uint2str(crubase));
  if (crubase == 0) {
    cputs("..error detecting TIPI\nset CRUBASE to default(0x1000)\n");
    cputs("press any key to continue");
    pressAnyKey();
    crubase = 0x1000;
  }
  cputs("\n");
  testROM();
  cputs("\nDoes date look good?");
  if (pressAnyKey() == 'Y') {
    testOutputRegisters();
    testInputRegisters();
  }

  cputs("testing complete...");
  pressAnyKey();
  __asm__("BLWP @0x0000");
}

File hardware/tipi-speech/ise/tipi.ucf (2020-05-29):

NET "led0" LOC = P52;

NET "crub<0>" LOC = P70;
NET "crub<1>" LOC = P71;
NET "crub<2>" LOC = P72;
NET "crub<3>" LOC = P73;

NET "db_dir" LOC = P33;
NET "db_en" LOC = P35;
NET "dsr_b0" LOC = P29;
NET "dsr_b1" LOC = P30;
NET "dsr_en" LOC = P61;

NET "sram_a0" LOC = P49;  //  Added for DRAM MSB A0 for TIPI-32K board only
NET "sram_en" LOC = P60;  //  Added for DRAM Enable for TIPI-32K board only

NET "r_clk" LOC = P22; NET "r_clk" BUFG = CLK; // GCK1
NET "r_cd" LOC = P02;
NET "r_dout" LOC = P07;
NET "r_le" LOC = P06;
NET "r_rt" LOC = P08;
NET "r_din" LOC = P04;
NET "r_reset" LOC = P03;

NET "ti_cruclk" LOC = P23; NET "ti_cruclk" BUFG = CLK; // GCK2
NET "ti_cruin" LOC = P01;
NET "ti_dbin" LOC = P82;
NET "ti_extint" LOC = P76;
NET "ti_memen" LOC = P99;
NET "ti_ph3" LOC = P27; NET "ti_ph3" BUFG = CLK; // GKC3
NET "ti_we" LOC = P94;

NET "ti_a<0>" LOC = P97;   // MSB
NET "ti_a<1>" LOC = P96;
NET "ti_a<2>" LOC = P93;
NET "ti_a<3>" LOC = P81;
NET "ti_a<4>" LOC = P80;
NET "ti_a<5>" LOC = P78;
NET "ti_a<6>" LOC = P95;
NET "ti_a<7>" LOC = P90;
NET "ti_a<8>" LOC = P86;
NET "ti_a<9>" LOC = P91;
NET "ti_a<10>" LOC = P77;
NET "ti_a<11>" LOC = P79;
NET "ti_a<12>" LOC = P85;
NET "ti_a<13>" LOC = P87;
NET "ti_a<14>" LOC = P89;
NET "ti_a<15>" LOC = P92;  //LSB

NET "tp_d<7>" LOC = P11;  //MSB	
NET "tp_d<6>" LOC = P12;
NET "tp_d<5>" LOC = P13;
NET "tp_d<4>" LOC = P15;
NET "tp_d<3>" LOC = P14;
NET "tp_d<2>" LOC = P16;
NET "tp_d<1>" LOC = P17;
NET "tp_d<0>" LOC = P18;  //LSB

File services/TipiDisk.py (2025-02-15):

import sys
import traceback
import logging
import time
import os
import errno
import traceback

from ti_files.ProgramImageFile import ProgramImageFile
from ti_files.FixedRecordFile import FixedRecordFile
from ti_files.VariableRecordFile import VariableRecordFile
from ti_files.VariableRecordFile import load_internal
from ti_files.CatalogFile import CatalogFile
from ti_files.CatalogFileTimestamps import CatalogFileTimestamps
from ti_files.NativeFile import NativeFile
from ti_files.BasicFile import BasicFile, basicSuffixes
from ti_files import ti_files
from array import array
from tipi.TipiMessage import TipiMessage
from tifloat import tifloat
from tinames import tinames
from tinames import NativeFlags
from Pab import *
from TipiConfig import TipiConfig

logger = logging.getLogger(__name__)

tipi_config = TipiConfig.instance()


class TipiDisk(object):
    def __init__(self, tipi_io):
        self.tipi_io = tipi_io
        self.openFiles = {}

    #
    # Entry point to process all disk pab requests.
    def handle(self, pab, filename):
        switcher = {
            0: self.handleOpen,
            1: self.handleClose,
            2: self.handleRead,
            3: self.handleWrite,
            4: self.handleRestore,
            5: self.handleLoad,
            6: self.handleSave,
            7: self.handleDelete,
            8: self.handleScratch,
            9: self.handleStatus,
        }
        handler = switcher.get(opcode(pab), self.handleNotSupported)
        handler(pab, filename)

    #
    # Utils
    #

    def handleNotSupported(self, pab, devname):
        logger.warn("Opcode not supported: " + str(opcode(pab)))
        self.sendErrorCode(EILLOP)

    def sendErrorCode(self, code):
        logger.exception("responding with error: " + str(code))
        # traceback.print_stack()
        self.sendSingleByte(code)

    def sendSuccess(self):
        logger.debug("responding with success!")
        self.sendSingleByte(SUCCESS)

    def sendSingleByte(self, byte):
        msg = bytearray(1)
        msg[0] = byte
        self.tipi_io.send(msg)

    def lvl3_not_found(self, devname):
        # if drive not mapped, then always pass
        # or if drive mapped, and error mode is PASS, then try other controllers
        if (not tinames.isDriveMapped(devname)) or (tipi_config.get('LVL3_NOT_FOUND') == 'PASS'):
            logger.info("(2) Passing to other controllers")
            self.sendErrorCode(EDVNAME)
        else:
            logger.info("(2) File Not Found")
            self.sendErrorCode(EFILERR)
        return

    def handleOpen(self, pab, devname):
        logger.info("Opcode 0 Open - %s", devname)
        logPab(pab)
        unix_name = tinames.devnameToLocal(devname)

        if unix_name is None:
            logger.info("(1) Passing to other controllers")
            self.sendErrorCode(EDVNAME)
            return

        logger.debug("  local file: " + unix_name)
        if mode(pab) == INPUT and not os.path.exists(unix_name):
            self.lvl3_not_found(devname)
            return

        if os.path.isdir(unix_name):
            try:
                if recordLength(pab) == 0 or recordLength(pab) == 146:
                    cat_file = CatalogFileTimestamps.load(unix_name, pab, devname)
                else:
                    cat_file = CatalogFile.load(unix_name, pab, devname)
                self.sendSuccess()
                self.tipi_io.send([cat_file.getRecordLength()])
                self.openFiles[unix_name] = cat_file
                return
            except Exception as e:
                self.sendErrorCode(EOPATTR)
                logger.exception("failed to open dir - %s", devname)
                return

        native_flags = tinames.nativeFlags(devname)

        if mode(pab) != OUTPUT and os.path.exists(unix_name):
            try:
                if ti_files.isTiFile(unix_name):
                    # check protect flag
                    if mode(pab) != INPUT:
                        fh = open(unix_name, "rb")
                        header = bytearray(fh.read())[:128]
                        if ti_files.isProtected(header):
                           self.sendErrorCode(EWPROT)
                           return

                    if recordType(pab) == FIXED:
                        open_file = FixedRecordFile.load(unix_name, pab)
                    else:
                        open_file = VariableRecordFile.load(unix_name, pab)
                else:
                    open_file = NativeFile.load(unix_name, pab, native_flags)

                if open_file is None:
                    self.sendErrorCode(EOPATTR)
                    return

                fillInRecordLen = open_file.getRecordLength()

                self.sendSuccess()
                self.tipi_io.send([fillInRecordLen])
                self.openFiles[unix_name] = open_file
                return

            except Exception as e:
                self.sendErrorCode(EOPATTR)
                logger.error("failed to open file - %s", devname)
                return
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

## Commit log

2017-01-09 Add a kicad drawing of our current interface.
    This, I believe is the hardware layout we tested Friday 2017/01/06, to work with the comm.py script.
    [tipi-interface.kicad_pcb, tipi-interface.sch]
2017-01-15 Update schematic to separate input from output.
    Separate gpio pins will be used on RPi. This should prevent needing to switch GPIO pin modes frequently, as well as disable reading what is output. Write port is 0x5FFF, read port is 0x5FEF.
    Still needs flow control signals, and a CRU enable bit.
    [tipi-interface.sch]
2017-01-18 Fix r2 read address in schematic comments to 5FFDh.
    [tipi-interface.sch]
2017-01-18 Update for control signalling.
    [tipi-interface.sch]
2017-01-18 Set appropriate RPi GPIO pin assignments.
    [tipi-interface.sch]
2017-01-21 Add CRU bit to enable/disable board.
    Use a 4 bit jumper header block to select nibble x in the address 1x00h. The bit responds at any and all addresses inclusively between 1x00h and 1xFFh. However the circuit should be programmed to bit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
    will be intendend for bank switch ROM.
    [tipi-interface.sch]
2017-01-22 Forcing permissions to match limits of ubuntu on windows
    [tipi-interface.kicad_pcb, tipi-interface.sch]
2017-01-22 Fix issue with cru addressing off by a bit.
    [tipi-interface.sch]
2017-01-22 fix fs perms
    [tipi-interface.sch]
2017-01-22 Fix dsr address match, add led debugging
2017-01-23 Tweaked pin assignements in schematic for interface.
    [tipi-interface.sch]
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2017-01-23 Update drawing with Raspberry PI pin assignments.
    See table in schematics/rpi-pinouts. BCM numbers are used to label in schematic.
    [tipi-interface.sch]
2017-01-26 removing Lucid code. didn't initially work, my syntax was wrong, and dff's create verilog errors
    [tipi.ucf]
2017-01-30 new schematic targing Xilinx CPLD
    [smd-tipi-interface.kicad_pcb, smd-tipi-interface.sch, tipi-interface.sch]
2017-02-01 fix dsr rom address maping in schematic
    [smd-tipi-interface.sch]
2017-02-03 Ea5loader (#8)
    * a file loading experiment - cart rom to load ea5 programs from TIPI
    * simple ea5 binary server ( doesn't support TIFILES or V9T9 ) must be raw for now.
    [fileserver.py, main.c]
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2017-02-11 reset board on powerup, maybe, need to test.
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2017-02-25 Fix tipisdev - sending device name to RPi
    Also added preproccessor option 'emulation' to skip blocking on hardware responses so debugging is possible in an emulator.
    I should never code while sick. Unitialized loop counters, incorrectly initialized source addresses... just bad.
2017-02-25 sends a status code back to TI if there is an issue with the PAB
    [fileserver.py]
2017-02-26 allow special test file names that return particular errors when accessed
    [fileserver.py]
2017-02-27 This code should work, but it is corrupting.
    Left a sleep(0.1) 1/10th of a second when waiting for instructions from the 4A.
    I am seeing that the 4A does not wait. Seems to be something fundamentally wrong
    with my DSR assembly code pattern.
    [fileserver.py]
2017-03-05 Trap file not found errors.
    [fileserver.py]
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2017-03-13 Fix import statement... damn you python.
    [fileserver.py]
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2017-03-19 list files in Tursi's crc15 format if they are long file names.
    Find files that match the long shortened form as well.
    [fileserver.py]
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2017-03-19 Nice, dir nav in DM2K, and fix opcode 5 filename mapping.
    [fileserver.py]
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2017-04-02 Fix a number of bugs in the hash/resend code.
    Fix name of Phash class
    Fix splitting of payloads perfectly divisible by chunk size
    Add diagnostic printouts.
    [fileserver.py]
2017-04-05 Read fixed length records & and systemd support.
    [fileserver.py]
2017-04-06 support TIPI.CLOCK DIS/FIX 24
    [Pab.py, SpecialFiles.py, fileserver.py]
2017-04-09 quick and dirty mouse support.
    bug: currently blocks TI-99/4A if mouse isn't moving.
    [RawExtensions.py, fileserver.py]
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2017-04-11 fix pointers to be anchored in corner.
    add screen limits.
    [main.c]
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2017-04-12 minor fixes cause I don't really know python. :)
    [ClockFile.py, SpecialFiles.py, StatusFile.py]
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2017-05-15 auto reset services when 4A title screen/powerup routine executes
2017-05-16 Some progress on schematic for xc9572xl 64 pin CPLD
    [tipi.sch]
2017-05-20 separate RESET service using python GPIO trigger.
    [fileserver.py]
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2017-05-26 dsr rom works, wired in RD & RC with issues
2017-05-27 Fix RC & RD.
    The naming convention I'm going for is that signals are named by
    the computers that this glue is binding. So signals from the TI start
    with ti_, and the name of the signal is then the name the TI gives it.
    For example ti_cru_out. It is an input to the glue logic, but it is
    and _out from the TI.
    So, now following this, I've fixed the signal names for the Raspberry PI.
    rpi_ _out, _in. in particular for the shift register sdata signals.
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2017-06-03 Let TI read the CRU bits register.
    Also change the FPGA over to LVTTL instead of LVCMOS33 for stability recommendations.
    Added phase 3 clock into circuit.
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2017-06-13 fixing the math on keeping the mouse from wrapping around the screen and going nuts
    [main.c]
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2017-06-25 Update target schematic
    and clean out some remnants.
    [smd-tipi-interface.kicad_pcb, smd-tipi-interface.sch, tipi-interface.kicad_pcb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]
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2017-06-25 change Raspberry PI connector to 2x5 and pins 31-40 on GPIO header.
    [tipi.sch]
2017-07-03 pcboard layout...
    ROM, sideport, CPLD, LED, JTAG mostly wired up.
    TODO: a few signals, RPI interface and power.
    [tipi.kicad_pcb, tipi.sch]
2017-07-03 Finished first pcboard layout/routing.
    Probably useless. Waiting on parts to perform footprint verification.
    And then need to resize the board to match my 32k board outline...
    that will be a little tight...
    [tipi.kicad_pcb, tipi.sch]
2017-07-08 Added pullups on JTAG inputs
    labelled powersupply caps.
    Added pad for spare RPi pin.
    checked drill sizes.
    touched up some gnd/power lines.
    [tipi.kicad_pcb, tipi.sch]
2017-07-09 Change board layout to align with 32k sideport card.
    [tipi.kicad_pcb]
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2017-07-13 all wired up, I think. Passes design rule check
    [tipi.kicad_pcb, tipi.sch]
2017-07-16 skeleton ise project to target xc9572xl chip
    required pcboard design change for crubase inputs.
    [tipi.kicad_pcb, tipi.sch]
2017-07-23 rework and fit to a xc95144xl 100 pin instead cause we need more logic blocks.
    [tipi.kicad_pcb, tipi.sch]
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2017-07-23 Add solder pads for some extra pins in case we need to learn something.
    [tipi.kicad_pcb, tipi.sch]
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2017-07-24 Cleanup, and chip name correction.
    [tipi.ucf]
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2017-09-02 swap the data lines back
    [tipi.sch]
2017-09-02 fix pin assignments in libtipi
    [fileserver.py]
2017-09-09 correct register wires for mux, and rename dev enable wire.
2017-09-10 helps if the pins are mapped correctly
    [tipi.ucf]
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2017-09-12 Unswizzle databus in the pcboard layout.
    Note: .ucf for cpld project will need pin assignment updates.
    [tipi.kicad_pcb, tipi.sch]
2017-09-17 rev 2 tipi sideport board, updated for kicad update, removed unproven gerbers
    [tipi.sch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]
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2017-09-18 automate creation of reversed.bin until new boards arrive.
2017-09-18 TI BASIC EOF function works for TIPI.STATUS
    requires rebuild of eprom (automated reversed.bin)
    [Pab.py, StatusFile.py]
2017-09-19 and fix it so it works again.
    [TipiDisk.py, TipiService.py]
2017-09-19 Properly error with EOF when reading off the end of a FiXED record file.
    [TipiDisk.py, TipiService.py]
2017-09-23 kicad work on peb card, added buffers, and ama-d decoding
    [tipi-peb.sch]
2017-09-24 Fixed and Catalog files work for read again.
    [TipiDisk.py]
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2017-10-06 Fix / remove strange dangling exception on stack.
    [TipiService.py]
2017-10-06 Fix saving BASIC to native file if using native suffix, and not already a TIFILES
    [TipiDisk.py]
2017-10-07 Add write support for Fixed Record files.
    [Pab.py]
2017-10-07 Restrict native data files to Var80 or Fixed128
    [TipiDisk.py]
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2017-10-08 Send success after write operations. correct some error codes.
    [TipiDisk.py]
2017-10-10 Fix data bus pin assignments for rev2 board.
    [tipi.ucf]
2017-10-19 Fixes to enable Wizards Doom to run from TIPI.
    [TipiDisk.py, TipiService.py, TipiSuper.py]
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2017-10-26 removed old webman and narrowed which things are in root.
    [tipi-peb.kicad_pcb, tipi-peb.sch, tipi.kicad_pcb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]
2017-10-27 Added a countdown timer for rebooting RPi, disabled menu options during reboot to avoid confusion. Added ability to create directories via web interface.
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2017-11-04 Hacky fix for changing the device name length.
    [CurlFile.py]
2017-11-11 Remove items that don't need to be on PI for release.
    [tipi-peb.kicad_pcb, tipi-peb.sch, tipi.kicad_pcb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]
2017-11-13 Correct error codes for not handling device, and expect DKSx mapping to be in TI terms.
    TI terms means folders separated by '.' instead of '/'
    and underneath tipi_disk.
    [TipiDisk.py]
2017-11-17 Fix missing Pab import
    [UpgradeFile.py]
2017-11-27 TIPI drive mapping and wifi config tool.
    Shows some status like version and ip address,
    and current drive mappings and wifi config.
    Allows editing drive mappings and wifi config.
    Works in Classic99 with alternative file names, but
    just crashes straight out on real hardware.
    [main.c]
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2017-11-30 wpa_cli reconfigure doesn't work reliably.
    reboot instead when wificonfig is set.
    [TipiSuper.py]
2017-11-30 Fix PI.HTTP access to files.
    [CurlFile.py]
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2017-12-23 add PI.SHUTDOWN, and PI.REBOOT handlers
    [RebootFile.py, ShutdownFile.py, SpecialFiles.py]
2017-12-24 add halt and reboot options to tipicfg
    [main.c]
2017-12-25 Fix URI drive request detection
    [SpecialFiles.py]
2017-12-25 set volume name to the directory the drive is mapped to.
    fixes #66
    [TipiDisk.py]
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2018-01-02 Fix trashing the GPLWS when using ROM routines
    [main.c]
2018-01-04 Fix pab/recordnumber autoincrementing on PI side
    [TipiDisk.py]
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2018-01-12 refactored, broke a ton, fixed a few things... basic detection is faster...
    [TipiDisk.py]
2018-01-15 broke files apart, separating routes, from tipi logic, styling, using dbcache... way too much, still not all back together.
    [TipiConfig.py]
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2018-02-01 Allows using the TipiVariables interface from level 3 file io.
    open PI.VARS, write (print) command to the file, it will execute.
    read a line from the file after the write, to retrieve the response.
    If no command was issued, the read will produce a file err.
    [SpecialFiles.py, VariablesFile.py]
2018-02-02 Changes for github issue #83 "TipiVariables RUN folder shouldn't be in source control":
    Changed runtime directory to be .tipivars
    .tipivars dir gets auto-created if not present.
    Removed RUN and contents from source control.
    Made an if/elif case defined as mutually exclusive.
    [TipiVariable.py]
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2018-02-13 Updates to TIPICFG
    Add spinner during reBoot, and status reload after fixed delay.
    Add left and right arrow editing support.
    Editing resumes at end of entry.
    F3 deletes from cursor to end of line.
    F1 deletes a characeter.
    left arrow/backspace is non-destructive.
    FIXED upgrade detection.
    [main.c]
2018-02-19 better error handling, instead of a hang when performing direct read on non TIFILES file
    [LevelTwo.py]
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2018-03-02 A few messaging fixes and the beginning of TiSocket TELNET client.
    [main.c]
2018-03-05 fix error sending 1 too many bytes, and translate terminal nav keys
    [main.c]
2018-03-09 Added support for a "RS" action, which means "READ SIMPLE". This is for easier reading of TipiVars in BASIC. This is accomplished by returning just the variable's value to BASIC instead of in the for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
    [TipiVariable.py]
2018-03-09 Restored a couple of lines I inadvertently removed, causing a problem for returned arrays.
    [TipiVariable.py]
2018-03-22 Fix mousedemo to not be a cartridge. and understand FCTNQUIT
    [main.c]
2018-03-25 add level 2 >16 routine, powerup fixes, and CALL FILES, if CRUBASE is >1100
2018-03-29 reset VDP better when going back to screen mode selection
    [main.c]
2018-03-30 fix current location query
    [main.c]
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2018-04-12 Only press the space on release of middle mouse button
    So that we don't issue dozens of them.
2018-04-14 Remove bad / false / wrong documentation
    There was documentation from the original MECH/S mouse driver that said it was called with a BLWP, but this was grossly incorrect.
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2018-04-17 Fix error reporting on opening directory, add long name catalog
    [Pab.py, TipiDisk.py, TipiService.py]
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2018-04-22 drc says it is good, status bar says 2 unconnected
    [tipi-peb.kicad_pcb]
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2018-05-02 Fix issues writing records from assembler of EA
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2018-05-08 fixed delete in tipicfg
    [main.c]
2018-05-31 Fix to work on 4A.
    Jumper added to disconnect SCLK/AMD line on 4As.
    Pull-up resister added to boost power on r_din transmission line.
    [tipi-peb.kicad_pcb, tipi-peb.sch]
2018-06-02 Add solder jumpers for genmod vs standard support.
    [tipi-peb.kicad_pcb, tipi-peb.sch]
2018-06-03 Changes to accommodate 2 more key/val pairs to be passed in, stored, and optionally xmitted. Also added a check to avoid storing empty vars.
    [TipiVariable.py]
2018-06-05 some upgrade process fixes.
    [main.c]
2018-06-05 fix to read volatile so compiler actually reads from hardware when I want it to.
    [main.c]
2018-06-06 allow upgrade to be forced with FCTN-U.
    Fix it so 'u' doesn't upgrade if no upgrade is detected.
    But then also allow FCTN-u to run the upgrade process regardless.
    [main.c]
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2018-06-23 Remove the TIPI beeps.
    This interferes with powerup on Geneve, and with Omega's DOS cartridge.
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2018-07-21 Fix status operation for unopened files.
    [TipiDisk.py]
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2018-08-12 fix skipping to real drive if not mapped for save opcode
    [LevelTwo.py, TipiDisk.py]
2018-08-12 allow cascade for level 2, but... nothing really works with it. Stop erroring and locking up
    [LevelTwo.py]
2018-08-13 fix crash on create dir due to oled logging
    [LevelTwo.py]
2018-08-18 Fix 1 byte tool long when copied tipi to tipi.
    Also, tuned down the logging.
    [LevelTwo.py, TiSocket.py, TipiService.py]
2018-08-21 fix a hang on missing file
    [LevelTwo.py, TipiDisk.py]
2018-11-01 fix status/eof support for PI.HTTP from BASIC
    [CurlFile.py]
2018-11-23 fix to make AUTO=on actually work
    [TipiConfig.py, TipiDisk.py]
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2018-12-29 don't crash if someone tries to direct input a directory
    [LevelTwo.py]
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2019-02-21 Fix DSK handling for status and open
    [TipiDisk.py]
2019-03-17 fix crash if someone makes a directory called TIPI
    [TipiDisk.py]
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2019-05-11 Fix Native file restore and status
    [CurlFile.py]
2019-05-23 reload project under newer kicad, export bom: tipi-peb.xml
    [tipi-peb-2019-05-22-19-52-16.sch]
2019-06-07 read when socket is not open will now return empty array.
    0 length array, instead of ambiguous error code.
    closes #111
    [TiSocket.py]
2019-11-04 missed shutdown call before closing socket
    [TiSocket.py]
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2020-01-01 auto-convert to PDF
    printing_setup adds a share for final PDFS
    this is where print results end up.
    There are still some issues with detecting end of page
    Mostly untested
    [PioFile.py]
2020-01-02 fix last record check
    [PioFile.py]
2020-01-02 recover spool file after TIPI services reset
    [PioFile.py]
2020-01-02 reset-resume not using correct spool path
    [PioFile.py]
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2020-02-01 fix issue with direct-write if folder with same name is in the way
    [LevelTwo.py]
2020-02-01 noisy error handling in business as usual case
    [TipiDisk.py]
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2020-03-08 release ver for socket and vol fixes
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2020-04-19 more robust server socket error handling
    [TcpFile.py, TiSocket.py]
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2020-05-08 Adding VS-TIPI
    Created hardware directory with layout, CPLD and manufacturing files for the Speech Synthsizer version of the TIPI board. version V0.
    [10-Pin Shrouded Header (IDC) Straight.stp, 100-TQFP.step, 10118194c.stp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]
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2020-05-20 results of loading in new version of kicad
    [tipi.kicad_pcb, tipi.sch]
2020-05-25 TIPI-32K V1 HW and CPLD update
    V1 hardware and CPLD updates to add power tap and make RAM disableable.
    [VS-Tipi-BOM-JLCSMT-V0.xls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]
2020-05-25 TIPI-32K V1 HW and CPLD Updates
    HW changes to add Power tap and CPLD changes to enable RAM disable.
    [TIPI-32K-SS-BOM-V1.xls, tipi-BOM-V1.xls]
2020-05-26 fix noisy exception on safepoint
    [TipiService.py]
2020-05-26 prevent setting path to bad paths
    [LevelTwo.py]
2020-05-26 release a couple small error handling fixes
2020-06-07 fix error handling on socket open
    [TiSocket.py]
2020-06-07 Fix error handling for failure to open socket
    [TiSocket.py]
2020-06-10 Syntax fixes for Python3
    [LevelTwo.py, PioFile.py, TcpFile.py]
2020-06-12 fix import nonsense, and class of statics.. fix Status version checking
    [CurlFile.py, LevelTwo.py, Status.py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]
2020-06-13 fix service that handles reboot, shutdown, upgrade... fix native and web file access.
    [SpecialFiles.py, TipiSuper.py]
2020-06-13 fix basic text to PROGRAM conversion and LVL3 server socket access
    [TcpFile.py, TiSocket.py]
2020-06-13 fix printing to pdf
    [PioFile.py]
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2020-06-16 switch to python3 updates for xdt99
    and fix unused hash-bang in service scripts
    [TipiService.py, TipiSuper.py, TipiWatchDogService.py]
2020-06-23 fix mfm track to sector dump conversion
2020-06-26 TIPI/32K V2 PCB and V3 CPLD updates
    This update is PCB manufacturability improvements (Via to trace increase and R7 moved to topside) and V3 CPLD changes to support RAM disable without CRU Address changes.
    [TIPI-32K-SS-BOM-V1.xls, TIPI-32K-V2-BOM-JLCSMT.xls, TIPI-32K-V2-BOM.xls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]
2020-06-28 use /home/tipi/.js99er file existance as flag
    and a python3 fix
    disable PDF conversion but still capture to /tmp/print_*prn
    [PioFile.py, TipiService.py]
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2020-06-29 Fix uri substring code
    fix issue #128
    [SpecialFiles.py]
2020-06-29 fix a couple update bits around git submodule support
2020-07-03 Maybe fix clients like Chatti
    [TipiVariable.py]
2020-07-03 fix client connection for PI.TCP= opening
    [TcpFile.py]
2020-07-08 correct way to read crubase
    [main.c]
2020-07-10 Fix emulated mouse buttons PS/2 protocol
2020-07-12 fix so reload detect crubase changes
    [main.c]
2020-07-12 fix SNEK
    some programs used >127 characters so encoding of the strings needed
    to be latin1 not ascii. (ascii is just 0-127)
    [TipiVariable.py]
2020-07-26 fix reboot after lib refactoring
    [RebootFile.py]
2020-09-22 fix PI.PIO setup mistake
    I manually cloned the PrinterToPDF repo, consequently the old
    post-upgrade.sh would skip building it... This change, triggers on
    the build artifact, not just the directory
2020-10-05 fix trailing whitespace in names
    [TipiDisk.py]
2020-11-04 release a couple fixes
2020-11-07 fix version detection in TIPICFG
    [main.c]
2020-12-25 fix ascii encoding that should be 0-255 via latin1
    [LevelTwo.py, StatusFile.py, TipiService.py]
2020-12-27 fix setPATH to not expect unit 0 to be mapped, and not care about old path existing.
    [LevelTwo.py]
2020-12-27 fix issue with status operation on un-opened file
    python3 conversion issue.
    fixes issue #143
    [Status.py, StatusFile.py]
2020-12-27 a couple fixes for release
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2021-01-10 fix wifi config from TIPICFG
    [TipiSuper.py]
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2021-02-14 fix PI.PIO hang on write if not open
    [PioFile.py]
2021-02-24 fixed record files should use the record number
    from the pab, most of the time.
    [CurlFile.py]
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2021-04-13 wait loop in powerup to very restart
    Send the 0xF1 ack message
    Wait a bit to see if we get it back. But don't wait forever.
    Then reset the TipiService via cru pulse.
    Then, wait for RCIN to be 0x00 before returning to console
    powerup sequence.
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2021-08-02 detect error posting to PI.HTTP
    [CurlFile.py]
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2022-01-20 fix for multple incoming client sockets
    handleAccept would hang if id 1 was used already. It should
    have incremented the id and tried 2, 3, etc..
    [TiSocket.py]
2022-03-10 websocket: fix socket failure check
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2022-03-16 fix header during rename, limit dio to sectors
    [LevelTwo.py]
2022-03-19 fix end limit check on directInput/Output
    [LevelTwo.py]
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2022-04-10 fix wiringPi dependency
2022-05-06 fix error handling from DSR
    [TcpFile.py, UdpFile.py]
2022-07-24 fix unmapped error handling
    [LevelTwo.py]
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2022-10-16 allow multple usb devices
    Now mounts as USB0 USB1 etc..
    remove reboot
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2023-01-29 temporary while figuring out edge detection
    On the Le Potato, the kernel module didn't enable
    the edge detection control file... hmmm
    [TipiWatchDogService.py]
2023-01-29 my aarch64 fix for PrinterToPDF was accepted
2023-02-12 hot poll if no interrupt is available on tipi-reset
    [TipiWatchDogService.py]
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2023-04-01 fix PI.HTTP urls with query parameters
    [CurlFile.py]
2023-04-08 rudimentory json parsing via file interface
    open a file with the ?J native format override, such as:
    `TIPI.?J.JSONDATA` or `PI.?J.https://jokeoftheday.org`
    and TIPI will return a dynamic file that can be queried.
    write a record with a JMESPath query string, and the record
    set for the dynamic file will be reset to just that of the
    results of the query.
    Still needs some TI-99 cleanup
    [CurlFile.py]
2023-04-08 allow ?J native flag on PI.HTTP curlfiles
    - add error handling
    - delegate write operation to open_file type
    - allow the flag and pass it through for CurlFile
    [CurlFile.py, SpecialFiles.py]
2023-04-22 - allow opening PI.CONFIG with record length of 80 - 254 - fix transformation of NATIVE_TEXT_DIRS to be relative to TIPI.
    [ConfigFile.py]
2023-04-24 fix corner case where user has a directory named TIPI
    [TipiConfig.py]
2023-04-30 - copy from TIFILE to native text dir results in native text file. - catalog shows native files as DV80 if in a native text dir. - fixup some place that should respect the pre-existing TIFILES file.
    [LevelTwo.py]
2023-05-01 remove unnecessary and wrong bytes to block to bytes calculation
    tweak the logging on error to be less cryptic
    [LevelTwo.py]
2023-05-04 allow direct-input of native DIS/FIX 128 files
    which implies that they can be copied from TIPI to
    other media.
    [LevelTwo.py]
2023-05-06 fix URIx and ?J usage
    [SpecialFiles.py]
2023-05-06 fix protect, and error nicely when unsupported for native files
    [LevelTwo.py]
2023-05-06 fix block rounding for direct-input again.
    [LevelTwo.py]
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2023-07-29 fix F3 to erase line, instead of to end of line
    [main.c]
2023-08-20 fix interrupt on reset signal
    [TipiWatchDogService.py]
2023-09-03 fix track count assumption, stub 16 sec/track
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2023-11-04 allow scratch record for Fixed Record files
    [TipiDisk.py]
2024-05-10 no need to mount if we are just going to reboot
2024-06-19 4.1
    - fix web-ui log viewing
    - fix setting WiFi from PI.CONFIG ( TIPICFG )
    - delegates to raspi-config noint
    - retries upto 5 times cause networks can be elusive
    - can edit the SSID in TIPICFG, to the same value, and will re-submit
    when 'W'rite is requested.
    - network must be present to or internal NetworkManager config is not
    created.
    [TipiConfig.py, TipiSuper.py]
2024-12-30 error on file not found
    [TipiConfig.py, TipiDisk.py]
2024-12-30 on file not found, default to ERROR
    [TipiConfig.py]
2025-02-15 Fix file not found behavior
    If lvl3_not_found config item is set to ERROR
    when drive is not mapped, pass to other controller
    when drive is mapped, error
    If lvl3_not_found config item is set to PASS
    when drive is not mapped, pass to other controler
    when drive is mapped, also pass to other controller
    [TipiDisk.py]
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2025-08-27 Fix TI BASIC Editor font color, fix 'Save and Exit' editor button

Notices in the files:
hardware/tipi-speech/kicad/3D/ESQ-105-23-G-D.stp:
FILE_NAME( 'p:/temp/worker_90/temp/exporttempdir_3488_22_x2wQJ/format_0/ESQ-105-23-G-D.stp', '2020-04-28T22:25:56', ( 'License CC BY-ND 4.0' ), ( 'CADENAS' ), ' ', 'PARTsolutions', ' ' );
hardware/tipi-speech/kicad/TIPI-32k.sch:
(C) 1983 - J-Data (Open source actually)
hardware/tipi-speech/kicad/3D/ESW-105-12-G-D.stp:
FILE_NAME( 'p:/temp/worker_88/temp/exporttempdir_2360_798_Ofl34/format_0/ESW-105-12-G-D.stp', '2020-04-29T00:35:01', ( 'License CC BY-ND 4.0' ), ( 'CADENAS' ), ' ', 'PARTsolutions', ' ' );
